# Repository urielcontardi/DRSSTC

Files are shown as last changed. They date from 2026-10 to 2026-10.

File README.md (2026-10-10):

# oneTeslaTS — esquemático da placa principal

Abra `oneTesla.kicad_pro` no KiCad 10 e depois o editor de esquemas, ou abra diretamente `oneTesla.kicad_sch`. A folha A3 contém a placa principal completa, organizada em cinco blocos compactos. Os capacitores de desacoplamento ficam junto aos respectivos CIs; referências e valores usam fonte de 1,27 mm, espaçamento de 2,54 mm e alinhamento consistente. Os valores visíveis foram abreviados (por exemplo, `3R3`, `1u` e `100u 25V`); encapsulamentos e observações de montagem permanecem nos campos dos componentes. O UCC37321P usa um bloco retangular com entradas à esquerda, saídas à direita e alimentação/terra acima e abaixo. Para visualizar sem o KiCad, use `output/oneTesla-schematic.pdf`.

O esquema tem 41 referências físicas: IC1–IC4, IC6, FB1, T1, T3, R1–R6, C1–C6, C8–C13, CPR1, D1, D2, D4, Q1–Q2, Z1–Z2, F1, J110, J1, J2, P1, P2 e PS1. A fonte auxiliar original com transformador (T2 + D3 + IC5/78L15 + C7) foi substituída pelo módulo AC/DC **PS1 (HLK-15M15BL, 15V/1A)**, com C13 na saída de 15V; C10 passou a filtrar o rail de 15V e IC6 (78L05) é alimentado por +15V. Z1/Z2 são TVS opcionais, marcados como DNP. J1 corresponde ao J_AC do original; o nome foi adaptado para a anotação do KiCad. J2 representa explicitamente a ligação de proteção PE/chassis que aparece no layout. A placa do SD interrupter externo não faz parte desta etapa. O layout do PCB está documentado na seção **PCB** abaixo.

Todos os símbolos e footprints usados são locais, em `library/oneTesla.kicad_sym` e `library/oneTesla.pretty`. Não é preciso instalar bibliotecas adicionais. Os arquivos SOP existentes foram preservados; IC1 e IC2 foram associados a DIP-14 com soquete, e IC3/IC4 a DIP-8 com soquete, conforme o manual e o layout.

## Referências e decisões

- `misc/schematic_ref.png`: conexões do CT, diodas de proteção, Schmitt triggers, flip-flop, drivers, GDT e meia ponte.
- `misc/layout_ref.png`: encapsulamentos, referências, alimentação e componentes que não aparecem na imagem parcial do esquema.
- `misc/oneTeslaTS_User_Manual.pdf`, páginas 17–23 do arquivo, etapas 4–7: valores, orientação de montagem, alimentação e TVS opcionais. A página 48 identifica o FGA60N65SMD.
- `misc/oneTeslaTS_Parts.pdf`: quantidades, R1 de 1k/5W, resistores bleeder de 100k/0,5W e fusível de 4A. A serigrafia antiga cita 10A; o esquema usa os 4A da lista do kit.
- [TI UCC37321, SLUS504I](https://www.ti.com/lit/ds/symlink/ucc37321.pdf): alimentação 1/8, terra 4/5, enable 3 e saídas 6/7. Os pinos 6/7 foram ligados externamente. O pino 7 mantém o tipo `output`; o 6 é `passive`, pois ambos são pernas da mesma saída. Isso permite ERC sem desabilitar a regra de curtos entre saídas distintas.
- [onsemi FGA60N65SMD](https://www.onsemi.com/pdf/datasheet/fga60n65smd-d.pdf): TO-3P, G1/C2/E3. Footprint horizontal, aba para baixo, passo 5,45mm.
- [Broadcom HFBR-0500ETZ, AV02-3283EN](https://docs.broadcom.com/doc/AV02-3283EN): selecionado HFBR-2521ETZ com OUT1/GND2/VCC3/RL4. RL está em +5V para usar o pull-up interno. Os pinos de retenção 5/8 estão NC conforme essa variante. A cópia local do footprint corrige a numeração do segundo pino de retenção de 6 para 8.

A fonte auxiliar era, na placa original, T2 -> D3 -> C10 -> RAW_DC (+24V), com IC5 (78L15) gerando +15V e IC6 (78L05) gerando +5V. Nesta revisão ela usa o módulo **HLK-15M15BL**: rede AC (pós-fusível, /AC_L_FUSED e /AC_N) -> PS1 -> +15V (C13/C10) -> IC6 (78L05) -> +5V. O rail RAW_DC e o regulador de 15V deixaram de existir.

J110 liga AC_N a DC_MID: fechado para a configuração dobradora de 110V, aberto para 220V. O módulo HLK aceita 85–265VAC, então a mesma placa atende ambas as tensões de rede. A derivação para PS1 fica depois do fusível (topologia /AC_L -> F1 -> /AC_L_FUSED), diferente da placa original, onde o fusível vinha depois da derivação para T2.

GND da fonte isolada, DC_MINUS do barramento de potência e PE são três redes distintas. P1/P2 recebem a bobina primária externa, em série com CPR1 de 68nF/3kV. O fio do primário atravessa o núcleo de T3; os dois pads de T3 são apenas o secundário do CT.

T1 tem pontos de fase nos pinos **1, 3 e 6**: os dois secundários devem gerar tensões gate/emitter opostas. A numeração física e os pares de enrolamentos ainda devem ser confirmados no transformador real. O ERC não verifica polaridade magnética.

## Footprints e pendências

Cada componente tem os campos `Footprint_Status` e, quando necessário, `Assembly_Notes`. A lista completa está em `output/components.csv`.

| Componentes | Situação |
| --- | --- |
| IC1/IC2 | DIP-14, fileiras 7,62mm e passo 2,54mm; soquete conforme original. |
| IC3/IC4 | UCC37321P em DIP-8, fileiras 7,62mm e passo 2,54mm; soquete conforme original. |
| Q1/Q2 | TO-3P-3 horizontal, passo 5,45mm e pinagem do FGA60N65SMD; conferir altura das pernas dobradas em relação ao dissipador. |
| D1/D2 | 1N4148 DO-35 THT; passo selecionado 7,62mm. |
| IC5/IC6 | 78L15/78L05 TO-92, OUT1/GND2/IN3; conferir fabricante/sufixo antes de comprar. |
| FB1 | HFBR-2521ETZ selecionado; conferir o receptor real. Outras variantes HFBR/AFBR podem diferir no pino 4 e nos pinos de retenção. |
| R1–R6, C1–C10, Z1/Z2 | Footprints THT padronizados selecionados; conferir corpo, passo, tensão e potência das peças adquiridas. |
| C11/C12 | 1000uF, tensão nominal selecionada de pelo menos 200V; snap-in D30/P10 proposto. Confirmar diâmetro, passo e altura. |
| D3/D4 | DF005M DIP-4 / KBU6G linear selecionados por formato e especificações da lista; confirmar os códigos reais e a ordem dos terminais. |
| F1 | Clipes 5x20mm selecionados; confirmar o modelo dos clipes e os passos de seus furos. |
| T1/T2/T3 | Footprints personalizados **provisórios**, estimados do layout. Confirmar dimensões, pares de pinos, tensão e fase com as peças. |
| J1/P1/P2/J110/J2 | IEC, terminais e ligação PE com geometria proposta; conferir modelos, fixações, furos e numeração. |
| CPR1 | Footprint personalizado **provisório**, CDE 940C30S68K-F, passo selecionado 57,5mm. Confirmar desenho mecânico da peça. |

A existência de todos os footprints e a correspondência entre números dos pinos e dos pads foram verificadas. Isso **não confirma medidas físicas de peças não identificadas**. Os footprints marcados `CONFIRMAR` e os modelos selecionados da tabela precisam dessa conferência antes de usar o projeto para fabricar uma placa.

## Componentes de alimentação adicionados

Disponíveis no seletor de símbolos da biblioteca local `oneTesla`, com footprint associado:

| Símbolo | Footprint local | Pinagem |
| --- | --- | --- |
| `oneTesla:HLK-15M15BL` | `oneTesla:HLK-15M15BL` | 1/2 AC, 3 −Vo, 4 +Vo; saída 15V/1A. |
| `oneTesla:MUR460C` | `oneTesla:D_SMC` | SMC/DO-214AB; 1 cátodo, 2 ânodo. |
| `oneTesla:SMBJ18A` | `oneTesla:D_SMB` | SMB/DO-214AA; TVS **unidirecional**, 1 cátodo, 2 ânodo. |
| `oneTesla:1N5819` | `oneTesla:D_SMA` | Versão SMD SMA/DO-214AC; Schottky, 1 cátodo, 2 ânodo. |

O HLK segue a página 11 do [datasheet Hi-Link 15W-BL V1.0](misc/HLK-15W-BL_V1.0.pdf), disponibilizado na [página do componente na LCSC](https://www.lcsc.com/product-detail/C53122331.html). O desenho do fabricante usa **47,5 × 28,5 × 22mm como referência do módulo com caixa da mesma série**. O footprint reserva esse envelope para a versão BL de placa aberta; inclui serigrafia, contorno de fabricação, courtyard e indicação do pino 1. Furos de 1,1mm conforme o desenho, para terminais de 0,8mm ±0,2mm; pads de 2,5mm são uma escolha de layout. O courtyard tem margem de 1mm em torno do envelope nominal.

Coordenadas dos pads em mm, **vista superior da PCB**, com origem no pino 1:

| Pad | X | Y | Função |
| --- | --- | --- | --- |
| 1 | 0 | 0 | AC |
| 2 | 0 | 7,8 | AC |
| 3 | 42,5 | −7,4 | −Vo |
| 4 | 42,5 | 15,2 | +Vo |

São 42,5mm entre colunas, 7,8mm entre os terminais AC e 22,6mm entre os terminais DC. O fabricante informa tolerância de **±1mm nas dimensões e no espaçamento dos pinos** e pede conferência com a peça real antes de desenhar a placa; conferir especialmente a furação antes de fabricar.

Os três footprints SMD são cópias dos padrões do KiCad 10, com faixa de cátodo junto ao pad 1. Referências: [MUR460C World, SMC/4A/600V](https://www.worldgj.com/uploads/file/20251222/988858e88ba65bb483179d9af14a7299.pdf), [SMBJ18A AOS, SMB/18V/600W](https://www.aosmd.com/products/tvs/high-power-tvs/smbj18a), [1N5819 KEXIN, SMA/1A/40V](https://datasheet.lcsc.com/lcsc/1912111437_KEXIN-1N5819_C437199.pdf). Conferir o encapsulamento do fornecedor escolhido. O SMBJ18A usa o gráfico de TVS unidirecional; não o de TVS bidirecional dos componentes com sufixo CA.

Pré-visualizações SVG dos quatro símbolos e footprints, exportadas pelo KiCad, e conferência de pinos/pads estão em `output/power-components/`. O gerador do esquema inicial preserva esses quatro símbolos ao recriar a biblioteca.

## Verificação

`output/validation.txt` contém o resultado; `output/erc.json` é o relatório nativo do KiCad. A verificação cobre 20 redes de referência e sete conexões diretas, entradas/saídas livres, separação dos três domínios, todas as unidades dos CIs e correspondência completa dos pinos/pads. O ERC termina com **2 notas esperadas**: `power_pin_not_driven` nos pinos 1/2 do PS1 — os pinos AC do módulo HLK são `power_input` e a rede AC não tem pino `power_output` dirigindo; é inerente à troca pelo módulo e não indica erro de conexão.

Para repetir as verificações depois de editar o esquema:

```sh
kicad-cli sch export netlist oneTesla.kicad_sch -o output/oneTesla.net
kicad-cli sch erc oneTesla.kicad_sch -o output/erc.json --format json
python3 scripts/validate_schematic.py
kicad-cli sch export pdf oneTesla.kicad_sch -o output/oneTesla-schematic.pdf
```

`python3 scripts/build_schematic.py` recria o esquema inicial desta entrega e as bibliotecas locais, **sobrescrevendo edições posteriores nesses arquivos**; não o execute para apenas validar. O esquema anterior a esta reconstrução permanece no histórico do git.

## PCB

`oneTesla.kicad_pcb` é uma **réplica de 2 camadas** da placa driver original do oneTeslaTS, adaptada ao esquemático atual (fonte HLK, PE separado, PRE/CLR do 74HCT74 em +5V). A geometria vem dos arquivos Eagle originais publicados pelo autor (`misc/driver.brd`, de [bayley/oneteslats](https://github.com/bayley/oneteslats)): posições e rotações dos componentes, trilhas, vias, pours, outline (106,045 × 106,045 mm), furos e a serigrafia vetorial (logo oneTeslaTS, avisos) foram importados diretamente do `.brd`. As redes do cobre original foram reatribuídas às redes do esquemático atual via os contactrefs (pino a pino); o alinhamento de cada footprint foi verificado automaticamente (pad contra pad, rede contra rede, desvio máximo 0,04 mm).

**Adaptações em relação à placa original**

- Fonte auxiliar: T2, D3, IC5 (78L15) e C7 removidos com o cobre associado (+24V, AUX_AC1/2 e o ramal GND/PE da área). **PS1 (HLK-15M15BL)** ocupa o antigo lugar do T2, com os pinos AC à direita; C13 ocupa o antigo lugar de C7 (cada pad no seu pour: +15V e GND). Roteamento novo: /AC_L_FUSED e /AC_N até o PS1, +15V do PS1.4 subindo pela borda esquerda até C10/IC6.3 e ao pour dos drivers, GND do PS1.3 ao pour lógico.
- **PE separado de GND**: o fio original IEC.G→GND e o pad de canto superior direito foram separados; J2 (Chassis_PE_M3) fica no pad de canto (era o ponto de aterramento original) e um fio /PE novo liga J1.3 ao J2. O standoff U$13 (co-localizado com J2) foi omitido.
- **Primário**: P1 (pad direito, como na serigrafia original) = nó CPR1.2; P2 (pad esquerdo) = /DC_MID. Os anéis JPRT originais foram mantidos como terminais (JPRT1 em /DC_MID, JPRT2 no nó CPR1.2). As trilhas de fundo entre P1/P2/CPR1/JPRT foram refeitas para a nova topologia (o fio SW_NODE da CPR1.1 foi preservado; um salto por vias leva /DC_MID de P2 ao anel).
- **74HCT74**: na placa original, os pinos 10 e 13 (PRE/CLR) estavam em GND; no esquemático atual estão em +5V — dois links novos ligam IC2.13 e IC2.10 à rede de +5V.
- **Fusível**: as garras internas (tangs) ganharam jumpers do mesmo net dos clipes (na original eram ilhas sem net).
- GND de T3 confirmado no ramal original do CT; IC6.2 ligado por fio ao C9.2 (o bolsão do pour ficava isolado).

**Footprints**: a biblioteca local foi alinhada à geometria comprovada da placa original (`scripts/pcb_patch_footprints.py`): passos/posições de pads de R1, R5/R6, C8/C9/C10/C13, C11/C12, Z1/Z2, CPR1, T1 (GDT), FB1, J1 (IEC), F1 (ordem dos clipes), D4 (ordem dos pinos AC), P1/P2, J110, IC6 (TO-92 triangular), DIP-8/DIP-14 (pads padrão 1,6 mm, não long pads), furos NPTH de retenção do FB1 e do TO-3P. As notas `CONFIRMAR`/`PROVISORIO` continuam valendo — os footprints espelham a placa original, o que não confirma as peças compradas.

**Verificação do PCB** (`output/drc.json`): **0 itens não conectados**. Restam, por escolha consciente: `hole_clearance` ×2 e `copper_edge_clearance` ×1 presentes na geometria original (trilha /AC_L sobre o furo do IEC, trilha /OPTICAL_OUT junto ao furo de retenção, pad J2 a 0,2 mm da borda); 3 ilhas same-net no pour SW_NODE (slivers que o preenchimento original também gera); e ruído cosmético esperado (silk sobre cobre nos logos, courtyards sobrepostos, `lib_footprint_mismatch` por os footprints embutidos levarem Reference/Value reais).

**Mecânico — conferir antes de fabricar**: o envelope do HLK no footprint é o da série com caixa (47,5 × 28,5 mm); na posição atual a lateral do módulo fica a ~0,2 mm dos pads de solda do conector IEC. Medir o módulo BL real (provavelmente ~44 × 24 mm) e, se necessário, deslocar PS1 ~1 mm para dentro. A versão BL de placa aberta não deve ultrapassar os pads do IEC.

**Regenerar o PCB do zero** (sobrescreve `oneTesla.kicad_pcb`):

```sh
python3 scripts/pcb_patch_footprints.py   # alinha a biblioteca à geometria original
python3 scripts/pcb_extract.py            # componentes/redes do esquemático -> output/pcb-data.json
python3 scripts/build_pcb.py              # gera o .kicad_pcb (placement verificado + cobre)
/Applications/KiCad/KiCad.app/Contents/Frameworks/Python.framework/Versions/Current/bin/python3 scripts/pcb_refill.py oneTesla.kicad_pcb
kicad-cli pcb drc oneTesla.kicad_pcb -o output/drc.json --format json
```

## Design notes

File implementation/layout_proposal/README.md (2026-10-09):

# Estudo de posicionamento — NÃO fabricar

Este diretório contém uma proposta mecânica **não roteada** para a placa `oneTesla`. A fonte de produção continua sendo `../../oneTesla.kicad_pcb`, sem alterações neste commit. Não exportar Gerbers do estudo nem energizá-lo.

## Entregáveis

- `placement-study.kicad_pcb`: 19 footprints reposicionados e contorno expandido de modo provisório para `(-7,-18)` a `(185,155)` mm. A topologia dos pads no arquivo e os segmentos/vias originais foram preservados; as trilhas **não acompanharam** os pads movidos.
- `assembly.png`: inspeção visual do novo agrupamento. O arquivo do PCB, não a imagem, é a referência geométrica.
- `placement_study.py`: geração reproduzível a partir da fonte da raiz. O script restaura explicitamente as redes serializadas das trilhas por UUID após salvar, pois o pcbnew 10 reassocia sete delas ao mover footprints.
- `drc-placement-study.json`: DRC nativo do KiCad 10.0.6 com paridade, todas as severidades, erros de trilha e refill de zonas, usando cópia do esquema, projeto e bibliotecas locais. A execução do DRC não salvou o PCB do estudo.

## Resultado verificado

| Checagem | Fonte atual | Estudo |
|---|---:|---:|
| Footprints/pads | 48 / 142 | 48 / 142 |
| Segmentos e vias / zonas | 220 / 6 | 220 / 6 |
| Courtyards sobrepostos no DRC | 22 | 0 |
| Violações totais do DRC | 84 | 130 |
| Itens sem conexão | 0 | 34 |
| Curtos | 0 | 10 |
| Paridade esquemático-PCB | 2 | 2 |

O DRC do estudo inclui 74 sobreposições de silk, 23 pontas de trilha soltas, 10 pontes de máscara entre redes, 7 violações de distância a furos, 3 furos NPTH dentro de courtyards, 1 clearance de cobre, 1 silk sobre cobre e 1 ilha de cobre. Os 2 itens de paridade são os `JPRT1/JPRT2` já presentes na fonte; o ERC anterior da fonte aponta 2 `power_pin_not_driven` em PS1. Os três NPTH remanescentes são H2/H4 na área de Q1/Q2 e H3 na área de PS1: podem ser furos de fixação intencionais e não devem ser deslocados sem validar a montagem.

## Bloqueios para substituir o PCB da raiz

1. Rerotear as conexões dos 19 footprints movidos, eliminar os curtos, limpar as 34 desconexões e repetir refill/DRC. O cobre antigo sobre pads novos é o principal risco elétrico imediato.
2. Confirmar contorno, fixações, dissipadores e envelopes físicos da placa e do gabinete. A ampliação é uma hipótese de espaço, não especificação mecânica aprovada.
3. Confirmar os PNs/footprints ainda provisórios listados em `../COMPONENTES_E_FONTES.md`, especialmente IEC, clipes, capacitores C11/C12, transformadores e terminais. O furo de 2,2 mm do CAD para `Primary_Terminal_M6` não comprova compatibilidade com terminal M6.
4. Após roteamento, repetir ERC, exportar e comparar netlist, executar DRC com paridade e `--refill-zones --save-board`, verificar isolamento/correntes e inspecionar visualmente cobre, máscaras, montagem e bordas. Apenas DRC zerado não libera fabricação ou operação de alta tensão.

## Reprodução da checagem

O PCB do estudo precisa ser copiado com nome `oneTesla.kicad_pcb` para uma pasta de teste contendo `oneTesla.kicad_pro`, `oneTesla.kicad_sch`, `fp-lib-table`, `sym-lib-table` e `library/` da raiz. No KiCad 10.0.6:

```sh
kicad-cli pcb drc --all-track-errors --schematic-parity --severity-all --refill-zones --format json -o drc.json oneTesla.kicad_pcb
```

O relatório anterior da fonte está em `../cleanup/drc-current.json`; não se trata de um DRC novo da fonte neste estudo.

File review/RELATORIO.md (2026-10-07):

# Auditoria independente DRSSTC / oneTeslaTS

Data: 07/10/2026. Fonte: commit **f4da80c517a5edeefd3d4267e3aca7924727bbe4**.
Repositório: https://github.com/urielcontardi/DRSSTC. Clone recuperado da execução anterior, inicialmente limpo; nenhum arquivo de projeto alterado. Artefatos desta auditoria somente em review/. Sem push/PR.

## Parecer

**Não liberar esta revisão para fabricação ou energização.** A suspeita de layout ruim procede, mas não se resume a estética: há um footprint comprovadamente incompatível com o componente selecionado (FB1), perda sistemática de coerência mecânica ao adaptar pads de outro projeto, capacitores D30 que não cabem lado a lado e distâncias rede–PE submilimétricas. “Zero não conectados” é verdadeiro, porém não significa placa correta ou segura.

O problema central é tratar o cobre da placa antiga como referência mecânica definitiva. O script scripts/pcb_patch_footprints.py, linhas 4–5 e 116 em diante, declara e implementa a troca de pads mantendo silk/fab/courtyard. Esses desenhos **não são apenas cosméticos**: representam corpo, polaridade, montagem e exclusão mecânica. Também houve troca de componente real, particularmente IFD95 → HFBR, sem trocar a geometria correspondente.

## Escopo, método e limites honestos

- 166 arquivos originais versionados inventariados com SHA-256 em inventario.csv.
- 2 placas: oneTesla.kicad_pcb e misc/driver.brd (Eagle original).
- 5 esquemas KiCad: principal, revisado e três snapshots misc; mais misc/driver.sch Eagle.
- PCB atual: **48 instâncias de footprint**, sendo 41 referências do esquema + JPRT1/JPRT2 + 5 furos sem referência; 205 segmentos, 7 vias, 6 zonas; 2 camadas, espessura declarada 1,6 mm, contorno ~106,045 mm quadrado.
- **135 arquivos .kicad_mod**: 31 oneTesla e 104 Resistor_THT. 24 modelos locais usados pelo PCB; 111 não usados (7 oneTesla + 104 resistores), separados em cobertura-bibliotecas.csv. Três nomes de footprints adicionais existem apenas embutidos no PCB (furos e anéis).
- Eagle: 51 elementos inventariados individualmente em cobertura-eagle.csv; importação nativa KiCad, DRC e inspeção visual da vista superior executados.
- Cada uma das 48 instâncias tem linha própria em cobertura-pcb.csv, com referência, valor, posição, pads, furação, passos, rede, polaridade, encaixe, courtyard, silk e achados. pads.csv detalha coordenadas locais e absolutas. Todas as 41 geometrias de pads locais/embutidos coincidem após normalizar ordem e números; isso **não valida o desenho do footprint**.
- Usado KiCad **10.0.6**, já instalado na imagem local kicad-web:local. Contêiner descartável, sem rede, projeto montado read-only e apenas review gravável. Não foi iniciado/alterado o desktop KiCad do usuário. DRC com refill apenas em memória, sem --save-board. Não executados geradores destrutivos do repositório.
- Exportações SVG nativas top/bottom/assembly e Eagle convertidas a PNG com librsvg; todas essas vistas foram efetivamente inspecionadas. A serigrafia deslocada, capacitores sobrepostos, linha PE periférica e desvios longos de potência são visíveis nas imagens.
- Datasheets obtidos e comparados: TI UCC37321, onsemi FGA60N65SMD, Broadcom HFBR-0500ETZ, CDE 940; Hi-Link PDF local p11. Não foram inventados MPNs para passivos, conectores ou magnetismos.
- **Não é aprovação completa de cada peça física.** Todos os footprints foram cobertos geometricamente; os 111 não usados não receberam comparação individual com fabricante. Faltam BOM comprável/peças, CAD do dissipador/enclosure, normas aplicáveis e parâmetros elétricos. ERC nativo do esquema Eagle não executado; DRC do Eagle é sobre importação, não validação no Eagle. Não há Gerbers/Excellon/STEP/BOM de produção versionados para auditar um lote de fabricação.

## Resultados nativos reproduzidos

### PCB atual

DRC: **529 violações + 56 questões de paridade, 0 itens não conectados**. Total: 87 erros e 498 avisos.

| Classe | Quantidade |
|---|---:|
| silk_overlap / silk_over_copper | 199 / 199 |
| courtyards_overlap | 45 |
| pth_inside_courtyard / npth_inside_courtyard | 34 / 5 |
| hole_clearance / copper_edge_clearance | 2 / 1 |
| silk_edge_clearance | 14 |
| lib_footprint_mismatch / lib_footprint_issues | 23 / 7 |
| paridade: campo Footprint_Status ausente | 41 |
| paridade: extras / refs vazias duplicadas | 7 / 4 |
| paridade: FB1 pinos 5/8 sem pads elétricos | 2 |
| paridade: Z1/Z2 DNP divergente | 2 |

Os 23 mismatches não devem ser descartados em bloco nem interpretados como 23 pinagens erradas: os pads conferem nas 41 referências. Há diferenças de propriedades/gráficos. As colisões courtyard incluem artefatos do desenho deslocado e problemas reais de corpo — precisam ser corrigidas, não silenciadas indiscriminadamente. A execução atual não reproduziu os três slivers mencionados no README.

### Esquemas

- oneTesla: 2 power_pin_not_driven em PS1.1/2. Alimentação AC não tem power_output; não é validação de isolamento ou fusível.
- oneTesla-revisado: 0 ERC, mas **não é esquema equivalente ao PCB**: ainda tem T2/D3/IC5/C7 e RAW_DC; IC1.12 está NC e IC2.1 recebe RESET_MIX diretamente. No principal, IC1.12 dirige IC2.1. Esta é diferença de função, não só nomes.
- before-compact e saved-old-copy: 132 ERC cada (principalmente bibliotecas/links não resolvidos).
- before-replication: 84 ERC, incluindo 35 pinos não conectados, 11 não dirigidos, 9 alimentações não dirigidas. Não presumir que snapshots sejam fabricáveis.

As netlists nativas estão em evidence/*.net; netlist-differences.json lista diferenças de nomes/pinos e também renomeações que não são alterações topológicas. Comparação pad→net do PCB atual com o esquema principal: nenhum conflito entre os pads presentes. FB1.5/.8 deliberadamente viraram NPTH sem numeração, permanecendo o aviso de paridade.

### Eagle original

Importação em evidence/eagle-import.kicad_pcb, não substituir a fonte. DRC da importação: 180 violações, 0 não conectados. Inclui 12 hole_clearance, 9 shorting_items, 4 hole_to_hole, 2 copper_edge_clearance, 1 clearance. Vários “curtos” são objetos NPTH sem rede após importação, e furos duplicados do dissipador; **não afirmar nove curtos físicos independentes**. Mesmo assim, demonstra que copiar a geometria antiga não elimina problemas. A vista nativa evidencia eletrolíticos EB25D e receptor IFD95, diferentes dos modelos nomeados atualmente.

## Achados priorizados

### F01 — P0 fabricação: FB1 não é footprint HFBR-2521ETZ

Evidência: scripts/pcb_patch_footprints.py **39–45**, que usa explicitamente IFD95 e “RL pad4 best-guess continuation”; cobertura-pcb.csv FB1; Broadcom AV02-3283EN p4/p11.

- Footprint elétrico tem passo **1,905 mm**, quatro pads na ordem espacial **3–1–2–4**.
- Desenho Broadcom: terminais em **2,54 mm**; corpo/retenções também precisam seguir a variante correta.
- Os nomes 1 OUT / 2 GND / 3 VCC / 4 RL estão coerentes no esquema, mas isso não corrige as coordenadas físicas. Pinos 5/8 são retenções e não devem ser conectados eletricamente segundo o fabricante.
- Local: FB1 origem (10,160; 63,500) mm. A placa pode estar perfeita em netlist e receber o componente errado ou não aceitar inserção.

Correção proposta: decidir se a peça será HFBR-2521ETZ ou IFD95 real; usar desenho exato e então reposicionar/rerotear, não deformar footprint para caber no cobre antigo.

### F02 — P0 fabricação: pads modificados, corpos/polaridades/nomes não acompanhados

Evidência direta: scripts/pcb_patch_footprints.py 17–30, 35–45, 74–105; gráficos efetivos em assembly.png e arquivos locais.

- **R1:** nome/corpo axial L25 P30,48; pads agora em ±11,43 (pitch **22,86**). F.Fab continua de x2,74 a27,74, centro15,24, enquanto par de pads está centrado em0. Corpo25 é maior que distância22,86 entre furos: não serve como montagem axial horizontal convencional daquela peça. Não é apenas erro de texto.
- **R5/R6:** nome P12,70, pads P10,16, corpo não recentrado.
- **C8/C9/C13:** nome P3,50, pads P2,54, círculo permanece centrado x1,75. **C10:** nome P5, pads P3,556, círculo centrado x2,5. Valor real de C10 no esquema/PCB é 680u 35V, mas texto legado de fabricação mostra 100u 10V; não comprar pelo texto velho.
- **C11/C12:** nome P10, pads P10,16 centrados em0, círculo permanece centrado x5. A faixa de polaridade/courtyard desloca junto, tornando montagem enganosa.
- **P1/P2:** chamados “M6”, mas furo **2,2 mm**, pad4: corresponde à intenção de soldar fio, não passagem de parafuso M6. Definir terminal e esforço mecânico; apagar envelope genérico não resolve retenção.
- **T1:** footprint genérico tem courtyard local x±7; pads em x−9,017 e +8,763 ficam fora dele. Corpo e posição não descrevem o transformador real.
- **F1:** pads recentrados em ±5,08/±10,16, mas desenho do clipe permanece no sistema antigo. Não comprova montagem Littelfuse citada no nome.
- **IC6:** nome TO-92_Inline, pads triangulares. Confirmar fabricante/sufixo 78L05, vista, pinagem e conformação; não assumir todos os 78L05 idênticos.
- **D4:** nome Vishay KBU, porém pads seguem GBU4S antigo. AC2/3 permutados não é por si só defeito elétrico; o modelo mecânico exato continua pendente.

Restaurar footprints a partir das peças, incluindo fab/courtyard/polaridade, só depois refazer placement. Renomear geometrias personalizadas para não se passarem por padrões KiCad.

### F03 — P0 fabricação: C11 e C12 D30 não cabem

Origens/pontos médios dos pads (92,710;31,750) e (66,675;31,750): distância **26,035 mm**. Corpos declarados Ø30 deixam sobreposição nominal **3,965 mm**, mesmo corrigindo o deslocamento de5 mm. O desenho atual de C11 chega x112,710, além da borda106,045. Se o corpo fosse recentrado nos terminais, ainda chega x107,710. O Eagle original usa **EB25D**, não D30.

Não diagnosticar automaticamente que peças físicas já compradas colidem: MPN não fornecido. Diagnóstico certo é que **os corpos especificados pelos footprints atuais são incompatíveis com placement**. Escolher capacitor de diâmetro/tensão/ripple adequados ou aumentar espaçamento; não reduzir círculo para calar DRC sem selecionar peça real.

### F04 — P0 rede: cobre invade furo de J1

DRC hole_clearance: **0,0000 mm** entre /AC_L F.Cu (segmento de74,930;3,810 a53,975;3,810, largura2,54) e NPTH J1 centro **(59,205;6,071), Ø3 mm**. A distância geométrica centro-linha2,261 menos raio1,5 menos meia-largura1,27 resulta −0,509 mm: cobre entra no envelope de furação. Não é aceitável apenas por estar no original; pode ser removido pelo furo ou exposto ao fixador.

Segundo problema: FB1 retenção em(2,540;66,040), /OPTICAL_OUT: **0,2413 mm** versus regra0,25. Menor gravidade que J1, mas precisa ajuste de footprint correto primeiro.

### F05 — P0 segurança: domínio PE inadequadamente tratado

Medições de bordas de segmentos coplanares, não de máscara, registradas em clearance-samples.txt:

- **/AC_L_FUSED–PE =0,290 mm** em B.Cu, junto a(95,25;3,81), PE de(93;2) a(99,5;2).
- **/AC_L–PE =0,440 mm** em F.Cu: rede em y3,81, PE em y1,85.
- PE tem aproximadamente **88,58 mm** somados de trilhas, largura **0,5/0,6 mm**, duas vias Ø0,6 (pads1,3) em(93;2) e(99,5;2).
- J2 pad de PE em(102,362;2,7559), cobre a **0,2059 mm** da borda; regra do projeto exige0,5.

Essas distâncias são fatos de geometria e motivo para **bloquear liberação**, não uma certificação numérica de uma norma específica. Dimensionamento de clearance/creepage depende da tensão de trabalho e transientes, categoria de sobretensão, poluição, CTI/material, altitude, coating e norma do produto. PE precisa suportar falta e esforços mecânicos até a proteção atuar; I²t do fusível/rede e espessura de cobre não estão definidos. Separar nets PE/GND não prova proteção. Recomenda-se bonding de chassis dedicado robusto e arquitetura de aterramento explicitamente projetada, em vez de depender desta linha/vias sem qualificação.

### F06 — P1 desempenho/robustez: loop primário longo e gargalos

- P2 → DC_MID contorna a borda inferior, sobe pela direita até C11/C12, com trilhas2,54 mm. A soma de todos os segmentos DC_MID é231,8 mm (inclui ramificações; **não equivale ao comprimento de um único loop**).
- Há troca de camada através de **uma via Ø0,6 por transição**, em(84;97,045) e(94;97,045), trecho F.Cu10 mm entre elas. Isso participa do caminho de corrente do primário e exige dimensionamento; não inferir capacidade em ampères sem cobre/plating/ondas/duty.
- CPR1.2/P1 possui75,63 mm somados de trilhas2,54. O retorno do tanque não segue de perto toda a ida. Risco de indutância parasita, overshoot e emissão, qualitativo; não foi calculado nH nem simulada corrente.
- Gates H/L têm trilhas **0,4064 mm** e comprimentos aproximados26,18 /21,66 mm; retornos pelos nós emitter/pours não constituem par estreito/Kelvin demonstrado em toda extensão. O SW_NODE tem área de cobre extensa perto dos secundários do GDT; considerar capacitância parasita e ruído de modo comum.
- C5/C6 e C8/C13 ficam próximos dos drivers, aspecto positivo; mas TI pede capacitor de baixo ESR/ESL entre VDD8/PGND5 e separado entre VDD1/AGND4, ligação AGND–PGND curta/larga. A escolha THT1u + eletrolítico e soquete não comprova a impedância de pulso requerida. Não afirmar instabilidade sem medição.
- Z1/Z2 são TVS entre coletor/emissor, **não clamps gate-emitter**. Confirmar VGE ±20 V, overshoot, saturação do GDT, deadtime/fase e corrente máxima em ensaios limitados antes de barramento pleno.

Reorganizar primeiro o loop C11/C12–meia ponte–CPR1–primário, encurtar retorno e evitar vias únicas de potência. Selecionar stackup/cobre e calcular perdas RMS/pulsadas; só então fixar larguras/vias.

### F07 — P1 mecânica: PS1/IEC/fixações e tolerâncias

PS1(44,25;22), rot180°, envelope de referência47,5×28,5; desenho Hi-Link local p11 confirma42,5 entre colunas,7,8 AC,22,6 DC e funções1/2 AC,3−Vo,4+Vo. Orientação adotada é coerente com a vista superior.

Porém o envelope é explicitamente referência da série com caixa; não prova BL adquirido. Courtyard conflita J1 e furo de canto(3,8735;2,3495). Borda direita nominal x46,75 coincide quase com extremidade do pad L de J1 x47,205; a geometria exata merece controle 3D, não a hipótese “BL provavelmente menor”. Furo1,1 para terminal0,8±0,2 deixa pouca folga no extremo; tolerância dimensional/pitch±1 mm do fabricante demanda amostra/gabarito. Arruelas/standoffs não podem invadir placa aberta do módulo.

Q1/Q2: passo5,45 confirmado onsemi; terminal máximo1,2×0,75 tem diagonal~1,415 mm versus furo1,4986 nominal (margem diametral~0,084 antes de tolerâncias de furo/acabamento). Pode montar, mas precisa tolerância real. Fab15,5 mm de largura é menor que máximo16,2 do corpo. Furo do dissipador é objeto separadoØ5,5; centro está~0,4405 mm afastado do centro de furo representado no F.Fab após transformação. Validar dobra, plano de apoio, isoladores, parafusos/torque e dissipador, não só pitch.

### F08 — P1 documentação/produção: DNP e múltiplas fontes contraditórias

Z1/Z2 DNP no esquema, não DNP no PCB. Os 41 campos Footprint_Status ausentes do PCB perdem os avisos na passagem para montagem. Sete footprints extras não têm biblioteca/símbolo; cinco referências vazias dão quatro avisos de duplicidade, **não cinco componentes sobrepostos no mesmo ponto**. Bibliotecas e arquivos “revisado” têm que receber uma definição inequívoca de qual revisão é vigente. README contém valores/passos antigos (CPR1 citado57,5, real58,42; C10 texto antigo etc.). Corrigir após decisão técnica, sem simplesmente apagar histórico.

## Avaliação elétrica e térmica condicionada

Topologia atual coerente no nível de nets: fusível em L antes de PS1/ponte; J110 conecta N ao ponto médio para dobrador; capacitores C11/C12 em série; CPR1 em série com primário P1/P2; T3 é secundário CT; lógica isolada GND, DC_MINUS e PE são nets distintas. UCC37321 OUT6/7 e VDD1/8 unidos, G1/C2/E3 IGBT corretos. Fase do GDT **não verificada** por ERC/netlist.

Não há regra HV específica: oneTesla.kicad_pro linha143 min_clearance0, linha498 clearance Default0,2 mm, linha521 sem padrões de netclass. Zonas de potência têm clearance0,6096 e lógica0,4. Não há budget de isolamento/creepage por domínio. Assim DRC sem erros de clearance **não prova isolamento de rede**. Medições acima são amostras só de segmentos retos, não mínimo global pad/pour ou caminho 3D.

Para C11/C12 1000u/200V, tensão nominal por capacitor no dobrador depende da rede e tolerância/balanceamento; não tratar “110” como equivalente a qualquer tensão127/alta linha sem cálculo. R5/R6 100k0,5W: a200V dissipa0,4W cada, pouca margem térmica; tau nominal RC=100s por capacitor, tensão residual depende de tensão inicial e tolerância/falha do bleeder. “Esperar5min” impresso não substitui medição e procedimento seguro de descarga.

IC6 perde aproximadamente(15−5)×I5V; sem carga exata/ambiente não concluir temperatura aceitável. F1 precisa tipo rápido/lento, I²t, capacidade de interrupção e rating da fonte de rede, não só4A250V. Ponte D4, capacitores ripple e dissipador não dimensionados no repo. Q1/Q2 ratings de datasheet não são garantia de capacidade da bobina. CDE940C30S68K-F confirma corpo46×19, fio1 mm,3000Vdc/500Vac da série; o pitch58,42 é dobra escolhida. Limites AC, frequência, dV/dt e corrente RMS devem ser conferidos para onda real, não deduzidos do “3kV”.

## Footprints não usados

Os sete oneTesla não usados são enumerados em cobertura-bibliotecas.csv (uso NÃO USADO): SOP14, DIP8 sem soquete, EI30, ponte DIP4 e diodos SMA/SMB/SMC. São reserva de biblioteca, não falhas de placement atual. Os nomes MUR460C/1N5819 genéricos não autorizam troca automática entre THT/SMD; fabricante/sufixo da compra tem que definir encapsulamento. Os104 resistores Resistor_THT receberam inventário de pads/furos/courtyard/silk/fab, **não homologação individual contra fabricantes**. Não foram modificados.

## Ordem recomendada de correção — nenhuma aplicada nesta auditoria

1. Congelar esquema principal e BOM com MPN, datasheet e peça real de magnetismos/conectores/soquetes/capacitores/fusível.
2. Corrigir FB1 e todos os footprints alterados por matching de cobre; reconstruir corpo, pad1, polarity, courtyard e 3D coerentes. Conferir impressão1:1 com peças.
3. Rever dimensões da placa/placement C11/C12, PS1/J1, dissipadores e terminais. Resolver colisões reais antes de silk.
4. Definir rede/PE/bonding e regras HV segundo ambiente/norma; refazer J1 e separações rede–PE, incluindo caminho de falta.
5. Refazer loops de potência e gates com retorno próximo; dimensionar cobre/vias a partir de corrente/pulsos e limite térmico.
6. Sincronizar DNP/campos/referências extras, remover ambiguidades históricas do fluxo de fabricação; gerar Gerber/drill/BOM/assembly somente após aprovação.
7. Reexecutar DRC/ERC/paridade e conferir CAM independente. Depois testes de bancada progressivos de baixa energia e instrumentação apropriada por profissional habilitado. Auditoria CAD não autoriza energização de DRSSTC.

## Evidências e reprodução

Arquivos centrais: cobertura-pcb.csv, cobertura-bibliotecas.csv, cobertura-eagle.csv, pads.csv, drc-itens.csv, inventario.csv. evidence/drc.json conserva posições e UUIDs; evidence/top.png, bottom.png, assembly.png, eagle-top.png são vistas inspecionadas. PDF/fontes externas podem ter copyright; guardadas para rastreabilidade técnica, não redistribuídas remotamente.

Com KiCad10.0.6:

```sh
kicad-cli pcb drc oneTesla.kicad_pcb -o review/evidence/drc.json --format json --all-track-errors --schematic-parity --severity-all --refill-zones
kicad-cli sch erc oneTesla.kicad_sch -o review/evidence/erc-oneTesla.json --format json
kicad-cli sch export netlist oneTesla.kicad_sch -o review/evidence/oneTesla.net
PYTHONDONTWRITEBYTECODE=1 python3 review/audit.py
PYTHONDONTWRITEBYTECODE=1 python3 review/annotate.py
```

Não usar --save-board nem scripts/build_* / pcb_patch_footprints.py para apenas validar. Os scripts de auditoria são auxiliares de inventário; DRC/ERC/netlists vêm do KiCad, não de parser caseiro. O leitor sexpr existente só complementou medidas/CSV depois da descoberta e uso das ferramentas nativas.

Fontes primárias acessadas em07/10/2026:
- https://docs.broadcom.com/doc/AV02-3283EN (p4 mecânica e p11 HFBR25x1, evidence/hfbr.pdf)
- https://www.ti.com/lit/ds/symlink/ucc37321.pdf (pinagem, layout e PDIP P, evidence/ucc37321.pdf)
- https://www.onsemi.com/pdf/datasheet/fga60n65smd-d.pdf (CASE340BZ, evidence/fga60n65smd.pdf)
- https://www.cde.com/resources/catalogs/940C.pdf (940C30S68K-F, evidence/cde940.pdf)
- misc/HLK-15W-BL_V1.0.pdf p11 (evidence/hlk-mechanical.png)
- Tentativa Vishay KBU não recuperou PDF; não considerada validação.

## Fechamento da retomada e bloqueio da homologação completa

A retomada preservou o clone e os artefatos anteriores. Foram reinspecionadas as quatro vistas PNG (topo, fundo, montagem e Eagle), o desenho mecânico Broadcom e as tabelas de medidas. DRC e ERC do principal foram repetidos em contêiner sem rede, projeto somente leitura: **529 violações, 56 questões de paridade, 0 não conectados; ERC 2**. Resultados: evidence/drc-recovery.json e evidence/erc-recovery.json. Os SHA-256 dos **166 arquivos originais** continuam idênticos a inventario.csv.

A anotação individual escrita mas ainda não executada foi aplicada: cobertura-pcb.csv contém conclusões específicas para todas as referências, também legíveis em COBERTURA.md. checagem-bibliotecas.csv acrescenta checagens básicas de anel nominal, presença de F.Fab/F.CrtYd para **135/135 modelos**, incluindo os não usados. Isso não substitui comparação com uma peça.

### Matriz de encerramento honesto

| Item solicitado | Executado | O que impede aprovação completa |
|---|---|---|
| PCB KiCad atual | DRC/paridade, geometria 48/48, netlist, inspeção das duas faces/montagem | Achados F01–F08; MPNs e tolerâncias ausentes |
| Eagle legado | Inventário 51/51, importação KiCad, DRC e vista superior | Sem ERC/DRC no Eagle original; peças legadas não homologadas individualmente |
| Bibliotecas | Inventário e checagens básicas 135/135; 24 modelos usados com análise por referência | 111 modelos não usados sem associação exata a peças; não é possível verificar datasheet de componente não selecionado |
| Esquemas KiCad | ERC dos cinco arquivos e comparação das netlists | Revisões divergem funcionalmente; designar fonte de fabricação |
| Isolação HV/PE | Geometria e falhas locais identificadas | Rede máxima, transientes, norma, altitude, poluição, CTI/coating e bonding sem especificação suficiente |
| Corrente, comutação e temperatura | Caminhos, vias, loops e riscos qualitativos | Frequência, corrente de pico/RMS, duração/repetição dos pulsos, cobre/plating, ambiente e dissipador |
| Mecânica final | Envelopes e conflitos CAD | MPNs, amostras, tolerâncias da fábrica, magnetismos e conjunto dissipador/enclosure |

**Resultado entregue: relatório de revisão CAD com cobertura e bloqueios, não homologação integral de todas as peças.** Para encerrar a parte física solicitada, fornecer BOM comprável (fabricante + código completo + variante), desenhos/bobinagem de T1/T3, modelos dos terminais/IEC/clipes/soquetes, peças C11/C12 e dados operacionais acima. Não escolher substitutos implicitamente. Sem isso, não há base para declarar pinagem/pitch/drill/polaridade de cada peça real confirmados. Nenhum erro encontrado exige energizar a placa para ser demonstrado.

Não foi aplicado patch à placa, ao esquema ou às bibliotecas; não houve push, PR, alteração no Gateway nem certificação de segurança.

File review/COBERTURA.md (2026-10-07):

# Cobertura por referência — PCB atual

48/48 instâncias inventariadas e anotadas. **Cobertura não significa aprovação da peça.** Pinagem, passo e furo estão nos CSV.

| Referência | Valor | Polaridade/pinagem | Encaixe e pendências |
|---|---|---|---|
| C1 | 1u | Não polarizados no símbolo | Disco P5, furos/pads inventariados; dielétrico/tensão/ESL/MPN desconhecidos; C4 deve suportar corrente do GDT |
| C10 | 680u 35V | Pad1 positivo +15 V; valor 680u 35V na fonte, fab mantém texto antigo 100u 10V | Pendente MPN: pitch real 3.556 versus nome 5; corpo/silk deslocados 2.5 mm; F02 |
| C11 | 1000u 200V | Pad1 positivo confere com netlist; serigrafia deslocada 5 mm | REPROVADO envelope D30: centros distam 26.035 mm, sobreposição 3.965 mm; F03. Pitch 10.16, MPN desconhecido |
| C12 | 1000u 200V | Pad1 positivo confere com netlist; serigrafia deslocada 5 mm | REPROVADO envelope D30: centros distam 26.035 mm, sobreposição 3.965 mm; F03. Pitch 10.16, MPN desconhecido |
| C13 | 100u 25V | Pad1 positivo confere; corpo/silk deslocados em relação ao par de pads | Pendente MPN: pitch real 2.54 versus nome 3.50; F02. C9 em +5 V; C8/C13 em +15 V |
| C2 | 1u | Não polarizados no símbolo | Disco P5, furos/pads inventariados; dielétrico/tensão/ESL/MPN desconhecidos; C4 deve suportar corrente do GDT |
| C3 | 1u | Não polarizados no símbolo | Disco P5, furos/pads inventariados; dielétrico/tensão/ESL/MPN desconhecidos; C4 deve suportar corrente do GDT |
| C4 | 1u | Não polarizados no símbolo | Disco P5, furos/pads inventariados; dielétrico/tensão/ESL/MPN desconhecidos; C4 deve suportar corrente do GDT |
| C5 | 1u | Não polarizados no símbolo | Disco P5, furos/pads inventariados; dielétrico/tensão/ESL/MPN desconhecidos; C4 deve suportar corrente do GDT |
| C6 | 1u | Não polarizados no símbolo | Disco P5, furos/pads inventariados; dielétrico/tensão/ESL/MPN desconhecidos; C4 deve suportar corrente do GDT |
| C8 | 100u 25V | Pad1 positivo confere; corpo/silk deslocados em relação ao par de pads | Pendente MPN: pitch real 2.54 versus nome 3.50; F02. C9 em +5 V; C8/C13 em +15 V |
| C9 | 100u 10V | Pad1 positivo confere; corpo/silk deslocados em relação ao par de pads | Pendente MPN: pitch real 2.54 versus nome 3.50; F02. C9 em +5 V; C8/C13 em +15 V |
| CPR1 | 68n 3kV | Não polarizado | CDE 940C30S68K-F: corpo 46x19 e fio 1 mm conferem catálogo; P58.42 é dobra escolhida, não pitch de fábrica; furo1.4; ensaio RMS/dVdt obrigatório |
| D1 | 1N4148 | Pad1 K, pad2 A; netlist coerente clamp inferior/superior | DO35 P7.62 genérico; conferir MPN e faixa de cátodo na montagem |
| D2 | 1N4148 | Pad1 K, pad2 A; netlist coerente clamp inferior/superior | DO35 P7.62 genérico; conferir MPN e faixa de cátodo na montagem |
| D4 | KBU6G | +1, AC2/3, -4; troca entre AC não altera ponte | KBU6G fabricante indefinido; pads seguem GBU4S original P5.08, não confirma KBU escolhido; desenho Vishay não recuperado; F02 |
| F1 | 4A/250VAC | Não polarizado; duas ilhas por terminal compartilhadas corretamente | Pads ±5.08/±10.16, furos1.1938; fab herdado deslocado; clipe Littelfuse exato não comprovado; tipo/I²t/capacidade interrupção pendentes |
| FB1 | HFBR-2521ETZ | 1 OUT, 2 GND, 3 VCC, 4 RL coerentes eletricamente; retenções 5/8 NC | REPROVADO HFBR-2521ETZ: pitch 1.905 versus 2.54 mm datasheet; ordem espacial 3-1-2-4 adaptada de IFD95; F01 |
| IC1 | 74HCT14 | DIP pad1 retangular e numeração padrão; alimentação/netlist conferem | DIP14 P2.54 W7.62; furo0.8128 pad1.6; MPN/sufixo e soquete exatos desconhecidos; LongPads no nome não corresponde ao pad real |
| IC2 | 74HCT74 | DIP pad1 retangular e numeração padrão; alimentação/netlist conferem | DIP14 P2.54 W7.62; furo0.8128 pad1.6; MPN/sufixo e soquete exatos desconhecidos; LongPads no nome não corresponde ao pad real |
| IC3 | UCC37321P | UCC37321: VDD1/8, IN2, EN3, GND4/5, OUT6/7 conferem datasheet e netlist | PDIP8 P2.54 W7.62 coerente; soquete exato pendente; TI recomenda desacoplamento em ambos pares VDD/GND, não comprovado nesta geometria |
| IC4 | UCC37321P | UCC37321: VDD1/8, IN2, EN3, GND4/5, OUT6/7 conferem datasheet e netlist | PDIP8 P2.54 W7.62 coerente; soquete exato pendente; TI recomenda desacoplamento em ambos pares VDD/GND, não comprovado nesta geometria |
| IC6 | 78L05 | OUT1/GND2/IN3 conforme símbolo, fabricante não definido | REVISAR: footprint chamado Inline tem pads triangulares; fabricante/sufixo 78L05 e conformação das pernas obrigatórios |
| J1 | IEC C6 | L1/N2/PE3 lógico; conferir vista e part number real | IEC C6 sem MPN; trilha de rede invade furo mecânico F04; colisão PS1/F1 |
| J110 | Jumper 110V | Não polarizado; AC_N para DC_MID apenas modo110 | P10.16 furo2.2; jumper deve ter corrente/isolação especificados e intertravamento/rotulagem; nunca selecionar fechado em220 |
| J2 | PE/CHASSIS | PE distinto de GND e DC_MINUS | Furo3.2 M3 pad5.1; cobre só0.2059 da borda; resistência/torque/arruela/bonding não definidos; F05 |
| JPRT1 |  | JPRT1 DC_MID; JPRT2 saída CPR1 | Extras PCB sem símbolo nem footprint biblioteca; anel D6 furo3.81; retenção/corrente/uso devem ser documentados |
| JPRT2 |  | JPRT1 DC_MID; JPRT2 saída CPR1 | Extras PCB sem símbolo nem footprint biblioteca; anel D6 furo3.81; retenção/corrente/uso devem ser documentados |
| P1 | PRIMARIO A | P1 capacitor primário; P2 DC_MID conforme netlist | Nome M6 incompatível com furo2.2: geometria para fio, não para parafuso M6; corpo genérico interfere CT; F02 |
| P2 | PRIMARIO B | P1 capacitor primário; P2 DC_MID conforme netlist | Nome M6 incompatível com furo2.2: geometria para fio, não para parafuso M6; corpo genérico interfere CT; F02 |
| PS1 | HLK-15M15BL | AC1/2, -Vo3, +Vo4 conferem vista superior Hi-Link p11 | Pitch42.5/7.8/22.6 confere desenho de referência; furo1.1 versus terminal0.8±0.2 e pitch±1 exigem peça real; colisão IEC/fixação F07 |
| Q1 | FGA60N65SMD | FGA60N65SMD G1/C2/E3 confere | Pitch5.45 confere onsemi; furo1.4986 perto do envelope diagonal máx ~1.415 do terminal; dobra/dissipador/furo5.5 no PCB separados e pendentes; corpo fab15.5 não cobre máx16.2 |
| Q2 | FGA60N65SMD | FGA60N65SMD G1/C2/E3 confere | Pitch5.45 confere onsemi; furo1.4986 perto do envelope diagonal máx ~1.415 do terminal; dobra/dissipador/furo5.5 no PCB separados e pendentes; corpo fab15.5 não cobre máx16.2 |
| R1 | 1k 5W | Não polarizado | REPROVADO envelope: corpo declarado 25 mm, furos distam 22.86 mm; silk/fab deslocados 15.24 mm; F02 |
| R2 | 1k | Não polarizado | DIN0207 P7.62 coerente genericamente; conferir potência/tolerância/corpo MPN; R4 amortecimento GDT depende de ensaio |
| R3 | 10k | Não polarizado | DIN0207 P7.62 coerente genericamente; conferir potência/tolerância/corpo MPN; R4 amortecimento GDT depende de ensaio |
| R4 | 3R3 | Não polarizado | DIN0207 P7.62 coerente genericamente; conferir potência/tolerância/corpo MPN; R4 amortecimento GDT depende de ensaio |
| R5 | 100k 0.5W | Não polarizado | Pendente MPN 0.5 W: pitch real 10.16, nome 12.70; fab/silk não recentrados; F02 |
| R6 | 100k 0.5W | Não polarizado | Pendente MPN 0.5 W: pitch real 10.16, nome 12.70; fab/silk não recentrados; F02 |
| SEM_REF_10 |  | NPTH não polarizado | Furo mecânico sem referência/lib; conferir arruela/dissipador/standoff e isolamento |
| SEM_REF_20 |  | NPTH não polarizado | Furo mecânico sem referência/lib; conferir arruela/dissipador/standoff e isolamento |
| SEM_REF_25 |  | NPTH não polarizado | Furo mecânico sem referência/lib; conferir arruela/dissipador/standoff e isolamento |
| SEM_REF_35 |  | NPTH não polarizado | Furo mecânico sem referência/lib; conferir arruela/dissipador/standoff e isolamento |
| SEM_REF_37 |  | NPTH não polarizado | Furo mecânico sem referência/lib; conferir arruela/dissipador/standoff e isolamento |
| T1 | 1:1:1 | Pares1-2/3-4/5-6 conforme netlist; fase não validada | P0584 original renumerado; pads fora de courtyard genérico; bobinagem/fase/isolações/core/volt-segundo desconhecidos |
| T3 | 1:300 | Secundário CT1/2; primário externo sem pad | P12.7 furo1.27; dimensões/core/relação real/fase/burden/isolação desconhecidos; corpo genérico conflita P1/P2 |
| Z1 | 1.5KE510CA | 1.5KE510CA bidirecional; não exigir cátodo elétrico apesar do K desenhado | DNP no esquema mas não no PCB; F08. Pitch real14.732, nome15.24; TVS não substitui clamp gate-emitter |
| Z2 | 1.5KE510CA | 1.5KE510CA bidirecional; não exigir cátodo elétrico apesar do K desenhado | DNP no esquema mas não no PCB; F08. Pitch real14.732, nome15.24; TVS não substitui clamp gate-emitter |

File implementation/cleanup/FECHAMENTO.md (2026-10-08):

# Fechamento da revisão KiCad — 2026-10-08

**Estado: parcial; não fabricar nem energizar.** Branch `fix/cad-review-20261007`, base `7ac4dfd`. O PCB e esquema na raiz são as fontes CAD deste checkpoint. `canonical*`, `circle-test*` e relatórios `drc-1` a `drc-6` são históricos de teste, não fontes de fabricação. Scripts de estágios anteriores não são pipeline idempotente.

## Alterações recuperadas

- Corrigidas as bibliotecas locais para equivalência com footprints embutidos; modelos ausentes de furos/terminais restaurados. As 20 diferenças anteriores eram orientação equivalente de pads circulares/quadrados, sem mudança física de cobre.
- C9/C10 e R2 separados de corpos adjacentes, sem encolher F.Fab/courtyard. Roteamento salvo e zonas preenchidas. Referências e textos de silk reorganizados parcialmente.
- Q1/Q2 no esquema apontam para `Q_TO3P_ImportedPads_ReviewPending`: geometria importada, **não** confirmação de encapsulamento/MPN.
- Prova nativa `native-proof.json`: 48 identidades, pads/nets/furos, vias, contorno e furos de montagem preservados; apenas C9, C10 e R2 mudaram de posição. `structural-proof.txt` atesta conectividade pino-rede sem alteração.

## Verificação na última gravação

KiCad CLI 10.0.6, contêiner `kicad-web:local`, entrada montada read-only, saídas em `implementation/cleanup`. Comandos: `sch erc --format json`, `sch export netlist`, `pcb drc --all-track-errors --schematic-parity --severity-all --refill-zones --format json`.

| Checagem | Resultado |
|---|---:|
| DRC | 84 violações (antes desta limpeza: 363) |
| Courtyards sobrepostos | 22 |
| PTH/NPTH dentro de courtyard vizinho | 16 / 4 |
| Silk overlap / silk sobre máscara-cobre / silk-borda | 22 / 17 / 3 |
| Curtos, clearance de cobre, hole-clearance e conexões pendentes | 0 reportados |
| Paridade | 2 `extra_footprint`: JPRT1/JPRT2 |
| ERC | 2 `power_pin_not_driven` em PS1; sem alteração de topologia |

`net-current.net` difere de `final.net` somente no carimbo `date` do exportador; o diff textual não mostra outras alterações. Relatórios atuais: `erc-current.json`, `drc-current.json`, `net-current.net`. Plots pós-ajuste: `top.png`, `bottom.png`, `assembly.png`, `before-after.png`. A contagem DRC é ocorrência reportada, não índice de segurança. Regras e exclusões não foram relaxadas.

## Retomada e triagem — 2026-10-08

Checkpoint `87aa19d` inspecionado sem editar o PCB ou esquema. O arquivo `drc-current.json` contém 84 violações: 22 courtyards sobrepostos, 16 PTH e 4 NPTH dentro de courtyard vizinho, 22 overlaps de silk, 17 silk sobre abertura de máscara e 3 silk-borda. A paridade registra JPRT1/JPRT2 como footprints extras; não há itens desconectados. Os arquivos de prova nativa e estrutural continuam vinculados aos hashes do checkpoint (ver `native-proof.json`). Esta retomada é uma triagem dos relatórios existentes, **não** uma nova execução de KiCad nem uma nova prova elétrica.

- C5/C8, C6/C13, IC3/C13 e J110/D4 são colisões localizadas, porém envolvem courtyards/corpos e, em dois pares, silk sobre pads. Mover footprints requer avaliação de espaço, trilhas e zonas; apagar somente círculos/segmentos de silk esconderia a posição física.
- P1/P2/T3/CPR1, Q1/Q2/Z1/Z2/T1, PS1/J1/F1/H3 e furos H2/H4 envolvem envelopes ou fixações interdependentes. Não há correção geométrica independente demonstrada que preserve dimensões, placement elétrico e roteamento.
- As 3 ocorrências silk-borda são contornos de PS1/J1; não justificam alterar borda da placa nem apagar contorno sem confirmar encaixe mecânico.

**Resultado desta retomada:** nenhuma alteração CAD verificavelmente segura identificada; contagens e bloqueios do checkpoint permanecem. Antes de uma nova iteração de placement, confirmar componentes e envelopes físicos listados abaixo.

Uma [triagem reproduzível](TRIAGEM.md) agrupa as 84 ocorrências em quatro conjuntos de interferência, gerada por `python implementation/cleanup/triage_drc.py`. O script confere os hashes do PCB/esquema contra `native-proof.json` e exige que os relatórios atuais coincidam com os finais (exceto o horário de exportação). Essa análise não é nova execução de KiCad nem mudança no CAD.

## Bloqueios reais

1. Colisões físicas envolvem P1/P2, CPR1, Q1/Q2, Z1/Z2, T3, PS1/J1 e H2-H4. Mover essas peças agora exigiria rever trilhas e confirmar dimensões/envelope do conjunto. Não se deve apagar courtyards/corpos ou silk de posição para ocultá-las.
2. Confirmar MPN e desenho de C11/C12, R1, Q1/Q2, J1, PS1, D4/F1, T1/T3, terminais e dissipadores, além do envelope da placa/chassis. Footprints `ReviewPending`/`CONFIRMAR` não estão homologados.
3. Especificar rede de entrada, corrente/pulsos, isolamento e PE/terra de proteção, capacidade térmica e mecânica. DRC sem curto não aprova isolamento de rede/HV ou corrente.
4. JPRT1/JPRT2 exigem decisão funcional/documental: footprint só de placa ou componentes esquemáticos. Mantidos para não inventar topologia.
5. PS1: os 2 ERC requerem decisão sobre fonte/pinos; não adicionar `PWR_FLAG` só para zerar avisos.

Próxima etapa após dados de peças/envelope: placement físico, reroteamento completo da área afetada, refill, ERC/DRC/paridade, netlist e inspeção visual finais. Nenhum Gerber de fabricação é aprovado neste estado.

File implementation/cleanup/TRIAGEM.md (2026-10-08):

# Triagem reproduzível do checkpoint KiCad

Gerado de `drc-current.json` e `erc-current.json` por `triage_drc.py`.
Os hashes do PCB e esquema foram comparados a `native-proof.json`.
**Isto não reexecuta KiCad, não valida peças/envelopes e não libera fabricação.**

- DRC: **84** ocorrências; conexões pendentes: **0**.
- Paridade: **2**; ERC: **2**.
- Tipos DRC: `courtyards_overlap` 22, `npth_inside_courtyard` 4, `pth_inside_courtyard` 16, `silk_edge_clearance` 3, `silk_over_copper` 17, `silk_overlap` 22.

## Grupos de interferência

Uma ocorrência pertence a um grupo; grupos ligados por uma mesma referência são unidos.
A contagem inclui silk, furos e courtyard e **não** mede a gravidade elétrica.

| Referências ligadas | Ocorrências | Tipos |
|---|---:|---|
| C13, C6, CPR1, H2, H4, IC3, IC4, JPRT1, P1, P2, Q1, Q2, R1, R4, T1, T3, Z1, Z2 | 59 | courtyards_overlap: 18, npth_inside_courtyard: 2, pth_inside_courtyard: 15, silk_over_copper: 12, silk_overlap: 12 |
| F1, H3, J1, PS1 | 15 | courtyards_overlap: 2, npth_inside_courtyard: 2, pth_inside_courtyard: 1, silk_edge_clearance: 3, silk_over_copper: 3, silk_overlap: 4 |
| D4, J110 | 6 | courtyards_overlap: 1, silk_overlap: 5 |
| C5, C8 | 4 | courtyards_overlap: 1, silk_over_copper: 2, silk_overlap: 1 |

## Paridade e ERC

- Paridade `extra_footprint`: JPRT1.
- Paridade `extra_footprint`: JPRT2.
- ERC `power_pin_not_driven`: Symbol PS1 Pin 1 [AC, Power input, Line].
- ERC `power_pin_not_driven`: Symbol PS1 Pin 2 [AC, Power input, Line].

Pendências de componente, potência, isolamento e envelope físico permanecem em `FECHAMENTO.md`.

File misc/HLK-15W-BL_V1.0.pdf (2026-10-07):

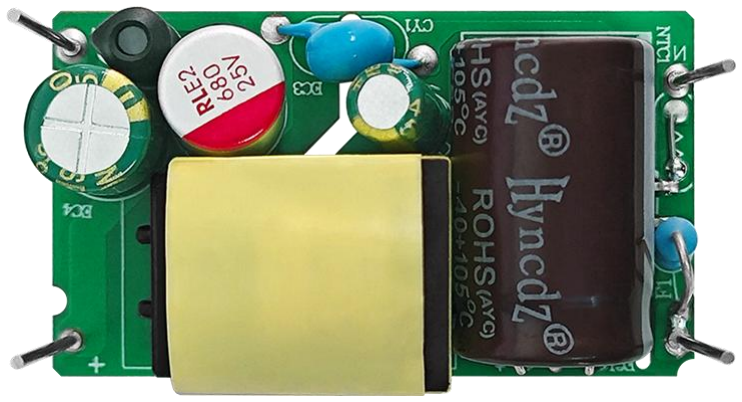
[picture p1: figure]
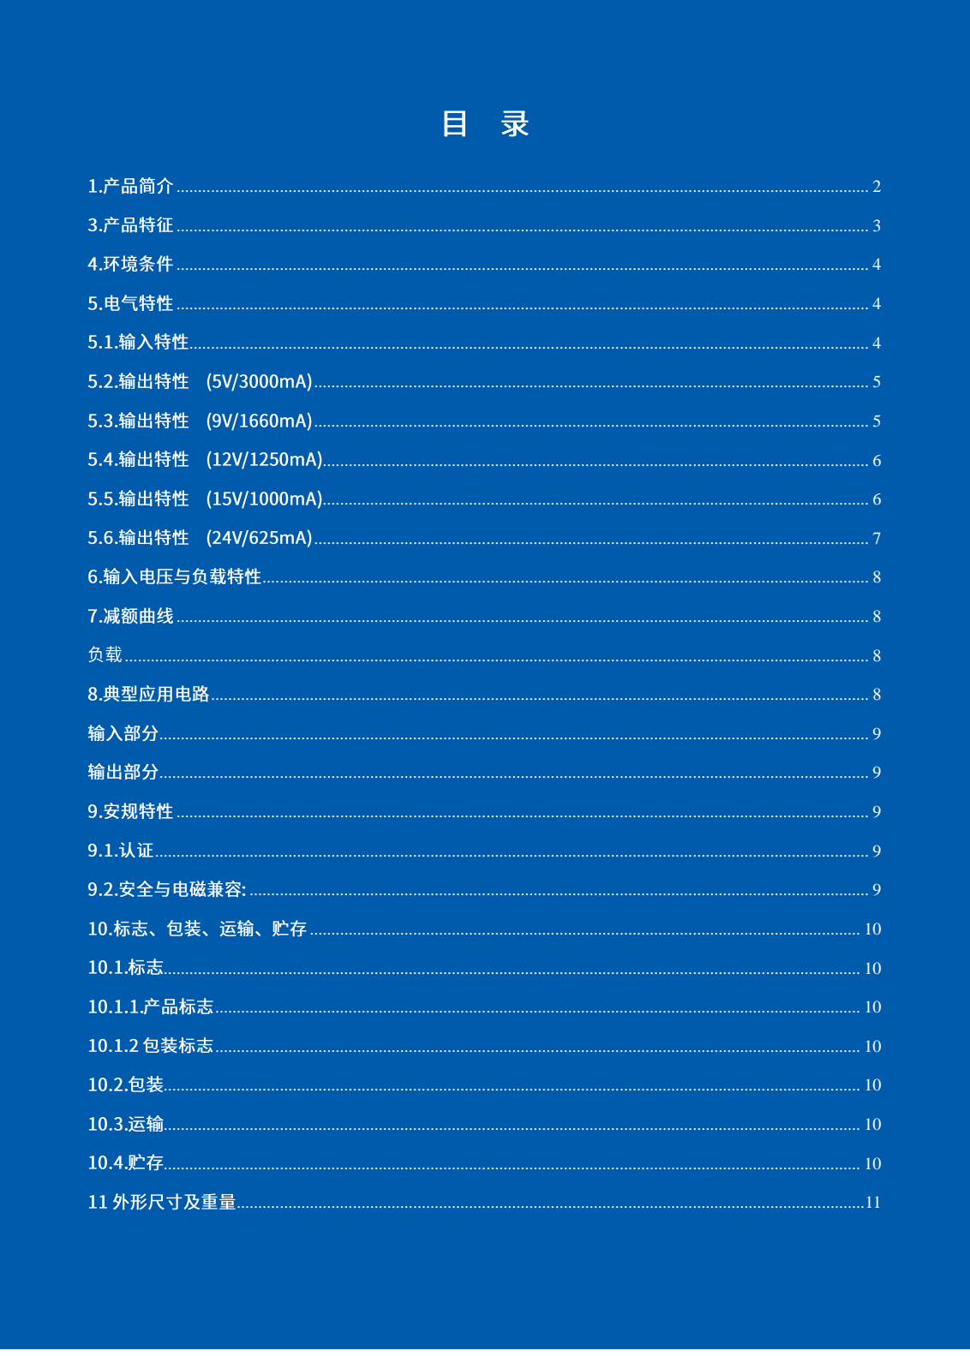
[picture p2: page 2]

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
| 10
| 10
| 10
| 10
| 10
| 10
| 10
| 11

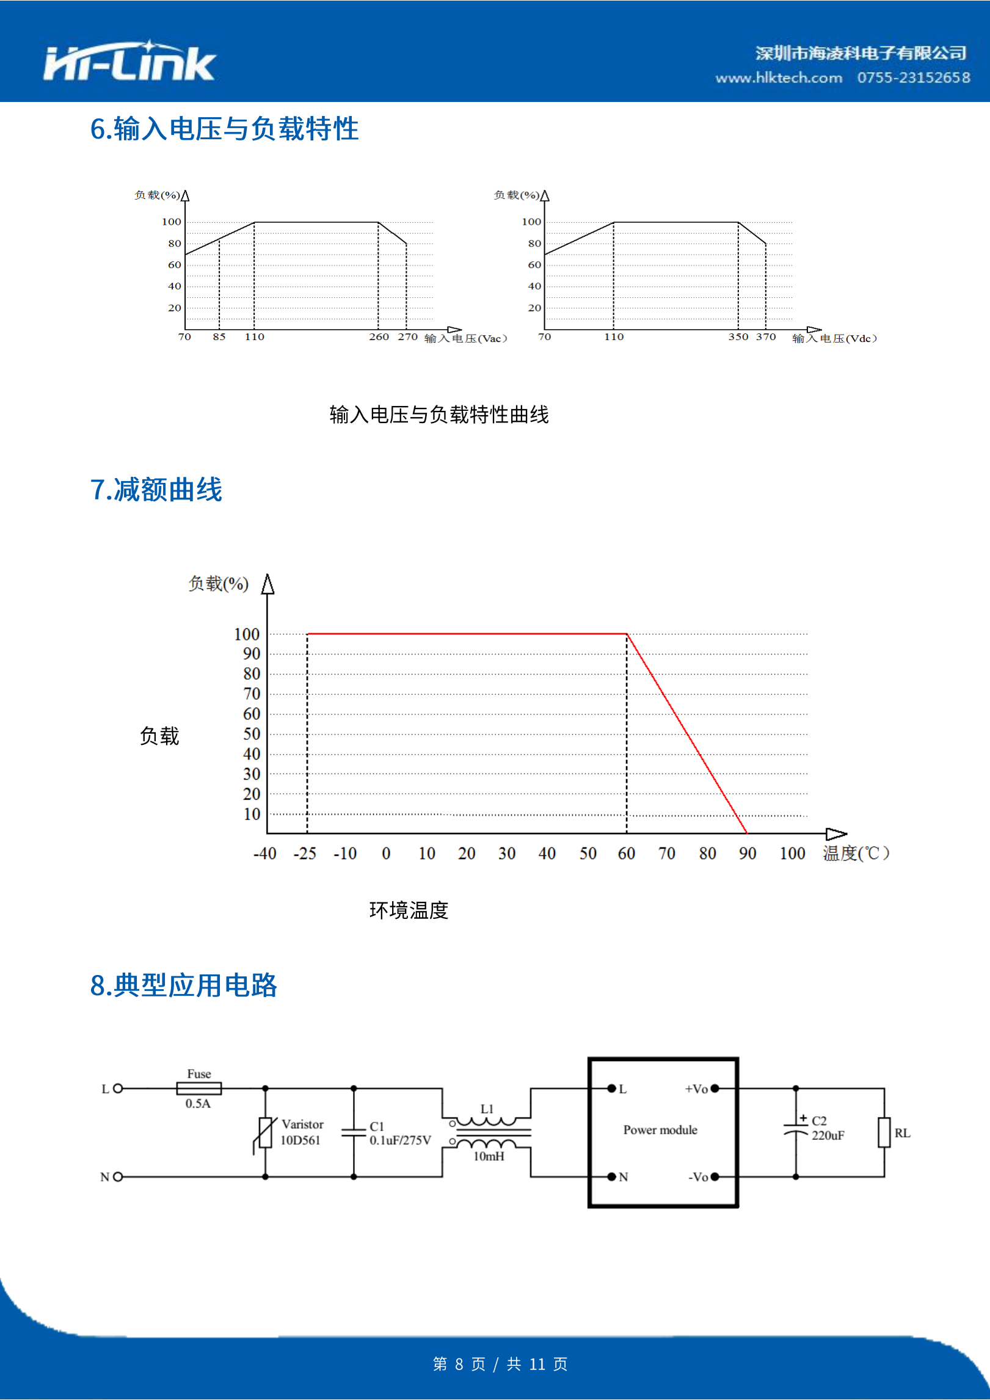
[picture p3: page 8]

●●●

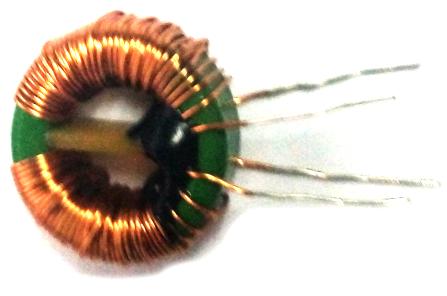
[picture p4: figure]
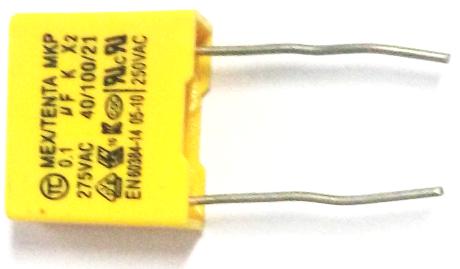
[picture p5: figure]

●●●●●●●

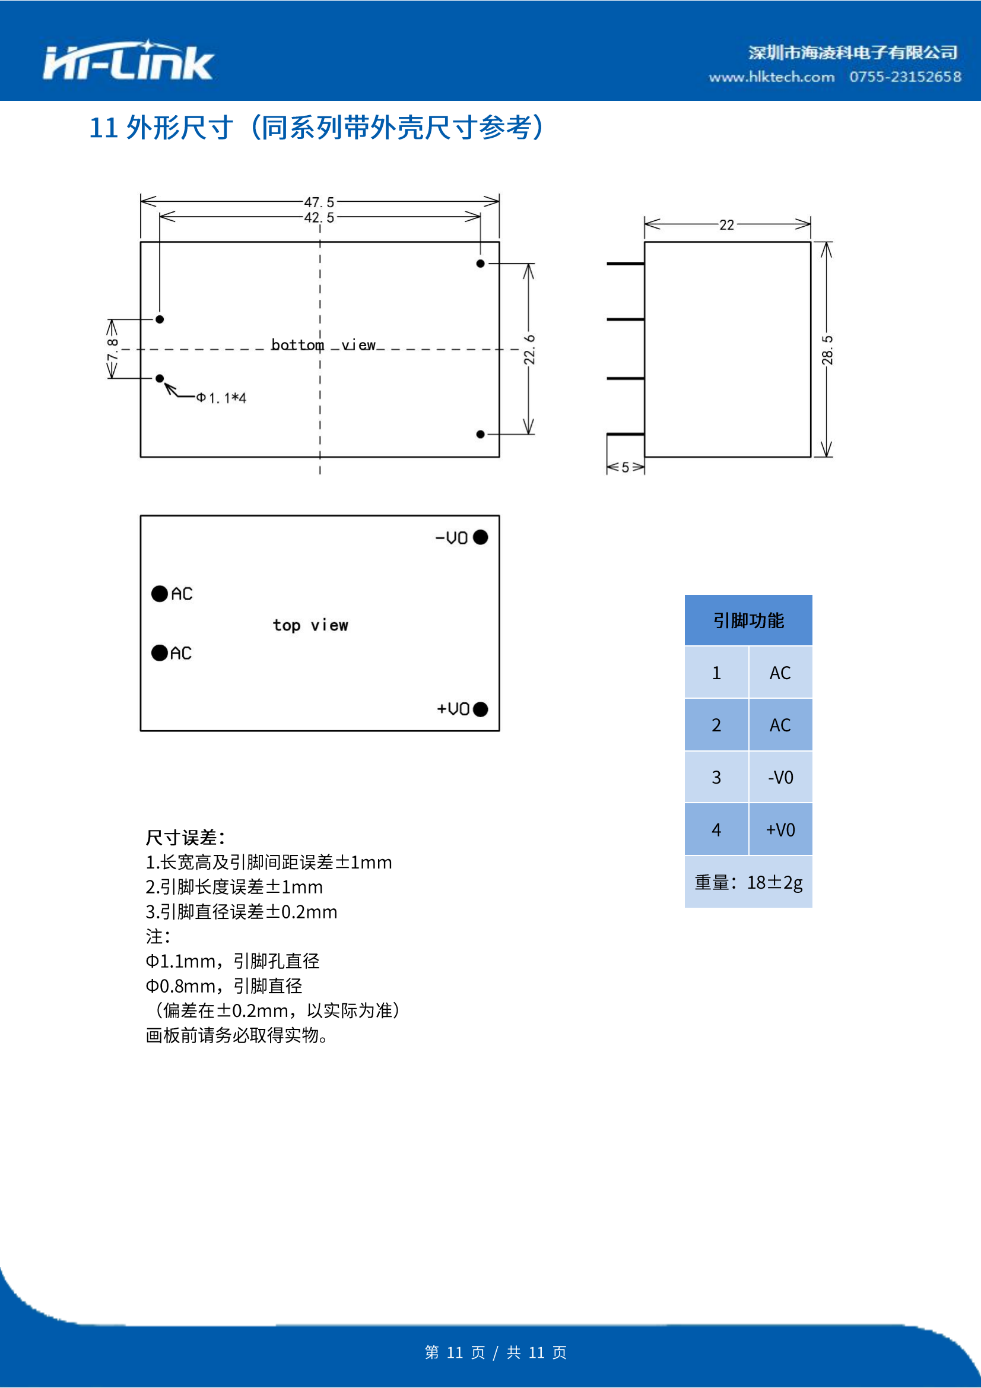
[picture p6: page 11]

bottom view

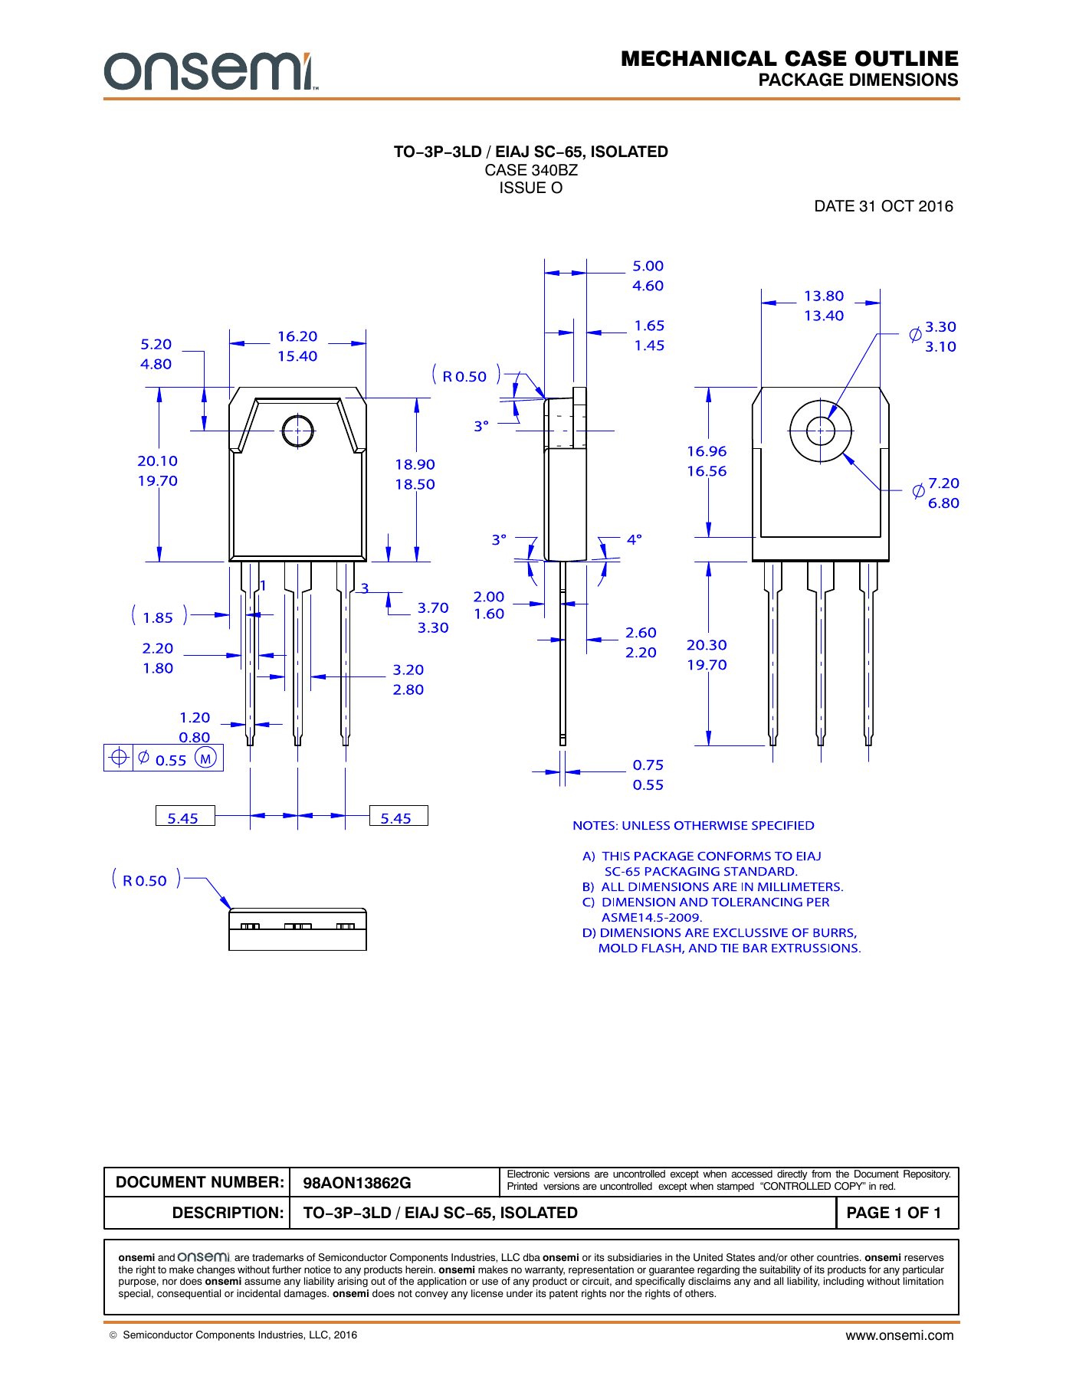
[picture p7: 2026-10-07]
review/evidence/igbt-mechanical.png

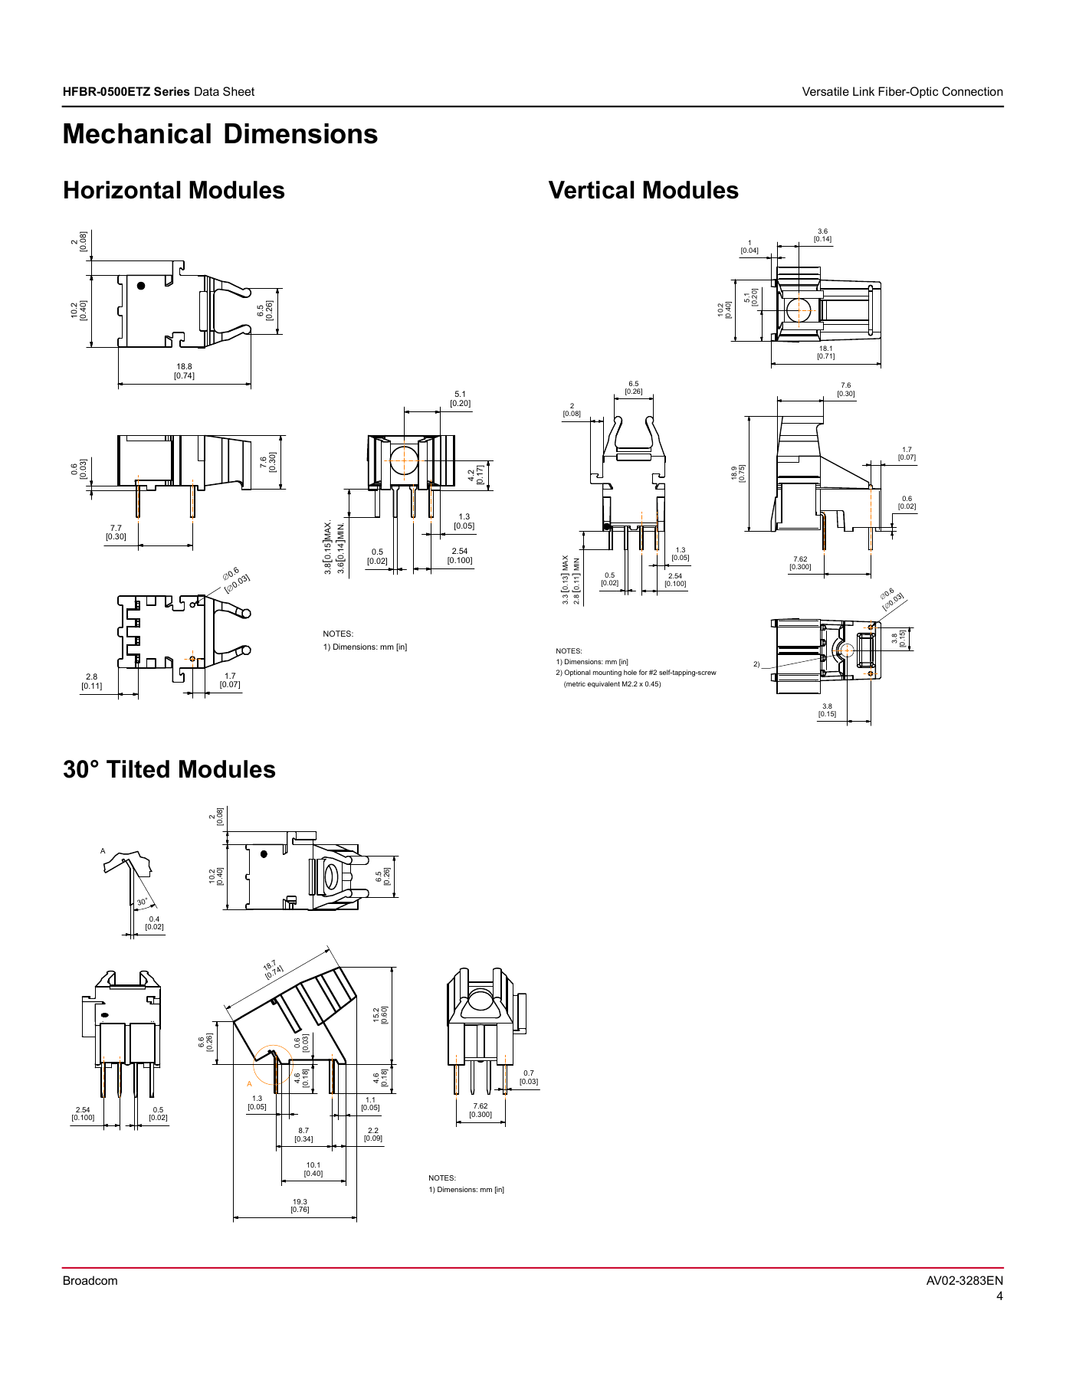
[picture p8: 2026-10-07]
review/evidence/hfbr-mechanical.png

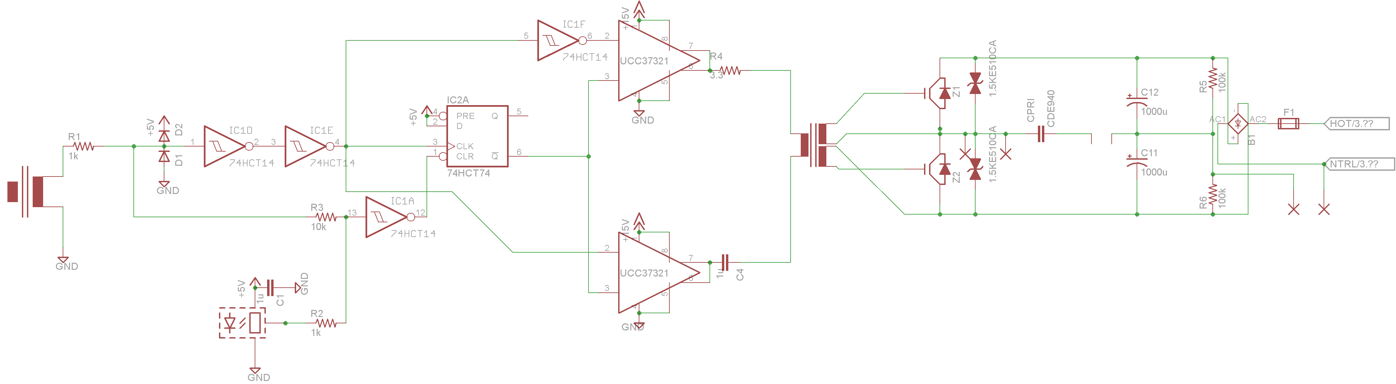
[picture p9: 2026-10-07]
misc/schematic_ref.png

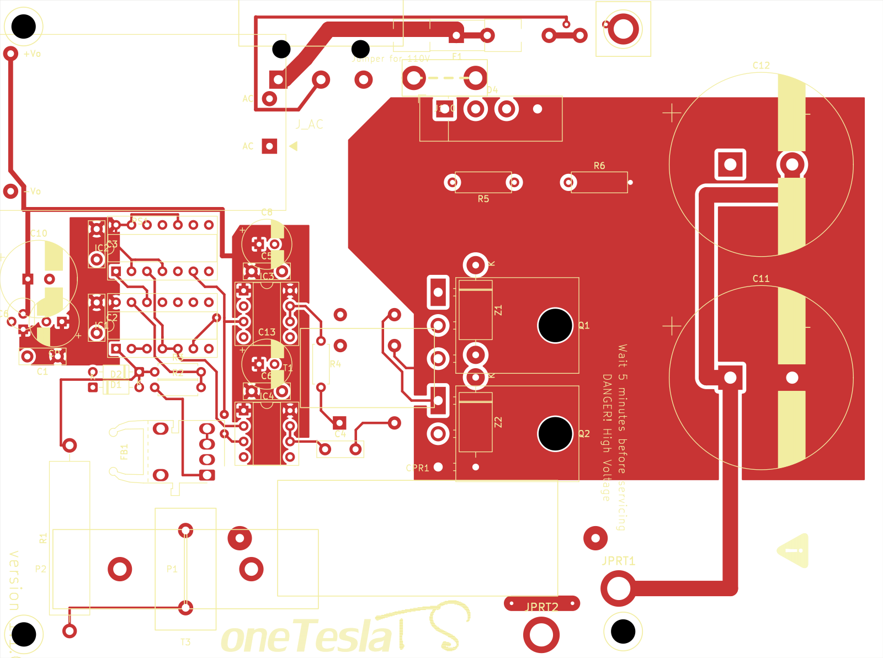
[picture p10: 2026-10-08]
implementation/expansion/top.png

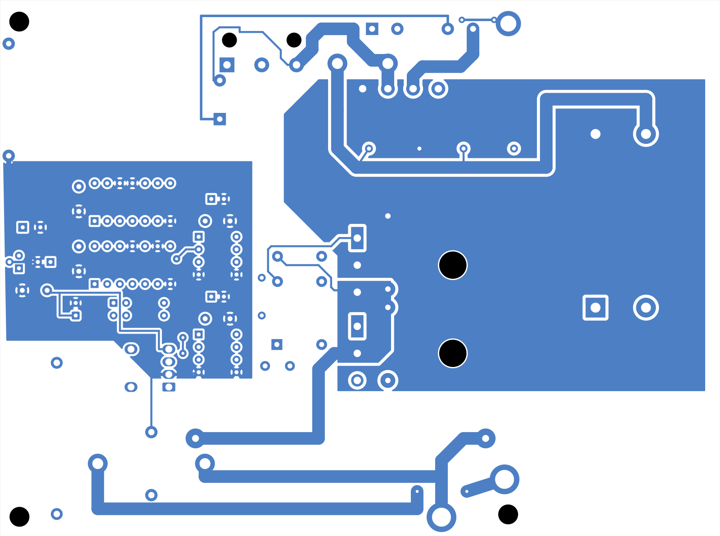
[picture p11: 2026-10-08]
implementation/expansion/bottom.png

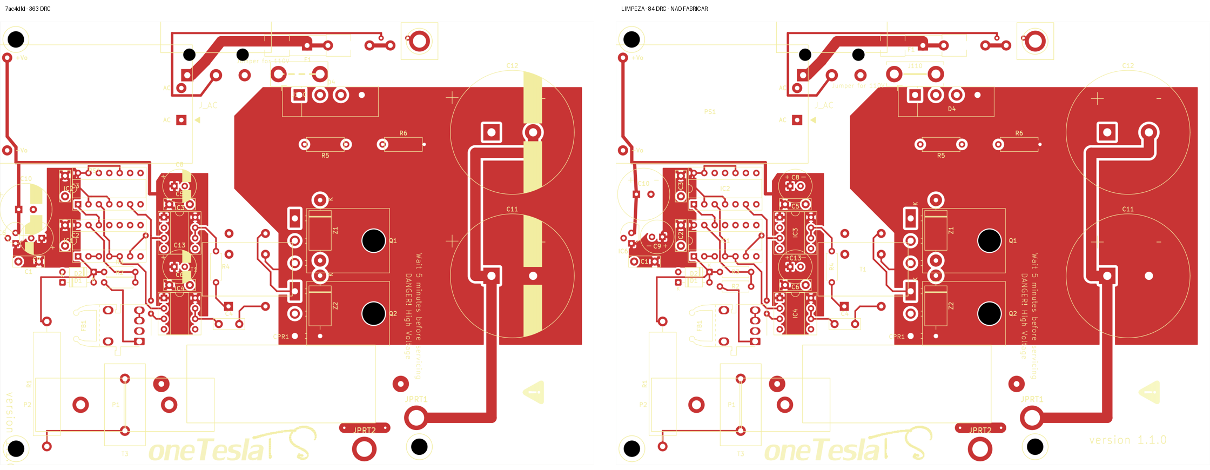
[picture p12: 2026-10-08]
implementation/cleanup/before-after.png

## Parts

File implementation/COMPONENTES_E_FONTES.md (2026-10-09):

# Componentes e fontes para a revisão do layout

Levantamento em 2026-10-08 do esquema `oneTesla.kicad_sch`, das notas em
`review/` e dos arquivos de fabricante. **Um valor no esquema não é um PN de
compra.** Esta tabela distingue peças nomeadas de geometrias ainda genéricas.
Nenhuma peça alternativa foi selecionada para compra ou aprovada para fabricar.

| Referências | Identificação no esquema | Fonte mecânica | Situação do footprint/layout |
|---|---|---|---|
| PS1 | HLK-15M15BL | [Hi-Link, página do produto](https://www.hlktech.net/index.php?cateid=733&id=1408); `misc/HLK-15W-BL_V1.0.pdf` | Modelo identificado; o próprio desenho informa tolerância de ±1 mm no espaçamento dos pinos. Envelope e interferência com IEC/fusível precisam ser revisados, mas não é uma peça sem datasheet. |
| Q1/Q2 | FGA60N65SMD | [onsemi, datasheet e desenho TO-3P](https://www.onsemi.com/download/data-sheet/pdf/fga60n65smd-d.pdf) | PN identificado; passo de 5,45 mm. O corpo máximo de 16,2 mm e a montagem horizontal/dissipador devem ser representados; o footprint atual é importado e está marcado `ReviewPending`. |
| FB1 | HFBR-2521ETZ | [Broadcom, família HFBR-0500ETZ](https://docs.broadcom.com/doc/AV02-3283EN) | PN e pinagem identificados; biblioteca local já revisada, mas isso não resolve as outras colisões do layout. |
| CPR1 | 940C30S68K-F | [Cornell Dubilier, série 940C](https://www.cde.com/resources/catalogs/940C.pdf) | PN identificado: corpo Ø19 × 46 mm, fio Ø1 mm. Passo da dobra dos terminais na PCB não é uma dimensão de fábrica e a montagem junto a P1/P2/T3 precisa ser redesenhada. |
| D4 | KBU6G | [Vishay, KBU6G](https://www.vishay.com/docs/98732/kbu6.pdf) | O esquema nomeia a família/variante, mas o footprint preserva pads da ponte GBU importada. Conferir ordem e espaçamento do fabricante escolhido antes de alterar pads/roteamento. |
| F1 | Fusível 4 A/250 VAC; clipes 5 × 20 mm | [Littelfuse, clipes série 111](https://www.littelfuse.com/assetdocs/littelfuse_fuse_clip_111_datasheet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) | A série 111 é uma opção documentada, não um PN de clipe escolhido. O valor do fusível não define seu suporte, capacidade de interrupção ou envelope de montagem. |
| C11/C12 | 1000 µF, 200 V | [Chemi-Con ESMQ201VSN102MR30S](https://www.chemi-con.co.jp/en/products/detail-condenser.php?part_number=ESMQ201VSN102MR30S), candidato | Sem PN no esquema. O candidato tem corpo Ø30 mm e terminais a 10,00 mm; o footprint atual é 10,16 mm. Não tratá-los como equivalentes sem adaptar o footprint ao PN selecionado. |
| R1 | 1 kΩ, 5 W cerâmico | `misc/oneTeslaTS_Parts.pdf` | Sem PN de fabricante. Corpo de 25 mm e passo de 30,48 mm no CAD são provisórios. |
| J1, P1/P2, T1/T3 | IEC C6, terminais do primário, GDT e CT | `misc/oneTeslaTS_Parts.pdf`; `misc/oneTeslaTS_User_Manual.pdf` | Não há PN mecânico único no esquema/lista. Transformadores podem ser bobinados para o projeto; dimensões, montagem, fase e terminais precisam ser definidos. O nome `Primary_Terminal_M6` não corresponde ao furo de 2,2 mm no CAD. |

## Consequência para a próxima iteração

É possível trabalhar **já** com os desenhos identificados de PS1, Q1/Q2,
FB1 e CPR1 e com envelopes conservadores para propor novo posicionamento.
O levantamento anterior tratou peças identificadas e peças genéricas como
se tivessem a mesma falta de informação; isso foi impreciso. C11/C12, R1,
conector IEC, clipes, transformadores e terminais ainda exigem PN selecionado
ou uma hipótese de montagem explicitamente provisória. Depois de mover
footprints será necessário refazer trilhas e zonas e repetir DRC, paridade,
ERC e inspeção visual no CAD salvo. A placa atual não está liberada.

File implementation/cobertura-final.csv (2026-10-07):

referencia | valor | footprint | estado | limites_originais | pads
Z2 | 1.5KE510CA | oneTesla:D_DO201AD_P14.732_ReviewPending | Corpo/polaridade recentrados; modelo personalizado explícito; MPN/encaixe pendentes | DNP no esquema mas não no PCB; F08. Pitch real14.732, nome15.24; TVS não substitui clamp gate-emitter | [{"numero": "1", "at": ["-7.366", "0", "180"], "drill": ["1.1"], "net": "/SW_NODE"}, {"numero": "2", "at": ["7.366", "0", "180"], "drill": ["1.1"], "net": "/DC_MINUS"}]
P1 | PRIMARIO A | oneTesla:Primary_Terminal_M6_CONFIRMAR | Sem alteração de geometria; pendências da auditoria mantidas | Nome M6 incompatível com furo2.2: geometria para fio, não para parafuso M6; corpo genérico interfere CT; F02 | [{"numero": "1", "at": ["0", "0"], "drill": ["2.2"], "net": "Net-(CPR1-Pad2)"}]
D1 | 1N4148 | oneTesla:D_DO-35_SOD27_P7.62mm_Horizontal | Sem alteração de geometria; pendências da auditoria mantidas | DO35 P7.62 genérico; conferir MPN e faixa de cátodo na montagem | [{"numero": "1", "at": ["0", "0"], "drill": ["0.8"], "net": "Net-(D1-K)"}, {"numero": "2", "at": ["7.62", "0"], "drill": ["0.8"], "net": "GND"}]
C10 | 680u 35V | oneTesla:CP_D12.5_P3.556_ReviewPending | Corpo/polaridade recentrados; modelo personalizado explícito; MPN/encaixe pendentes | Pendente MPN: pitch real 3.556 versus nome 5; corpo/silk deslocados 2.5 mm; F02 | [{"numero": "1", "at": ["-1.778", "0"], "drill": ["0.8128"], "net": "+15V"}, {"numero": "2", "at": ["1.778", "0"], "drill": ["0.8128"], "net": "GND"}]
C12 | 1000u 200V | oneTesla:CP_D30_P10.16_ReviewPending | Corpo/polaridade recentrados; modelo personalizado explícito; MPN/encaixe pendentes | REPROVADO envelope D30: centros distam 26.035 mm, sobreposição 3.965 mm; F03. Pitch 10.16, MPN desconhecido | [{"numero": "1", "at": ["-5.08", "0"], "drill": ["2"], "net": "/DC_PLUS"}, {"numero": "2", "at": ["5.08", "0"], "drill": ["2"], "net": "/DC_MID"}]
R2 | 1k | oneTesla:R_Axial_DIN0207_L6.3mm_D2.5mm_P7.62mm_Horizontal | Sem alteração de geometria; pendências da auditoria mantidas | DIN0207 P7.62 coerente genericamente; conferir potência/tolerância/corpo MPN; R4 amortecimento GDT depende de ensaio | [{"numero": "1", "at": ["0", "0"], "drill": ["0.8"], "net": "/OPTICAL_OUT"}, {"numero": "2", "at": ["7.62", "0"], "drill": ["0.8"], "net": "Net-(IC1-Pad13)"}]
C6 | 1u | oneTesla:C_Disc_D7.5mm_W2.5mm_P5.00mm | Sem alteração de geometria; pendências da auditoria mantidas | Disco P5, furos/pads inventariados; dielétrico/tensão/ESL/MPN desconhecidos; C4 deve suportar corrente do GDT | [{"numero": "1", "at": ["0", "0"], "drill": ["1"], "net": "+15V"}, {"numero": "2", "at": ["5", "0"], "drill": ["1"], "net": "GND"}]
C9 | 100u 10V | oneTesla:CP_D8_P2.54_ReviewPending | Corpo/polaridade recentrados; modelo personalizado explícito; MPN/encaixe pendentes | Pendente MPN: pitch real 2.54 versus nome 3.50; F02. C9 em +5 V; C8/C13 em +15 V | [{"numero": "1", "at": ["-1.27", "0"], "drill": ["0.8128"], "net": "+5V"}, {"numero": "2", "at": ["1.27", "0"], "drill": ["0.8128"], "net": "GND"}]
J110 | Jumper 110V | oneTesla:J110_WireLink_P10.16mm | Sem alteração de geometria; pendências da auditoria mantidas | P10.16 furo2.2; jumper deve ter corrente/isolação especificados e intertravamento/rotulagem; nunca selecionar fechado em220 | [{"numero": "1", "at": ["-5.08", "0"], "drill": ["2.2"], "net": "/AC_N"}, {"numero": "2", "at": ["5.08", "0"], "drill": ["2.2"], "net": "/DC_MID"}]
SEM_REF_10 |  | oneTesla:MountingHole_D4.0 | Sem alteração de geometria; pendências da auditoria mantidas | Furo mecânico: posição preservada; conjunto pendente | [{"numero": "", "at": ["0", "0"], "drill": ["4"], "net": ""}]
R3 | 10k | oneTesla:R_Axial_DIN0207_L6.3mm_D2.5mm_P7.62mm_Horizontal | Sem alteração de geometria; pendências da auditoria mantidas | DIN0207 P7.62 coerente genericamente; conferir potência/tolerância/corpo MPN; R4 amortecimento GDT depende de ensaio | [{"numero": "1", "at": ["0", "0"], "drill": ["0.8"], "net": "Net-(D1-K)"}, {"numero": "2", "at": ["7.62", "0"], "drill": ["0.8"], "net": "Net-(IC1-Pad13)"}]
R5 | 100k 0.5W | oneTesla:R_L9_P10.16_ReviewPending | Corpo/polaridade recentrados; modelo personalizado explícito; MPN/encaixe pendentes | Pendente MPN 0.5 W: pitch real 10.16, nome 12.70; fab/silk não recentrados; F02 | [{"numero": "1", "at": ["-5.08", "0"], "drill": ["0.8128"], "net": "/DC_PLUS"}, {"numero": "2", "at": ["5.08", "0"], "drill": ["0.8128"], "net": "/DC_MID"}]
JPRT1 |  | oneTesla:Ring_D6_D3.81 | Sem alteração de geometria; pendências da auditoria mantidas | Extras PCB sem símbolo nem footprint biblioteca; anel D6 furo3.81; retenção/corrente/uso devem ser documentados | [{"numero": "1", "at": ["0", "0"], "drill": ["3.81"], "net": "/DC_MID"}]
IC3 | UCC37321P | oneTesla:DIP-8_W7.62mm_Socket_LongPads | Sem alteração de geometria; pendências da auditoria mantidas | PDIP8 P2.54 W7.62 coerente; soquete exato pendente; TI recomenda desacoplamento em ambos pares VDD/GND, não comprovado nesta geometria | [{"numero": "1", "at": ["0", "0"], "drill": ["0.8128"], "net": "+15V"}, {"numero": "2", "at": ["0", "2.54"], "drill": ["0.8128"], "net": "Net-(IC3-IN)"}, {"numero": "3", "at": ["0", "5.08"], "drill": ["0.8128"], "net": "/DRIVE_ENABLE"}, {"numero": "4", "at": ["0", "7.62"], "drill": ["0.8128"], "net": "GND"}, {"numero": "5", "at": ["7.62", "7.62"], "drill": ["0.8128"], "net": "GND"}, {"numero": "6", "at": ["7.62", "5.08"], "drill": ["0.8128"], "net": "Net-(IC3-OUT-Pad6)"}, {"numero": "7", "at": ["7.62", "2.54"], "drill": ["0.8128"], "net": "Net-(IC3-OUT-Pad6)"}, {"numero": "8", "at": ["7.62", "0"], "drill": ["0.8128"], "net": "+15V"}]
C8 | 100u 25V | oneTesla:CP_D8_P2.54_ReviewPending | Corpo/polaridade recentrados; modelo personalizado explícito; MPN/encaixe pendentes | Pendente MPN: pitch real 2.54 versus nome 3.50; F02. C9 em +5 V; C8/C13 em +15 V | [{"numero": "1", "at": ["-1.27", "0"], "drill": ["0.8128"], "net": "+15V"}, {"numero": "2", "at": ["1.27", "0"], "drill": ["0.8128"], "net": "GND"}]
C4 | 1u | oneTesla:C_Disc_D7.5mm_W2.5mm_P5.00mm | Sem alteração de geometria; pendências da auditoria mantidas | Disco P5, furos/pads inventariados; dielétrico/tensão/ESL/MPN desconhecidos; C4 deve suportar corrente do GDT | [{"numero": "1", "at": ["0", "0"], "drill": ["1"], "net": "Net-(C4-Pad1)"}, {"numero": "2", "at": ["5", "0"], "drill": ["1"], "net": "Net-(T1-AB)"}]
D4 | KBU6G | oneTesla:Diode_Bridge_Vishay_KBU | Sem alteração de geometria; pendências da auditoria mantidas | KBU6G fabricante indefinido; pads seguem GBU4S original P5.08, não confirma KBU escolhido; desenho Vishay não recuperado; F02 | [{"numero": "1", "at": ["0", "0"], "drill": ["1.4986"], "net": "/DC_PLUS"}, {"numero": "2", "at": ["10.16", "0"], "drill": ["1.4986"], "net": "/AC_L_FUSED"}, {"numero": "3", "at": ["5.08", "0"], "drill": ["1.4986"], "net": "/AC_N"}, {"numero": "4", "at": ["15.24", "0"], "drill": ["1.4986"], "net": "/DC_MINUS"}]
JPRT2 |  | oneTesla:Ring_D6_D3.81 | Sem alteração de geometria; pendências da auditoria mantidas | Extras PCB sem símbolo nem footprint biblioteca; anel D6 furo3.81; retenção/corrente/uso devem ser documentados | [{"numero": "1", "at": ["0", "0"], "drill": ["3.81"], "net": "Net-(CPR1-Pad2)"}]
C1 | 1u | oneTesla:C_Disc_D7.5mm_W2.5mm_P5.00mm | Sem alteração de geometria; pendências da auditoria mantidas | Disco P5, furos/pads inventariados; dielétrico/tensão/ESL/MPN desconhecidos; C4 deve suportar corrente do GDT | [{"numero": "1", "at": ["0", "0"], "drill": ["1"], "net": "+5V"}, {"numero": "2", "at": ["5", "0"], "drill": ["1"], "net": "GND"}]
SEM_REF_20 |  | oneTesla:MountingHole_D5.5 | Sem alteração de geometria; pendências da auditoria mantidas | Furo mecânico: posição preservada; conjunto pendente | [{"numero": "", "at": ["0", "0"], "drill": ["5.5"], "net": ""}]
IC6 | 78L05 | oneTesla:TO-92_Inline | Sem alteração de geometria; pendências da auditoria mantidas | REVISAR: footprint chamado Inline tem pads triangulares; fabricante/sufixo 78L05 e conformação das pernas obrigatórios | [{"numero": "1", "at": ["-1.27", "0"], "drill": ["0.8128"], "net": "+5V"}, {"numero": "2", "at": ["0", "-1.905"], "drill": ["0.8128"], "net": "GND"}, {"numero": "3", "at": ["1.27", "0"], "drill": ["0.8128"], "net": "+15V"}]
PS1 | HLK-15M15BL | oneTesla:HLK-15M15BL | Roteamento AC local corrigido; largura preservada; isolamento/encaixe NÃO aprovados | Pitch42.5/7.8/22.6 confere desenho de referência; furo1.1 versus terminal0.8±0.2 e pitch±1 exigem peça real; colisão IEC/fixação F07 | [{"numero": "1", "at": ["0", "0"], "drill": ["1.1"], "net": "/AC_L_FUSED"}, {"numero": "2", "at": ["0", "7.8"], "drill": ["1.1"], "net": "/AC_N"}, {"numero": "3", "at": ["42.5", "-7.4"], "drill": ["1.1"], "net": "GND"}, {"numero": "4", "at": ["42.5", "15.2"], "drill": ["1.1"], "net": "+15V"}]
Q1 | FGA60N65SMD | oneTesla:TO-3P-3_Horizontal_TabDown | Sem alteração de geometria; pendências da auditoria mantidas | Pitch5.45 confere onsemi; furo1.4986 perto do envelope diagonal máx ~1.415 do terminal; dobra/dissipador/furo5.5 no PCB separados e pendentes; corpo fab15.5 não cobre máx16.2 | [{"numero": "1", "at": ["0", "0"], "drill": ["1.4986"], "net": "/GATE_H"}, {"numero": "2", "at": ["5.45", "0"], "drill": ["1.4986"], "net": "/DC_PLUS"}, {"numero": "3", "at": ["10.9", "0"], "drill": ["1.4986"], "net": "/SW_NODE"}]
CPR1 | 68n 3kV | oneTesla:CDE_940C30S68K_F_CONFIRMAR | Sem alteração de geometria; pendências da auditoria mantidas | CDE 940C30S68K-F: corpo 46x19 e fio 1 mm conferem catálogo; P58.42 é dobra escolhida, não pitch de fábrica; furo1.4; ensaio RMS/dVdt obrigatório | [{"numero": "1", "at": ["-29.21", "0"], "drill": ["1.4"], "net": "/SW_NODE"}, {"numero": "2", "at": ["29.21", "0"], "drill": ["1.4"], "net": "Net-(CPR1-Pad2)"}]
SEM_REF_25 |  | oneTesla:MountingHole_D4.0 | Sem alteração de geometria; pendências da auditoria mantidas | Furo mecânico: posição preservada; conjunto pendente | [{"numero": "", "at": ["0", "0"], "drill": ["4"], "net": ""}]
T3 | 1:300 | oneTesla:CT_1_300_P12.70mm_CONFIRMAR | Sem alteração de geometria; pendências da auditoria mantidas | P12.7 furo1.27; dimensões/core/relação real/fase/burden/isolação desconhecidos; corpo genérico conflita P1/P2 | [{"numero": "1", "at": ["0", "-6.35"], "drill": ["1.27"], "net": "Net-(T3-S1)"}, {"numero": "2", "at": ["0", "6.35"], "drill": ["1.27"], "net": "GND"}]
C3 | 1u | oneTesla:C_Disc_D7.5mm_W2.5mm_P5.00mm | Sem alteração de geometria; pendências da auditoria mantidas | Disco P5, furos/pads inventariados; dielétrico/tensão/ESL/MPN desconhecidos; C4 deve suportar corrente do GDT | [{"numero": "1", "at": ["0", "0"], "drill": ["1"], "net": "+5V"}, {"numero": "2", "at": ["5", "0"], "drill": ["1"], "net": "GND"}]
T1 | 1:1:1 | oneTesla:GDT_6Pin_CONFIRMAR | Sem alteração de geometria; pendências da auditoria mantidas | P0584 original renumerado; pads fora de courtyard genérico; bobinagem/fase/isolações/core/volt-segundo desconhecidos | [{"numero": "1", "at": ["-9.017", "-4.572"], "drill": ["1.016"], "net": "Net-(T1-AA)"}, {"numero": "2", "at": ["-9.017", "4.445"], "drill": ["1.016"], "net": "Net-(T1-AB)"}, {"numero": "3", "at": ["3.683", "-4.445"], "drill": ["1.016"], "net": "/GATE_H"}, {"numero": "4", "at": ["8.763", "-4.445"], "drill": ["1.016"], "net": "/SW_NODE"}, {"numero": "5", "at": ["8.763", "4.445"], "drill": ["1.016"], "net": "/GATE_L"}, {"numero": "6", "at": ["3.683", "4.445"], "drill": ["1.016"], "net": "/DC_MINUS"}]
P2 | PRIMARIO B | oneTesla:Primary_Terminal_M6_CONFIRMAR | Sem alteração de geometria; pendências da auditoria mantidas | Nome M6 incompatível com furo2.2: geometria para fio, não para parafuso M6; corpo genérico interfere CT; F02 | [{"numero": "1", "at": ["0", "0"], "drill": ["2.2"], "net": "/DC_MID"}]
R4 | 3R3 | oneTesla:R_Axial_DIN0207_L6.3mm_D2.5mm_P7.62mm_Horizontal | Sem alteração de geometria; pendências da auditoria mantidas | DIN0207 P7.62 coerente genericamente; conferir potência/tolerância/corpo MPN; R4 amortecimento GDT depende de ensaio | [{"numero": "1", "at": ["0", "0"], "drill": ["0.8"], "net": "Net-(IC3-OUT-Pad6)"}, {"numero": "2", "at": ["7.62", "0"], "drill": ["0.8"], "net": "Net-(T1-AA)"}]
F1 | 4A/250VAC | oneTesla:Fuseholder_Clip-5x20mm_Littelfuse_111_Inline_P20.00x5.00mm_D1.05mm_Horizontal | Sem alteração de geometria; pendências da auditoria mantidas | Pads ±5.08/±10.16, furos1.1938; fab herdado deslocado; clipe Littelfuse exato não comprovado; tipo/I²t/capacidade interrupção pendentes | [{"numero": "1", "at": ["5.08", "0"], "drill": ["1.1938"], "net": "/AC_L"}, {"numero": "1", "at": ["10.16", "0"], "drill": ["1.1938"], "net": "/AC_L"}, {"numero": "2", "at": ["-10.16", "0"], "drill": ["1.1938"], "net": "/AC_L_FUSED"}, {"numero": "2", "at": ["-5.08", "0"], "drill": ["1.1938"], "net": "/AC_L_FUSED"}]
IC2 | 74HCT74 | oneTesla:DIP-14_W7.62mm_Socket_LongPads | Sem alteração de geometria; pendências da auditoria mantidas | DIP14 P2.54 W7.62; furo0.8128 pad1.6; MPN/sufixo e soquete exatos desconhecidos; LongPads no nome não corresponde ao pad real | [{"numero": "1", "at": ["0", "0"], "drill": ["0.8128"], "net": "Net-(IC2A-~{R})"}, {"numero": "2", "at": ["0", "2.54"], "drill": ["0.8128"], "net": "+5V"}, {"numero": "3", "at": ["0", "5.08"], "drill": ["0.8128"], "net": "Net-(IC2A-C)"}, {"numero": "4", "at": ["0", "7.62"], "drill": ["0.8128"], "net": "+5V"}, {"numero": "5", "at": ["0", "10.16"], "drill": ["0.8128"], "net": "unconnected-(IC2A-Q-Pad5)"}, {"numero": "6", "at": ["0", "12.7"], "drill": ["0.8128"], "net": "/DRIVE_ENABLE"}, {"numero": "7", "at": ["0", "15.24"], "drill": ["0.8128"], "net": "GND"}, {"numero": "8", "at": ["7.62", "15.24"], "drill": ["0.8128"], "net": "unconnected-(IC2B-~{Q}-Pad8)"}, {"numero": "9", "at": ["7.62", "12.7"], "drill": ["0.8128"], "net": "unconnected-(IC2B-Q-Pad9)"}, {"numero": "10", "at": ["7.62", "10.16"], "drill": ["0.8128"], "net": "+5V"}, {"numero": "11", "at": ["7.62", "7.62"], "drill": ["0.8128"], "net": "GND"}, {"numero": "12", "at": ["7.62", "5.08"], "drill": ["0.8128"], "net": "GND"}, {"numero": "13", "at": ["7.62", "2.54"], "drill": ["0.8128"], "net": "+5V"}, {"numero": "14", "at": ["7.62", "0"], "drill": ["0.8128"], "net": "+5V"}]
FB1 | HFBR-2521ETZ | oneTesla:HFBR-2521ETZ | Broadcom pitch2.54, retencoes5/8 NC; reposicionado/reroteado; cabo/enclosure pendente | REPROVADO HFBR-2521ETZ: pitch 1.905 versus 2.54 mm datasheet; ordem espacial 3-1-2-4 adaptada de IFD95; F01 | [{"numero": "1", "at": ["0", "0", "90"], "drill": ["1.4"], "net": "/OPTICAL_OUT"}, {"numero": "2", "at": ["2.54", "0", "90"], "drill": ["1.4"], "net": "GND"}, {"numero": "3", "at": ["5.08", "0", "90"], "drill": ["1.4"], "net": "+5V"}, {"numero": "4", "at": ["7.62", "0", "90"], "drill": ["1.4"], "net": "+5V"}, {"numero": "5", "at": ["7.62", "-7.62", "90"], "drill": ["1.4"], "net": "unconnected-(FB1-NC-Pad5)"}, {"numero": "8", "at": ["0", "-7.62", "90"], "drill": ["1.4"], "net": "unconnected-(FB1-NC-Pad8)"}]
R6 | 100k 0.5W | oneTesla:R_L9_P10.16_ReviewPending | Corpo/polaridade recentrados; modelo personalizado explícito; MPN/encaixe pendentes | Pendente MPN 0.5 W: pitch real 10.16, nome 12.70; fab/silk não recentrados; F02 | [{"numero": "1", "at": ["-5.08", "0"], "drill": ["0.8128"], "net": "/DC_MID"}, {"numero": "2", "at": ["5.08", "0"], "drill": ["0.8128"], "net": "/DC_MINUS"}]
SEM_REF_35 |  | oneTesla:MountingHole_D5.5 | Sem alteração de geometria; pendências da auditoria mantidas | Furo mecânico: posição preservada; conjunto pendente | [{"numero": "", "at": ["0", "0"], "drill": ["5.5"], "net": ""}]
D2 | 1N4148 | oneTesla:D_DO-35_SOD27_P7.62mm_Horizontal | Sem alteração de geometria; pendências da auditoria mantidas | DO35 P7.62 genérico; conferir MPN e faixa de cátodo na montagem | [{"numero": "1", "at": ["0", "0"], "drill": ["0.8"], "net": "+5V"}, {"numero": "2", "at": ["7.62", "0"], "drill": ["0.8"], "net": "Net-(D1-K)"}]
SEM_REF_37 |  | oneTesla:MountingHole_D4.0 | Sem alteração de geometria; pendências da auditoria mantidas | Furo mecânico: posição preservada; conjunto pendente | [{"numero": "", "at": ["0", "0"], "drill": ["4"], "net": ""}]
J2 | PE/CHASSIS | oneTesla:Chassis_PE_M3 | Sem alteração de geometria; pendências da auditoria mantidas | Furo3.2 M3 pad5.1; cobre só0.2059 da borda; resistência/torque/arruela/bonding não definidos; F05 | [{"numero": "1", "at": ["0", "0"], "drill": ["3.2"], "net": "/PE"}]
C2 | 1u | oneTesla:C_Disc_D7.5mm_W2.5mm_P5.00mm | Sem alteração de geometria; pendências da auditoria mantidas | Disco P5, furos/pads inventariados; dielétrico/tensão/ESL/MPN desconhecidos; C4 deve suportar corrente do GDT | [{"numero": "1", "at": ["0", "0"], "drill": ["1"], "net": "+5V"}, {"numero": "2", "at": ["5", "0"], "drill": ["1"], "net": "GND"}]
C5 | 1u | oneTesla:C_Disc_D7.5mm_W2.5mm_P5.00mm | Sem alteração de geometria; pendências da auditoria mantidas | Disco P5, furos/pads inventariados; dielétrico/tensão/ESL/MPN desconhecidos; C4 deve suportar corrente do GDT | [{"numero": "1", "at": ["0", "0"], "drill": ["1"], "net": "+15V"}, {"numero": "2", "at": ["5", "0"], "drill": ["1"], "net": "GND"}]
C13 | 100u 25V | oneTesla:CP_D8_P2.54_ReviewPending | Corpo/polaridade recentrados; modelo personalizado explícito; MPN/encaixe pendentes | Pendente MPN: pitch real 2.54 versus nome 3.50; F02. C9 em +5 V; C8/C13 em +15 V | [{"numero": "1", "at": ["-1.27", "0"], "drill": ["0.8128"], "net": "+15V"}, {"numero": "2", "at": ["1.27", "0"], "drill": ["0.8128"], "net": "GND"}]
IC4 | UCC37321P | oneTesla:DIP-8_W7.62mm_Socket_LongPads | Sem alteração de geometria; pendências da auditoria mantidas | PDIP8 P2.54 W7.62 coerente; soquete exato pendente; TI recomenda desacoplamento em ambos pares VDD/GND, não comprovado nesta geometria | [{"numero": "1", "at": ["0", "0"], "drill": ["0.8128"], "net": "+15V"}, {"numero": "2", "at": ["0", "2.54"], "drill": ["0.8128"], "net": "Net-(IC2A-C)"}, {"numero": "3", "at": ["0", "5.08"], "drill": ["0.8128"], "net": "/DRIVE_ENABLE"}, {"numero": "4", "at": ["0", "7.62"], "drill": ["0.8128"], "net": "GND"}, {"numero": "5", "at": ["7.62", "7.62"], "drill": ["0.8128"], "net": "GND"}, {"numero": "6", "at": ["7.62", "5.08"], "drill": ["0.8128"], "net": "Net-(C4-Pad1)"}, {"numero": "7", "at": ["7.62", "2.54"], "drill": ["0.8128"], "net": "Net-(C4-Pad1)"}, {"numero": "8", "at": ["7.62", "0"], "drill": ["0.8128"], "net": "+15V"}]
IC1 | 74HCT14 | oneTesla:DIP-14_W7.62mm_Socket_LongPads | Sem alteração de geometria; pendências da auditoria mantidas | DIP14 P2.54 W7.62; furo0.8128 pad1.6; MPN/sufixo e soquete exatos desconhecidos; LongPads no nome não corresponde ao pad real | [{"numero": "1", "at": ["0", "0"], "drill": ["0.8128"], "net": "Net-(D1-K)"}, {"numero": "2", "at": ["0", "2.54"], "drill": ["0.8128"], "net": "Net-(IC1-Pad2)"}, {"numero": "3", "at": ["0", "5.08"], "drill": ["0.8128"], "net": "Net-(IC1-Pad2)"}, {"numero": "4", "at": ["0", "7.62"], "drill": ["0.8128"], "net": "Net-(IC2A-C)"}, {"numero": "5", "at": ["0", "10.16"], "drill": ["0.8128"], "net": "Net-(IC2A-C)"}, {"numero": "6", "at": ["0", "12.7"], "drill": ["0.8128"], "net": "Net-(IC3-IN)"}, {"numero": "7", "at": ["0", "15.24"], "drill": ["0.8128"], "net": "GND"}, {"numero": "8", "at": ["7.62", "15.24"], "drill": ["0.8128"], "net": "unconnected-(IC1-Pad8)"}, {"numero": "9", "at": ["7.62", "12.7"], "drill": ["0.8128"], "net": "GND"}, {"numero": "10", "at": ["7.62", "10.16"], "drill": ["0.8128"], "net": "unconnected-(IC1-Pad10)"}, {"numero": "11", "at": ["7.62", "7.62"], "drill": ["0.8128"], "net": "GND"}, {"numero": "12", "at": ["7.62", "5.08"], "drill": ["0.8128"], "net": "Net-(IC2A-~{R})"}, {"numero": "13", "at": ["7.62", "2.54"], "drill": ["0.8128"], "net": "Net-(IC1-Pad13)"}, {"numero": "14", "at": ["7.62", "0"], "drill": ["0.8128"], "net": "+5V"}]
J1 | IEC C6 | oneTesla:IEC_C6_CONFIRMAR | Roteamento AC local corrigido; largura preservada; isolamento/encaixe NÃO aprovados | IEC C6 sem MPN; trilha de rede invade furo mecânico F04; colisão PS1/F1 | [{"numero": "", "at": ["-6.5", "9.5"], "drill": ["3"], "net": ""}, {"numero": "", "at": ["6.5", "9.5"], "drill": ["3"], "net": ""}, {"numero": "1", "at": ["-7", "14.5"], "drill": ["1.5"], "net": "/AC_L"}, {"numero": "2", "at": ["7", "14.5"], "drill": ["1.5"], "net": "/AC_N"}, {"numero": "3", "at": ["0", "14.5"], "drill": ["1.5"], "net": "/PE"}]
R1 | 1k 5W | oneTesla:R_L25_P22.86_INCOMPATIBLE | Corpo/polaridade recentrados; modelo personalizado explícito; MPN/encaixe pendentes | REPROVADO envelope: corpo declarado 25 mm, furos distam 22.86 mm; silk/fab deslocados 15.24 mm; F02 | [{"numero": "1", "at": ["-11.43", "0", "180"], "drill": ["1.3"], "net": "Net-(T3-S1)"}, {"numero": "2", "at": ["11.43", "0", "180"], "drill": ["1.3"], "net": "Net-(D1-K)"}]
Q2 | FGA60N65SMD | oneTesla:TO-3P-3_Horizontal_TabDown | Sem alteração de geometria; pendências da auditoria mantidas | Pitch5.45 confere onsemi; furo1.4986 perto do envelope diagonal máx ~1.415 do terminal; dobra/dissipador/furo5.5 no PCB separados e pendentes; corpo fab15.5 não cobre máx16.2 | [{"numero": "1", "at": ["0", "0"], "drill": ["1.4986"], "net": "/GATE_L"}, {"numero": "2", "at": ["5.45", "0"], "drill": ["1.4986"], "net": "/SW_NODE"}, {"numero": "3", "at": ["10.9", "0"], "drill": ["1.4986"], "net": "/DC_MINUS"}]
Z1 | 1.5KE510CA | oneTesla:D_DO201AD_P14.732_ReviewPending | Corpo/polaridade recentrados; modelo personalizado explícito; MPN/encaixe pendentes | DNP no esquema mas não no PCB; F08. Pitch real14.732, nome15.24; TVS não substitui clamp gate-emitter | [{"numero": "1", "at": ["-7.366", "0", "180"], "drill": ["1.1"], "net": "/DC_PLUS"}, {"numero": "2", "at": ["7.366", "0", "180"], "drill": ["1.1"], "net": "/SW_NODE"}]
C11 | 1000u 200V | oneTesla:CP_D30_P10.16_ReviewPending | Corpo/polaridade recentrados; modelo personalizado explícito; MPN/encaixe pendentes | REPROVADO envelope D30: centros distam 26.035 mm, sobreposição 3.965 mm; F03. Pitch 10.16, MPN desconhecido | [{"numero": "1", "at": ["-5.08", "0"], "drill": ["2"], "net": "/DC_MID"}, {"numero": "2", "at": ["5.08", "0"], "drill": ["2"], "net": "/DC_MINUS"}]

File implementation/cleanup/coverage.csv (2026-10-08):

reference | uuid | value | footprint | placement | pads | body_and_courtyard
Z2 | 043be2ab-2909-4184-858f-b2e62dd66361 | 1.5KE510CA | oneTesla:D_DO201AD_P14.732_ReviewPending | ["78.105", "67.31", "-90"] | [{"number": "1", "at": ["-7.366", "0", "270"], "drill": ["1.1"], "net": "/SW_NODE"}, {"number": "2", "at": ["7.366", "0", "270"], "drill": ["1.1"], "net": "/DC_MINUS"}] | unchanged; manufacturer fit NOT newly verified
P1 | 088ec556-0787-483d-9168-49628798b9c6 | PRIMARIO A | oneTesla:Primary_Terminal_M6_CONFIRMAR | ["41.275", "91.44", "90"] | [{"number": "1", "at": ["0", "0", "90"], "drill": ["2.2"], "net": "Net-(CPR1-Pad2)"}] | unchanged; manufacturer fit NOT newly verified
D1 | 0bd4e4d6-8bbf-4891-80de-701fc24f664c | 1N4148 | oneTesla:D_DO-35_SOD27_P7.62mm_Horizontal | ["22.86", "59.055", "180"] | [{"number": "1", "at": ["0", "0", "180"], "drill": ["0.8"], "net": "Net-(D1-K)"}, {"number": "2", "at": ["7.62", "0", "180"], "drill": ["0.8"], "net": "GND"}] | unchanged; manufacturer fit NOT newly verified
C10 | 13caed20-fea9-4faf-98c2-d408a82b30fe | 680u 35V | oneTesla:CP_D12.5_P3.556_ReviewPending | ["6.8", "40.1"] | [{"number": "1", "at": ["-1.778", "0"], "drill": ["0.8128"], "net": "+15V"}, {"number": "2", "at": ["1.778", "0"], "drill": ["0.8128"], "net": "GND"}] | unchanged; manufacturer fit NOT newly verified
C12 | 14dab930-675f-4d79-9d3d-0748ea40fa16 | 1000u 200V | oneTesla:CP_D30_P10.16_ReviewPending | ["125", "25"] | [{"number": "1", "at": ["-5.08", "0"], "drill": ["2"], "net": "/DC_PLUS"}, {"number": "2", "at": ["5.08", "0"], "drill": ["2"], "net": "/DC_MID"}] | unchanged; manufacturer fit NOT newly verified
R2 | 1b505ac7-39c6-421c-bfd3-d8c0c9e3d88e | 1k | oneTesla:R_Axial_DIN0207_L6.3mm_D2.5mm_P7.62mm_Horizontal | ["25.4", "62.595"] | [{"number": "1", "at": ["0", "0"], "drill": ["0.8"], "net": "/OPTICAL_OUT"}, {"number": "2", "at": ["7.62", "0"], "drill": ["0.8"], "net": "Net-(IC1-Pad13)"}] | unchanged; manufacturer fit NOT newly verified
C6 | 2624217d-13ca-4389-a30e-a437cd1843dc | 1u | oneTesla:C_Disc_D7.5mm_W2.5mm_P5.00mm | ["41.315", "62.23"] | [{"number": "1", "at": ["0", "0"], "drill": ["1"], "net": "+15V"}, {"number": "2", "at": ["5", "0"], "drill": ["1"], "net": "GND"}] | unchanged; manufacturer fit NOT newly verified
C9 | 320f6185-a204-433f-a4a6-9793676a6dde | 100u 10V | oneTesla:CP_D8_P2.54_ReviewPending | ["10.1", "50.5", "180"] | [{"number": "1", "at": ["-1.27", "0", "180"], "drill": ["0.8128"], "net": "+5V"}, {"number": "2", "at": ["1.27", "0", "180"], "drill": ["0.8128"], "net": "GND"}] | unchanged; manufacturer fit NOT newly verified
J110 | 391c27e2-a5cc-4206-b90d-2c4995710cdf | Jumper 110V | oneTesla:J110_WireLink_P10.16mm | ["73.025", "10.795", "180"] | [{"number": "1", "at": ["-5.08", "0", "180"], "drill": ["2.2"], "net": "/AC_N"}, {"number": "2", "at": ["5.08", "0", "180"], "drill": ["2.2"], "net": "/DC_MID"}] | unchanged; manufacturer fit NOT newly verified
H1 | 3abb677c-3c48-4fdf-8784-ae5b95230035 |  | oneTesla:MountingHole_D4.0 | ["3.9243", "102.1588"] | [{"number": "", "at": ["0", "0"], "drill": ["4"], "net": ""}] | unchanged; manufacturer fit NOT newly verified
R3 | 480876c6-2bff-47b9-8d1c-2b394c4e711f | 10k | oneTesla:R_Axial_DIN0207_L6.3mm_D2.5mm_P7.62mm_Horizontal | ["25.4", "59.055"] | [{"number": "1", "at": ["0", "0"], "drill": ["0.8"], "net": "Net-(D1-K)"}, {"number": "2", "at": ["7.62", "0"], "drill": ["0.8"], "net": "Net-(IC1-Pad13)"}] | unchanged; manufacturer fit NOT newly verified
R5 | 4dae5a0c-c8f0-4e2d-8b13-793852bedb3b | 100k 0.5W | oneTesla:R_L9_P10.16_ReviewPending | ["79.375", "27.94", "180"] | [{"number": "1", "at": ["-5.08", "0", "180"], "drill": ["0.8128"], "net": "/DC_PLUS"}, {"number": "2", "at": ["5.08", "0", "180"], "drill": ["0.8128"], "net": "/DC_MID"}] | unchanged; manufacturer fit NOT newly verified
JPRT1 | 4fafd1a0-5b66-474b-b284-286cf4f79105 |  | oneTesla:Ring_D6_D3.81 | ["101.6", "94.615"] | [{"number": "1", "at": ["0", "0"], "drill": ["3.81"], "net": "/DC_MID"}] | unchanged; manufacturer fit NOT newly verified
IC3 | 50b3e22e-5f3f-40e0-918c-eafb32bf85fa | UCC37321P | oneTesla:DIP-8_W7.62mm_Socket_LongPads | ["40.005", "45.72"] | [{"number": "1", "at": ["0", "0"], "drill": ["0.8128"], "net": "+15V"}, {"number": "2", "at": ["0", "2.54"], "drill": ["0.8128"], "net": "Net-(IC3-IN)"}, {"number": "3", "at": ["0", "5.08"], "drill": ["0.8128"], "net": "/DRIVE_ENABLE"}, {"number": "4", "at": ["0", "7.62"], "drill": ["0.8128"], "net": "GND"}, {"number": "5", "at": ["7.62", "7.62"], "drill": ["0.8128"], "net": "GND"}, {"number": "6", "at": ["7.62", "5.08"], "drill": ["0.8128"], "net": "Net-(IC3-OUT-Pad6)"}, {"number": "7", "at": ["7.62", "2.54"], "drill": ["0.8128"], "net": "Net-(IC3-OUT-Pad6)"}, {"number": "8", "at": ["7.62", "0"], "drill": ["0.8128"], "net": "+15V"}] | unchanged; manufacturer fit NOT newly verified
C8 | 5d8b6c4d-ef0a-4df6-ad72-8b44f069fe83 | 100u 25V | oneTesla:CP_D8_P2.54_ReviewPending | ["43.815", "38.1"] | [{"number": "1", "at": ["-1.27", "0"], "drill": ["0.8128"], "net": "+15V"}, {"number": "2", "at": ["1.27", "0"], "drill": ["0.8128"], "net": "GND"}] | unchanged; manufacturer fit NOT newly verified
C4 | 5e505915-79b6-4a08-a21b-4211996d32e8 | 1u | oneTesla:C_Disc_D7.5mm_W2.5mm_P5.00mm | ["53.38", "71.755"] | [{"number": "1", "at": ["0", "0"], "drill": ["1"], "net": "Net-(C4-Pad1)"}, {"number": "2", "at": ["5", "0"], "drill": ["1"], "net": "Net-(T1-AB)"}] | unchanged; manufacturer fit NOT newly verified
D4 | 6432ffb1-1e02-4073-98f0-793960e7a768 | KBU6G | oneTesla:Diode_Bridge_Vishay_KBU | ["73.025", "15.875"] | [{"number": "1", "at": ["0", "0"], "drill": ["1.4986"], "net": "/DC_PLUS"}, {"number": "2", "at": ["10.16", "0"], "drill": ["1.4986"], "net": "/AC_L_FUSED"}, {"number": "3", "at": ["5.08", "0"], "drill": ["1.4986"], "net": "/AC_N"}, {"number": "4", "at": ["15.24", "0"], "drill": ["1.4986"], "net": "/DC_MINUS"}] | unchanged; manufacturer fit NOT newly verified
JPRT2 | 6892e981-bd57-4f2f-9ff6-2c0d3f36bb41 |  | oneTesla:Ring_D6_D3.81 | ["88.9", "102.235"] | [{"number": "1", "at": ["0", "0"], "drill": ["3.81"], "net": "Net-(CPR1-Pad2)"}] | unchanged; manufacturer fit NOT newly verified
C1 | 6967a1b9-0d17-42e9-83f4-c29881745bf5 | 1u | oneTesla:C_Disc_D7.5mm_W2.5mm_P5.00mm | ["9.485", "56.515", "180"] | [{"number": "1", "at": ["0", "0", "180"], "drill": ["1"], "net": "+5V"}, {"number": "2", "at": ["5", "0", "180"], "drill": ["1"], "net": "GND"}] | unchanged; manufacturer fit NOT newly verified
H2 | 6acfa2f4-c1d8-4113-9692-d498ca6c752b |  | oneTesla:MountingHole_D5.5 | ["91.186", "69.215"] | [{"number": "", "at": ["0", "0"], "drill": ["5.5"], "net": ""}] | unchanged; manufacturer fit NOT newly verified
IC6 | 6b102e01-8bfa-49ff-a947-391a974b2601 | 78L05 | oneTesla:TO-92_Inline | ["3.81", "50.8", "90"] | [{"number": "1", "at": ["-1.27", "0", "90"], "drill": ["0.8128"], "net": "+5V"}, {"number": "2", "at": ["0", "-1.905", "90"], "drill": ["0.8128"], "net": "GND"}, {"number": "3", "at": ["1.27", "0", "90"], "drill": ["0.8128"], "net": "+15V"}] | unchanged; manufacturer fit NOT newly verified
PS1 | 70cde1ed-72eb-4f96-a84d-a008b95741df | HLK-15M15BL | oneTesla:HLK-15M15BL | ["44.25", "22", "180"] | [{"number": "1", "at": ["0", "0", "180"], "drill": ["1.1"], "net": "/AC_L_FUSED"}, {"number": "2", "at": ["0", "7.8", "180"], "drill": ["1.1"], "net": "/AC_N"}, {"number": "3", "at": ["42.5", "-7.4", "180"], "drill": ["1.1"], "net": "GND"}, {"number": "4", "at": ["42.5", "15.2", "180"], "drill": ["1.1"], "net": "+15V"}] | unchanged; manufacturer fit NOT newly verified
Q1 | 732d8c26-f467-439a-8fa4-e4be84794145 | FGA60N65SMD | oneTesla:Q_TO3P_ImportedPads_ReviewPending | ["71.9455", "45.985", "-90"] | [{"number": "1", "at": ["0", "0"], "drill": ["1.4986"], "net": "/GATE_H"}, {"number": "2", "at": ["5.45", "0"], "drill": ["1.4986"], "net": "/DC_PLUS"}, {"number": "3", "at": ["10.9", "0"], "drill": ["1.4986"], "net": "/SW_NODE"}] | unchanged; manufacturer fit NOT newly verified
CPR1 | 74d67175-ebb6-4a21-bfc7-1e11c2960983 | 68n 3kV | oneTesla:CDE_940C30S68K_F_CONFIRMAR | ["68.58", "86.36"] | [{"number": "1", "at": ["-29.21", "0"], "drill": ["1.4"], "net": "/SW_NODE"}, {"number": "2", "at": ["29.21", "0"], "drill": ["1.4"], "net": "Net-(CPR1-Pad2)"}] | unchanged; manufacturer fit NOT newly verified
H3 | 77ec0857-d169-4408-a4bf-4dac85be4d5d |  | oneTesla:MountingHole_D4.0 | ["3.8735", "2.3495"] | [{"number": "", "at": ["0", "0"], "drill": ["4"], "net": ""}] | unchanged; manufacturer fit NOT newly verified
T3 | 7881a436-aec0-4c8a-ba7e-8c210efbcf84 | 1:300 | oneTesla:CT_1_300_P12.70mm_CONFIRMAR | ["30.48", "91.44", "180"] | [{"number": "1", "at": ["0", "-6.35", "180"], "drill": ["1.27"], "net": "Net-(T3-S1)"}, {"number": "2", "at": ["0", "6.35", "180"], "drill": ["1.27"], "net": "GND"}] | unchanged; manufacturer fit NOT newly verified
C3 | 7c69af3d-e32c-456b-9d59-fed3aa6c0f0a | 1u | oneTesla:C_Disc_D7.5mm_W2.5mm_P5.00mm | ["15.875", "35.6", "-90"] | [{"number": "1", "at": ["0", "0", "270"], "drill": ["1"], "net": "+5V"}, {"number": "2", "at": ["5", "0", "270"], "drill": ["1"], "net": "GND"}] | unchanged; manufacturer fit NOT newly verified
T1 | 81406b84-f587-4328-8377-b597fae42b21 | 1:1:1 | oneTesla:GDT_6Pin_CONFIRMAR | ["60.325", "58.42", "90"] | [{"number": "1", "at": ["-9.017", "-4.572", "90"], "drill": ["1.016"], "net": "Net-(T1-AA)"}, {"number": "2", "at": ["-9.017", "4.445", "90"], "drill": ["1.016"], "net": "Net-(T1-AB)"}, {"number": "3", "at": ["3.683", "-4.445", "90"], "drill": ["1.016"], "net": "/GATE_H"}, {"number": "4", "at": ["8.763", "-4.445", "90"], "drill": ["1.016"], "net": "/SW_NODE"}, {"number": "5", "at": ["8.763", "4.445", "90"], "drill": ["1.016"], "net": "/GATE_L"}, {"number": "6", "at": ["3.683", "4.445", "90"], "drill": ["1.016"], "net": "/DC_MINUS"}] | unchanged; manufacturer fit NOT newly verified
P2 | 87a76f20-6542-4130-90df-4685584d6a87 | PRIMARIO B | oneTesla:Primary_Terminal_M6_CONFIRMAR | ["19.685", "91.44", "90"] | [{"number": "1", "at": ["0", "0", "90"], "drill": ["2.2"], "net": "/DC_MID"}] | unchanged; manufacturer fit NOT newly verified
R4 | 8a4b53cb-a92a-4e07-a9cd-5611e8dba268 | 3R3 | oneTesla:R_Axial_DIN0207_L6.3mm_D2.5mm_P7.62mm_Horizontal | ["52.705", "53.975", "-90"] | [{"number": "1", "at": ["0", "0", "270"], "drill": ["0.8"], "net": "Net-(IC3-OUT-Pad6)"}, {"number": "2", "at": ["7.62", "0", "270"], "drill": ["0.8"], "net": "Net-(T1-AA)"}] | unchanged; manufacturer fit NOT newly verified
F1 | 8e5309a4-330d-4eca-841c-ff8e10370ccf | 4A/250VAC | oneTesla:Fuseholder_Clip-5x20mm_Littelfuse_111_Inline_P20.00x5.00mm_D1.05mm_Horizontal | ["85.09", "3.81", "180"] | [{"number": "1", "at": ["5.08", "0", "180"], "drill": ["1.1938"], "net": "/AC_L"}, {"number": "1", "at": ["10.16", "0", "180"], "drill": ["1.1938"], "net": "/AC_L"}, {"number": "2", "at": ["-10.16", "0", "180"], "drill": ["1.1938"], "net": "/AC_L_FUSED"}, {"number": "2", "at": ["-5.08", "0", "180"], "drill": ["1.1938"], "net": "/AC_L_FUSED"}] | unchanged; manufacturer fit NOT newly verified
IC2 | 96997fad-88d1-4fb7-8665-81168995b67e | 74HCT74 | oneTesla:DIP-14_W7.62mm_Socket_LongPads | ["19.05", "42.545", "90"] | [{"number": "1", "at": ["0", "0", "90"], "drill": ["0.8128"], "net": "Net-(IC2A-~{R})"}, {"number": "2", "at": ["0", "2.54", "90"], "drill": ["0.8128"], "net": "+5V"}, {"number": "3", "at": ["0", "5.08", "90"], "drill": ["0.8128"], "net": "Net-(IC2A-C)"}, {"number": "4", "at": ["0", "7.62", "90"], "drill": ["0.8128"], "net": "+5V"}, {"number": "5", "at": ["0", "10.16", "90"], "drill": ["0.8128"], "net": "unconnected-(IC2A-Q-Pad5)"}, {"number": "6", "at": ["0", "12.7", "90"], "drill": ["0.8128"], "net": "/DRIVE_ENABLE"}, {"number": "7", "at": ["0", "15.24", "90"], "drill": ["0.8128"], "net": "GND"}, {"number": "8", "at": ["7.62", "15.24", "90"], "drill": ["0.8128"], "net": "unconnected-(IC2B-~{Q}-Pad8)"}, {"number": "9", "at": ["7.62", "12.7", "90"], "drill": ["0.8128"], "net": "unconnected-(IC2B-Q-Pad9)"}, {"number": "10", "at": ["7.62", "10.16", "90"], "drill": ["0.8128"], "net": "+5V"}, {"number": "11", "at": ["7.62", "7.62", "90"], "drill": ["0.8128"], "net": "GND"}, {"number": "12", "at": ["7.62", "5.08", "90"], "drill": ["0.8128"], "net": "GND"}, {"number": "13", "at": ["7.62", "2.54", "90"], "drill": ["0.8128"], "net": "+5V"}, {"number": "14", "at": ["7.62", "0", "90"], "drill": ["0.8128"], "net": "+5V"}] | unchanged; manufacturer fit NOT newly verified
FB1 | 9fa9a1ba-4537-43b2-9f87-389912ae0666 | HFBR-2521ETZ | oneTesla:HFBR-2521ETZ | ["34", "76", "90"] | [{"number": "1", "at": ["0", "0", "90"], "drill": ["1.4"], "net": "/OPTICAL_OUT"}, {"number": "2", "at": ["2.54", "0", "90"], "drill": ["1.4"], "net": "GND"}, {"number": "3", "at": ["5.08", "0", "90"], "drill": ["1.4"], "net": "+5V"}, {"number": "4", "at": ["7.62", "0", "90"], "drill": ["1.4"], "net": "+5V"}, {"number": "5", "at": ["7.62", "-7.62", "90"], "drill": ["1.4"], "net": "unconnected-(FB1-NC-Pad5)"}, {"number": "8", "at": ["0", "-7.62", "90"], "drill": ["1.4"], "net": "unconnected-(FB1-NC-Pad8)"}] | unchanged; manufacturer fit NOT newly verified
R6 | a8ca0788-aecd-47da-82e9-4bfc70362a18 | 100k 0.5W | oneTesla:R_L9_P10.16_ReviewPending | ["98.425", "27.94"] | [{"number": "1", "at": ["-5.08", "0"], "drill": ["0.8128"], "net": "/DC_MID"}, {"number": "2", "at": ["5.08", "0"], "drill": ["0.8128"], "net": "/DC_MINUS"}] | unchanged; manufacturer fit NOT newly verified
H4 | b168aced-a020-41f0-9ecd-e2bf74278246 |  | oneTesla:MountingHole_D5.5 | ["91.186", "51.435"] | [{"number": "", "at": ["0", "0"], "drill": ["5.5"], "net": ""}] | unchanged; manufacturer fit NOT newly verified
D2 | cc163ef4-b31c-4e0a-a526-6b594020e5ba | 1N4148 | oneTesla:D_DO-35_SOD27_P7.62mm_Horizontal | ["15.24", "61.595"] | [{"number": "1", "at": ["0", "0"], "drill": ["0.8"], "net": "+5V"}, {"number": "2", "at": ["7.62", "0"], "drill": ["0.8"], "net": "Net-(D1-K)"}] | unchanged; manufacturer fit NOT newly verified
H5 | d3b76e2a-64a4-465d-8b9e-638fd56f7995 |  | oneTesla:MountingHole_D4.0 | ["102.3239", "101.6762"] | [{"number": "", "at": ["0", "0"], "drill": ["4"], "net": ""}] | unchanged; manufacturer fit NOT newly verified
J2 | dbc3914a-4fb0-40c3-a253-822e51f3b78e | PE/CHASSIS | oneTesla:Chassis_PE_M3 | ["102.362", "2.7559"] | [{"number": "1", "at": ["0", "0"], "drill": ["3.2"], "net": "/PE"}] | unchanged; manufacturer fit NOT newly verified
C2 | de58467c-30af-45e4-a3db-055c2b68fd87 | 1u | oneTesla:C_Disc_D7.5mm_W2.5mm_P5.00mm | ["15.875", "47.665", "-90"] | [{"number": "1", "at": ["0", "0", "270"], "drill": ["1"], "net": "+5V"}, {"number": "2", "at": ["5", "0", "270"], "drill": ["1"], "net": "GND"}] | unchanged; manufacturer fit NOT newly verified
C5 | e1bf0896-2690-47cc-b34a-a6374d477679 | 1u | oneTesla:C_Disc_D7.5mm_W2.5mm_P5.00mm | ["41.315", "42.545"] | [{"number": "1", "at": ["0", "0"], "drill": ["1"], "net": "+15V"}, {"number": "2", "at": ["5", "0"], "drill": ["1"], "net": "GND"}] | unchanged; manufacturer fit NOT newly verified
C13 | e1eb67f7-0769-4c57-a480-830a7907fe19 | 100u 25V | oneTesla:CP_D8_P2.54_ReviewPending | ["43.815", "57.785"] | [{"number": "1", "at": ["-1.27", "0"], "drill": ["0.8128"], "net": "+15V"}, {"number": "2", "at": ["1.27", "0"], "drill": ["0.8128"], "net": "GND"}] | unchanged; manufacturer fit NOT newly verified
IC4 | e326c1c3-e31c-4f7c-989c-d81b384540bc | UCC37321P | oneTesla:DIP-8_W7.62mm_Socket_LongPads | ["40.005", "65.405"] | [{"number": "1", "at": ["0", "0"], "drill": ["0.8128"], "net": "+15V"}, {"number": "2", "at": ["0", "2.54"], "drill": ["0.8128"], "net": "Net-(IC2A-C)"}, {"number": "3", "at": ["0", "5.08"], "drill": ["0.8128"], "net": "/DRIVE_ENABLE"}, {"number": "4", "at": ["0", "7.62"], "drill": ["0.8128"], "net": "GND"}, {"number": "5", "at": ["7.62", "7.62"], "drill": ["0.8128"], "net": "GND"}, {"number": "6", "at": ["7.62", "5.08"], "drill": ["0.8128"], "net": "Net-(C4-Pad1)"}, {"number": "7", "at": ["7.62", "2.54"], "drill": ["0.8128"], "net": "Net-(C4-Pad1)"}, {"number": "8", "at": ["7.62", "0"], "drill": ["0.8128"], "net": "+15V"}] | unchanged; manufacturer fit NOT newly verified
IC1 | e401bd33-165f-4baf-9227-aa5c08519578 | 74HCT14 | oneTesla:DIP-14_W7.62mm_Socket_LongPads | ["19.05", "55.245", "90"] | [{"number": "1", "at": ["0", "0", "90"], "drill": ["0.8128"], "net": "Net-(D1-K)"}, {"number": "2", "at": ["0", "2.54", "90"], "drill": ["0.8128"], "net": "Net-(IC1-Pad2)"}, {"number": "3", "at": ["0", "5.08", "90"], "drill": ["0.8128"], "net": "Net-(IC1-Pad2)"}, {"number": "4", "at": ["0", "7.62", "90"], "drill": ["0.8128"], "net": "Net-(IC2A-C)"}, {"number": "5", "at": ["0", "10.16", "90"], "drill": ["0.8128"], "net": "Net-(IC2A-C)"}, {"number": "6", "at": ["0", "12.7", "90"], "drill": ["0.8128"], "net": "Net-(IC3-IN)"}, {"number": "7", "at": ["0", "15.24", "90"], "drill": ["0.8128"], "net": "GND"}, {"number": "8", "at": ["7.62", "15.24", "90"], "drill": ["0.8128"], "net": "unconnected-(IC1-Pad8)"}, {"number": "9", "at": ["7.62", "12.7", "90"], "drill": ["0.8128"], "net": "GND"}, {"number": "10", "at": ["7.62", "10.16", "90"], "drill": ["0.8128"], "net": "unconnected-(IC1-Pad10)"}, {"number": "11", "at": ["7.62", "7.62", "90"], "drill": ["0.8128"], "net": "GND"}, {"number": "12", "at": ["7.62", "5.08", "90"], "drill": ["0.8128"], "net": "Net-(IC2A-~{R})"}, {"number": "13", "at": ["7.62", "2.54", "90"], "drill": ["0.8128"], "net": "Net-(IC1-Pad13)"}, {"number": "14", "at": ["7.62", "0", "90"], "drill": ["0.8128"], "net": "+5V"}] | unchanged; manufacturer fit NOT newly verified
J1 | e653be71-d40e-44ac-b3d0-19b2175e10f4 | IEC C6 | oneTesla:IEC_C6_CONFIRMAR | ["52.705", "-3.429"] | [{"number": "", "at": ["-6.5", "9.5"], "drill": ["3"], "net": ""}, {"number": "", "at": ["6.5", "9.5"], "drill": ["3"], "net": ""}, {"number": "1", "at": ["-7", "14.5"], "drill": ["1.5"], "net": "/AC_L"}, {"number": "2", "at": ["7", "14.5"], "drill": ["1.5"], "net": "/AC_N"}, {"number": "3", "at": ["0", "14.5"], "drill": ["1.5"], "net": "/PE"}] | unchanged; manufacturer fit NOT newly verified
R1 | f0ce8a38-c9cb-496c-a9db-58279ac7b519 | 1k 5W | oneTesla:R_L25_P30.48_Provisional | ["11.43", "86.36", "90"] | [{"number": "1", "at": ["-15.24", "0", "90"], "drill": ["1.3"], "net": "Net-(T3-S1)"}, {"number": "2", "at": ["15.24", "0", "90"], "drill": ["1.3"], "net": "Net-(D1-K)"}] | unchanged; manufacturer fit NOT newly verified
Q2 | f4611130-8dad-4440-abb7-6f721649d1a2 | FGA60N65SMD | oneTesla:Q_TO3P_ImportedPads_ReviewPending | ["71.9455", "63.765", "-90"] | [{"number": "1", "at": ["0", "0"], "drill": ["1.4986"], "net": "/GATE_L"}, {"number": "2", "at": ["5.45", "0"], "drill": ["1.4986"], "net": "/SW_NODE"}, {"number": "3", "at": ["10.9", "0"], "drill": ["1.4986"], "net": "/DC_MINUS"}] | unchanged; manufacturer fit NOT newly verified
Z1 | f8de40fa-b032-4279-8663-0ebc81eb5e73 | 1.5KE510CA | oneTesla:D_DO201AD_P14.732_ReviewPending | ["78.105", "48.895", "-90"] | [{"number": "1", "at": ["-7.366", "0", "270"], "drill": ["1.1"], "net": "/DC_PLUS"}, {"number": "2", "at": ["7.366", "0", "270"], "drill": ["1.1"], "net": "/SW_NODE"}] | unchanged; manufacturer fit NOT newly verified
C11 | fe62df3f-686e-4249-812d-c21aae89a436 | 1000u 200V | oneTesla:CP_D30_P10.16_ReviewPending | ["125", "60"] | [{"number": "1", "at": ["-5.08", "0"], "drill": ["2"], "net": "/DC_MID"}, {"number": "2", "at": ["5.08", "0"], "drill": ["2"], "net": "/DC_MINUS"}] | unchanged; manufacturer fit NOT newly verified

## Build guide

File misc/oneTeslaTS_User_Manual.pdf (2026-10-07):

© 2019 oneTesla LLC

# oneTeslaTS DIY Tesla Coil Kit

## User Manual v1.8

# Running list of errata

You are currently reading version 1.8 of the oneTeslaTS User Manual. Before continuing, go to onetesla.com/downloads and check that v1.8 is the most up-to-date version. If not, download the errata or the latest version of the manual. This page will be continuously updated with corrections.
March 2015 | Some early kits will have 47mm tall 1000uF bus capacitors, while others will have shorter capacitors. One of the screws in the bottom secondary endcap bumps into the tall capacitor by a fraction of a millimeter. We recommend omitting the third screw in the endcap, as is noted in step 10. It will not affect mechanical stability of the secondary.
| Note that there are two incorrectly printed part values on the SD interrupter board: a 1K resistor which should be 100 ohms, and a 7805L that should be a 7833. See step 1 for details.
| There may be a few extra M3 6mm screws in your kit.
| In Step 5, the color code of R4 was incorrectly listed as 3.3K (orange orange red). The correct resistor is 3.3Ω (orange orange gold gold).
| In Step 5, IC4 was incorrectly listed as UCC37322. It has been corrected to UCC37321. All references to UCC37322 have been changed to UCC37321.

User Manual v1.8 | iv

April 2015

June 2015

July 2016

September 2016

December 2016
April 2019

Double-check that your sil-pads are large enough to cover the entire IGBT as it’s possible that some smaller sil-pads got included in your kit accidentally. Contact us for the correct size sil-pads if this is the case.
In Step 10, added more detailed end cap assembly instructions and diagrams.
Some kits were shipped with boards that are only silkscreened on one side. In this case, please just solder the top of the board. SD cards no longer need to be 2GB or smaller. Steps re-ordered so end cap assembly is prior to varnishing. In Step 4J, maximum soldering temperature for the optical receiver was corrected to read 250 degrees instead of 400.
Added more specific instructions for how to operate the SD card interrupter.
Updated the placement of the breakout point.
Updated R9 resistor information. Removed reference to D2 on the main board. Fixed typo regarding 15V rail, pin 6 (was
previously marked as pin 8) in the Troubleshooting the Driver Logic section. Noted that the secondary coil should read 750Ω, not continuity.

# Welcome to the world of

high voltage.

You’ve made a good choice with the oneTesla TS kit, the most compact and high-performing Tesla coil kit you will find.
The oneTeslaTS is a respin of our first, immensely popular Tesla coil kit. We’ve listened to feedback from hundreds of oneTesla v1 kit builders and redesigned the electronics and mechanical assembly with a focus on easy construction. You don’t need to be an expert in power electronics to get yourself beautiful singing sparks!
How well the kit works, however, is dependent upon your careful workmanship. This is a complex kit, so it’s not unusual to need a few tries to get it right. Hardware construction requires attention to detail, and patience in tracking down problems. Solder carefully, follow the instructions closely, and don’t be afraid ask for help when you need it.
Be patient and persistent, and you’ll learn a lot and have a successful build.
Read and understand the entire manual, as well as tutorials on our website at onetesla.com/tutorials, before beginning! It’s important that you understand how the Tesla coil works in order to build it correctly and handle it safely. Ensure that you are comfortable working with all of the hazards listed on the following pages. You should not construct this kit without supervision if you are under 18.

Need help?
Go to our support forum at onetesla.com/forum

Need replacement parts? Contact us at replacements@onetesla.com

Check out all of our educational tutorials at onetesla.com/tutorials

Check out our other kits at www.onetesla.com!

Note: We try our best to keep all images and instructions consistent with the latest revision of the oneTeslaTS hardware, but the photos in this manual and on our website are not always identical to the components you receive in your kit. They will, however, maintain the same functionality.

# What’s in the oneTeslaTS kit?

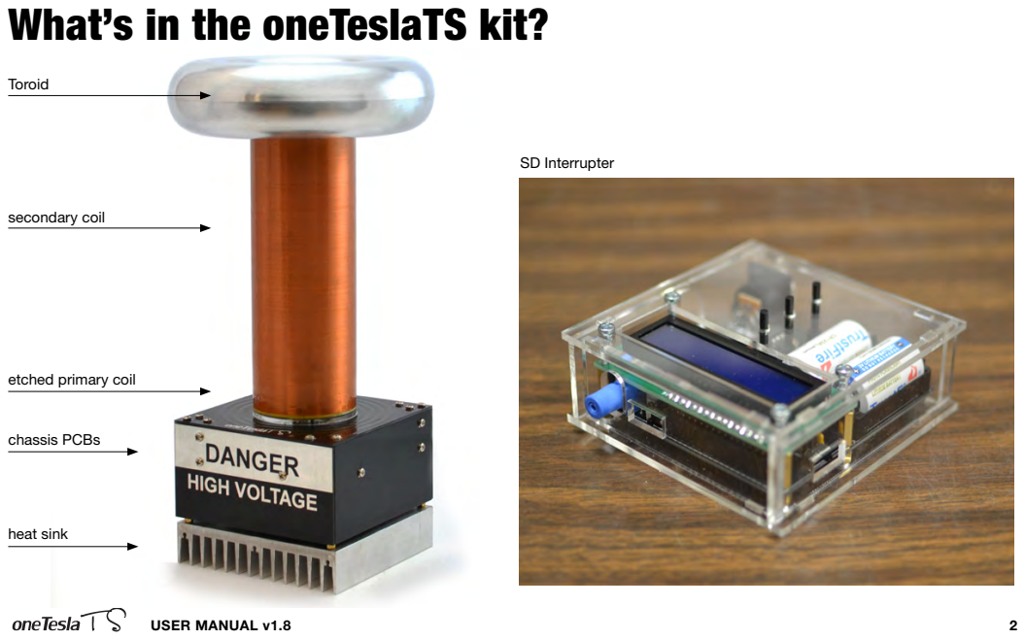
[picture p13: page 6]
User Manual v1.8; SD Interrupter; secondary coil; chassis PCBs; heat sink; Toroid

etched primary coil

Safety Warnings | Electrical Safety Warning The Tesla coil creates extremely high voltage and high frequency sparks. NEVER TOUCH THE OUTPUT OF THE TESLA COIL. At best, you will get a nasty burn; at worst, you’ll get a potentially life-threatening shock. The Tesla coil’s control board is also dangerous while the bus capacitors are charged. NEVER SERVICE THE BOARD WHILE IT IS POWERED ON. ALWAYS WAIT AT LEAST FIVE MINUTES AFTER THE BOARD IS POWERED OFF FOR CAPACITORS TO DISCHARGE BEFORE SERVICING. Adult Supervision Required Users under 18 should only use this kit under the supervision of an experienced adult. Pacemaker Warning Persons with electronic medical implants such as pacemakers should not be near the Tesla coil during operation. EMI from the coil may interfere with the pacemaker’s function. Ear Protection Recommended The Tesla coil output is loud. Ear protection is recommended.

The high temperature of the Tesla coil streamers causes the gases that make up air to form other compounds, including ozone (which can often be smelled when the coil is in operation) and nitrogen oxides. Keep the Tesla coil work area well-ventilated to prevent the buildup of irritating gases such as ozone and nitrogen oxides, which become toxic if concentrated.

The arcs from the Tesla coil can set flammable objects on fire. Keep all flammable objects away from the Tesla coil while it is

Always wear eye protection while soldering. Power semiconductors may overheat and fail violently, causing a shrapnel hazard. Wear safety glasses when working on the board while it is energized. Only power up the board when it is fully

Keep sensitive electronics away from the Tesla coil at all times. Use the entire length of the included fiber optic cable to distance

# Before you begin

## Be up-to-date

Ensure you have the latest version of the manual, and if not, download the errata sheet or the newest version at onetesla.com/downloads.

## Read the tutorials

All of our tutorials can be found at onetesla.com/tutorials n Soldering tutorial
(onetesla.com/tutorials/how-to-solder)
n De-soldering tutorial
(onetesla.com/tutorials/how-to-desolder)
n How a Tesla coil works
(onetesla.com/tutorials/how-a-tesla-coil-works)

## Observe good workspace practices

n Keep your workspace neat and orderly.
n Always obey common sense.
n Do not continue work if at any point you feel uncomfortable with the hazards a challenging electronics project poses.
n Use caution when soldering. Lead is hazardous, and the iron is extremely hot.

## Have the right equipment

Having the proper tools for electronic assembly, particularly a powerful enough soldering iron, will make your life much easier! Here are the tools you need to assemble your Tesla coil:
n temperature-controlled soldering iron, 40W minimum n rosin-core solder of an appropriate thickness
n safety glasses
n small pliers
n flush cutters
n wire strippers
n small screwdriver
n super glue
n multimeter
n spray-on or paint-on varnish n fine grit sandpaper

Optional but useful:
n packing tape
n masking tape
n solder wick or other desoldering tools n oscilloscope and power supply

User Manual v1.8 | 6

## Safely work with electrical hazards

Always be in control of the power source. Use a power strip and have the switch within your reach at all times.
Wait 5 minutes after unplugging the driver board for capacitors to discharge before servicing the board.
When debugging, don’t wear jewelry that could accidentally come into contact with circuitry and cause short-circuits.
Never work on something dangerous when you’re alone.
If you feel tired or uncomfortable at any point, take a break and come back to your work later.
If you have any hesitation about the nature of the high voltage circuits you are probing, work with one hand in your pocket. This prevents you from inadvertently touching a grounded object with your other hand when probing something that is potentially high voltage, which could cause a short-circuit across your chest.
Ask for help when you need it! Better to ask a question in advance than do something damaging or dangerous. We’re here to help on onetesla.com/forum.

# Step 1: Assemble the SD Interrupter

Heat up your iron! Let’s start soldering. We’ll begin with the SD card interrupter because we need it working to test the Tesla coil’s electronics later on.
A. Install resistors R1 through R10.
B. Install capacitors C1 through C5.
C. Install sockets for IC2, IC3, and IC4. Align the notch on the socket to the notch pictured on the board.
D. Install D1.
E. Install the slide switches.
F. Install the 16-pin female header for the LCD.
G. Install IC1 (a 78L05 5V regulator) and IC5 (a 3.3 V regulator). See image.
H. Install 16MHz crystal Y1.
I. Install the optical transmitter.
J. Install the two CR123A battery holders. Ensure that the + mark on each socket aligns with the + mark on the board!
K. Install J2, the MIDI jack.
L. Install the tall pushbutton switches S1, S2, and S3.
M. Install the ICs in their sockets, taking care to orient them correctly.
N. Solder the male header pins into the LCD module.
O. Place the LCD module into the female header pins on the board. You don’t need to install the standoffs yet, as you should confirm that the board works before finishing the mechanical assembly.
P. Install the batteries, taking care to orient them correctly.
R1, R10 | 10kΩ (brown black orange)
R2, R7, R8, R9 | 1kΩ (brown black red)
R3 | 100Ω (brown black brown)
R4 | 100kΩ (brown black yellow)
R5 | 3.3kΩ (orange orange red)
R6 | 220Ω (red red brown)
C1, C2, C5 | 1uF (labeled 105)
C3, C4 | 18pF (labeled 180)
D1 | 1N4148
| 2x Slide switch
| LCD headers
IC1 | 7805
IC2 | ATMega328
IC3 | 4N25
IC4 | 74HC4050
IC5 | 3.3V regulator (note that early boards are mislabeled)
Y1 | 16MHz crystal

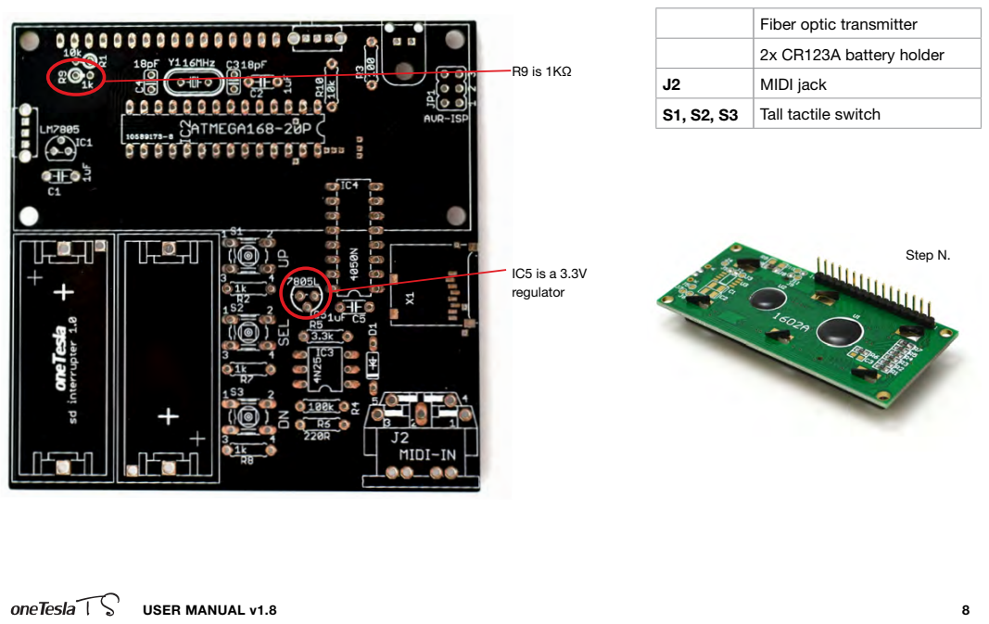
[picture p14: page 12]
User Manual v1.8; IC5 is a 3.3V regulator; Step N.

Fiber optic transmitter
2x CR123A battery holder

J2 | MIDI jack
S1, S2, S3 | Tall tactile switch

# Step 2: Test the SD Interrupter

Power on the interrupter. Depending on whether or not you have a micro SD card installed, you should be greeted with either “Fixed Mode” or “No SD card found” on the display. Press [Down] until you see “Fixed Mode”, then press [Select] to launch fixed mode. Look into the optical transmitter and verify that you see a blinking red light. If you do, hooray, your interrupter works! Proceed to step 3.
If no display is
present...

If no backlight is
present...

If the display is
present but the LED
does not light...

If the buttons
don’t work...

n Make sure all ICs are correctly installed in their sockets.
n Measure the voltage between pins 7 and 8 of the ATMega328 and confirm that it is 5 volts. If it is not, check for soldering errors around the 78L05 regulator and the pins of the ATMega328.
n Make sure R1 and R9 are not switched. Swapping R1 and R9 will cause extremely low contrast on the screen.
n Try switching on the backlight. In bright lighting conditions the screen may be hard to see without
a backlight.
Lack of a backlight indicates that the 5V rail is absent. Check for shorts on the board. Verify that the batteries are installed in the correct orientation.

n Check the soldering of R3 and the fiber transmitter.
n Check the ATMega328, particularly pin 4.
n Confirm that the fiber transmitter is not mechanically damaged.

Check the soldering of the buttons and the 1K resistors next to them. Be gentle with the buttons, as they are tall and too much sideways force will damage them.

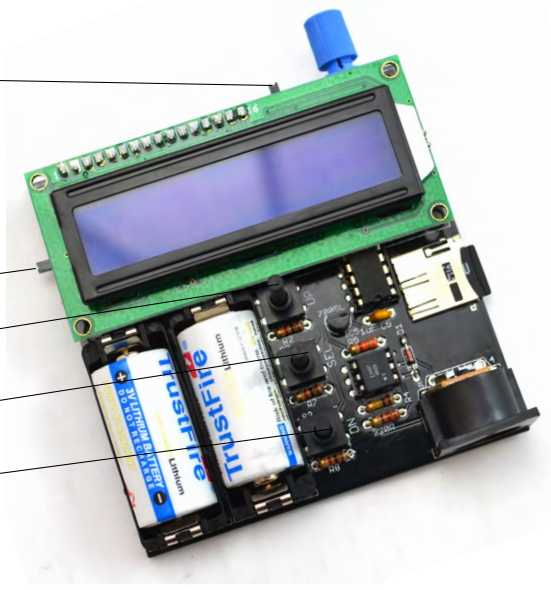
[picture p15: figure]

User Manual v1.8 | 10

Testing that the basic interrupter functionality works will let you test your coil. If you want to do more advanced troubleshooting go to step 17.

Backlight switch

On/Off switch

[Up]

[Select]

[Down]

Need help?
If you encounter a problem that isn’t covered here, take a look at our online help forum at onetesla.com/forum. Someone else may have had the same problem and figured out
a solution.

Please post on the forum rather than emailing us for support, so that everyone can learn from how you resolved your problem!

User Manual v1.8 | 11

## Operating the SD card interrupter

To turn on the SD card interrupter, use the switch on the side. To turn on the backlight, use the switch on the top. Connect the interrupter to the coil using the optical fiber. One end of the optical fiber connects to the blue optical transmitter on the SD card interrupter, and the other end connects to the black optical receiver on the coil.
The SD card interrupter has four modes: Fixed, Burst, SD card, and Live.
n Fixed mode is used to test the frequency and volume of the coil without playing a song. Use the Select button to toggle between frequency and volume and the up and down buttons to adjust them.
n Burst mode is still in beta. Try at your own risk!
n SD card mode allows the interrupter to read your SD card. Use the Up and Down buttons to scroll through your list of songs, and the Select button to play a song. To stop playing a song, press Select. While a song is playing, use the up and down arrows to adjust the volume.
n Live mode is used when a MIDI instrument (such as a guitar or keyboard) is plugged into the interrupter’s MIDI jack. Adjust the volume using the Up and Down buttons.
To change the batteries, remove the front panel of the interrupter.

# Step 3: Assemble the Interrupter Case

A. Peel the protective layer off of the plastic parts.
B. Start by attaching the board to the bottom plate of the chassis. Use the short standoffs to space the board from the bottom plate. Use 6mm screws through the acrylic to hold the standoffs in place.
C. Screw the tall standoffs to the top of the short ones.
D. Place the LCD screen into its socket.
E. Assemble the sides of the case by inserting the tabs into the holes in the base plate.
F. Install the top plate. Note that the buttons are slightly off-center, so if your top plate isn’t fitting quite right, flip it around.
G. Use 13mm screws to hold the case together. Don’t over-tighten!

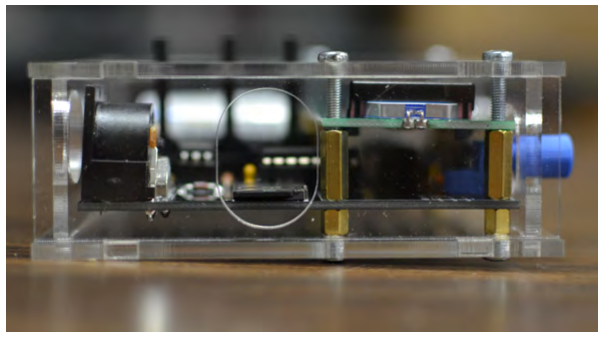
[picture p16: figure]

A. Install R1. Note that is a large, rectangular, ceramic, 5-Watt power resistor.
B. Install R2–R6. ENSURE THAT R5 AND R6 ARE INSTALLED PROPERLY. They are two 1/2W bleeder resistors which drain the bus capacitors when the unit is powered off. Failure to install R5 and R6 properly will result in the capacitors storing energy for extended periods of time, and a board that is unsafe to service.
C. Install capacitors C1–C6. They are all identical 1uF ceramic capacitors.
D. Install capacitors C7–C10. These are electrolytic capacitors whose polarity is important. Be sure to match the white stripe on the capacitor to the stripe on the board.
E. Install signal diodes D1 and D2. Note that these are directional components, and the stripe on the diode needs to match the stripe on the board.
F. Install rectifier D3. Note that it is directional.
G. Install the sockets for IC1–IC4. You will insert the ICs into the sockets later. Note that the sockets are directional, and the notch on the socket needs to match the notch on the board.

# Step 4: Install the Main Board’s Logic

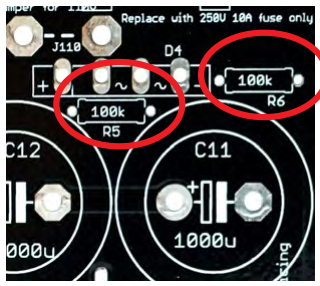
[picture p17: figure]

B.

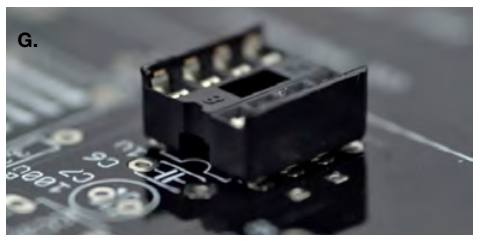
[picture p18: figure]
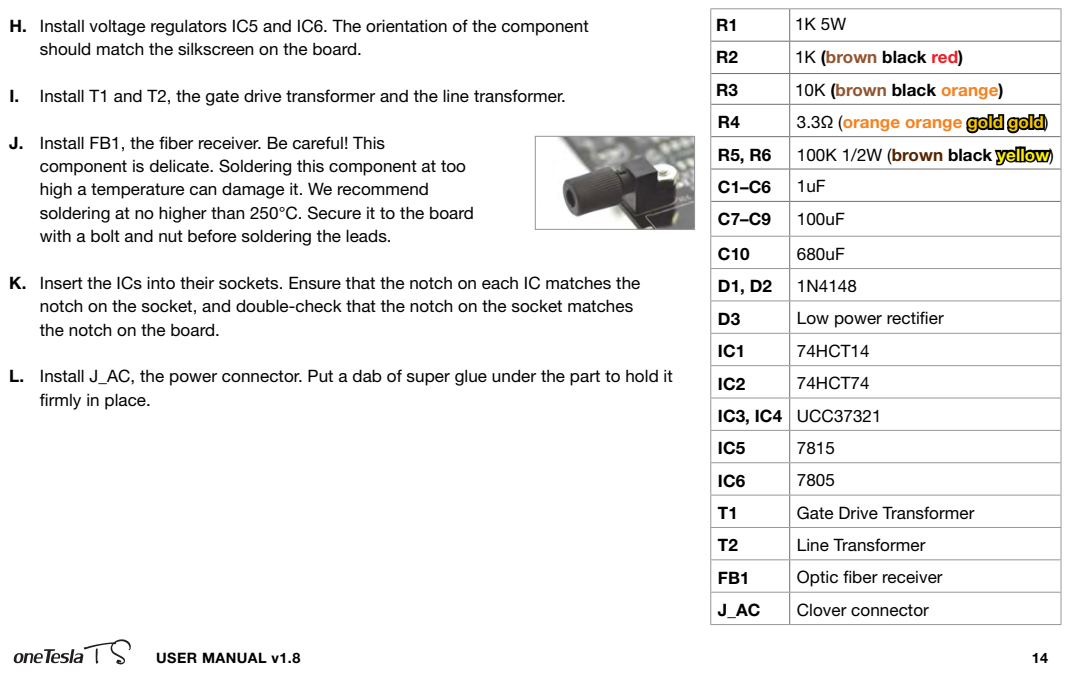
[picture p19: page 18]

R1 | 1K 5W
R2 | 1K (brown black red)
R3 | 10K (brown black orange)
R4 | 3.3Ω (orange orange gold gold)
R5, R6 | 100K 1/2W (brown black yellow)
C1–C6 | 1uF
C7–C9 | 100uF
C10 | 680uF
D1, D2 | 1N4148
D3 | Low power rectifier
IC1 | 74HCT14
IC2 | 74HCT74
IC3, IC4 | UCC37321
IC5 | 7815
IC6 | 7805
T1 | Gate Drive Transformer
T2 | Line Transformer
FB1 | Optic fiber receiver
J_AC | Clover connector

H. Install voltage regulators IC5 and IC6. The orientation of the component
should match the silkscreen on the board.
I. Install T1 and T2, the gate drive transformer and the line transformer.
J. Install FB1, the fiber receiver. Be careful! This
component is delicate. Soldering this component at too
high a temperature can damage it. We recommend
soldering at no higher than 250°C. Secure it to the board
with a bolt and nut before soldering the leads.
K. Insert the ICs into their sockets. Ensure that the notch on each IC matches the
notch on the socket, and double-check that the notch on the socket matches
the notch on the board.
L. Install J_AC, the power connector. Put a dab of super glue under the part to hold it
firmly in place.

In this step, you will test the main board’s logic components and interrupter together at low power. Perform these steps only after you install the components in step 4, and BEFORE INSTALLING ANY POWER COMPONENTS. If you return to this step later,

REMOVE THE FUSE AND COVER THE LEFT FUSE HOLDER WITH ELECTRICAL
TAPE. This covers the hot lead of the holder and prevents you from accidentally touching it. Always wear safety goggles when handling an energized board!
Mount the board properly
First, mount your board on the heat sink to ensure that it’s mechanically sturdy and not sitting on anything that may short out the pins. Fasten short M-F standoffs into the holes in the corners of the heat sink. Note that if you have M3 washers in your kit, they are to shim the standoffs and make them a little taller. Place the washers against the heat sink and screw through them. Mount the board on the heat sink and use temporary M3 6mm screws to affix them.
Start-up procedure
Start with the driver board disconnected from all cables. First connect the interrupter using the 10 feet of optical fiber. Then, insert the IEC cable FIRST into the clover socket on the board. THEN plug it into an off power strip. Plug the power strip into an energized outlet. This ensures that you’re not handling the driver at the moment you plug it in. Turn on the power strip. Your board is now energized. Proceed with extreme caution!

# Step 5: Low-Power System Testing

Always use extreme caution when you are working with an energized board. Wear safety glasses.

User Manual v1.8 | 16

Check for Buzzing
Turn on the interrupter and turn up the volume. You should hear the interrupter’s tone faintly produced by the gate drive transformer on the driver board. If you hear the buzz, hooray, your logic components work! If not, proceed to troubleshooting the board’s logic. Troubleshooting the driver logic
We need to start by figuring out if the 5V and 15V supplies are functioning properly. Using a multimeter, measure across the (+) and (-) pins of the 4-pin bridge rectifier and confirm that there are about 24V. If not, first check the direction of the polar capacitors, the diode D1, and the rectifier itself.
If these components are properly installed, we need to figure out whether one of the ICs is faulty, as a faulty IC could drag the output of the transformer down. Remove all socketed ICs, and and check for the 24V rail again. If it is still not there, there is a soldering fault on the board. Check your soldering, especially around the voltage regulators (which have fine pin spacings and are most likely to
be faulty).
If removing the ICs fixes the problem, one of the ICs is faulty. Replace the ICs one by one—the one that causes the voltage to disappear is the one to replace.
After you have the 24V input working, measure the 5V and 15V rails. The most convenient places to do so are across pins 7 and 14 of the 74HCT14 (for the 5V rail) and across pins 1 and 6 of the UCC37321 (for the 15V rail). If the rails are not present, remove the ICs from their rails (the 74 series chips are on the 5V rails, the UCCs are on the 15V rails) and check if any of them are damaged in the same fashion as above.
If the rails are present and there is still no buzz, carefully check the board for bad solder joints or shorts. As a last resort, you may remove and replace the optical receiver, but keep in mind that removing this part typically destroys it, so proceed with caution. If you have an oscilloscope, you can check Appendix A for more comprehensive troubleshooting steps.

A. If you are operating on 110V, install J110. DO NOT INSTALL THIS
COMPONENT IF YOU ARE OPERATING YOUR KIT ON 220V. To populate J110, trim a piece of thick wire and strip the ends to fit the space on the board.
B. Install the fuse clips and insert the fuse. Note that the tabs on the fuse clips need to be on the outside so that the fuse can slide in between them.
C. Install rectifier D4. Note that it is directional!
D. Install T3, the current transformer.
E. Strip the ends of another piece of thick wire, place it through the hole in T3, and solder it into pads P1 and P2. See image below.

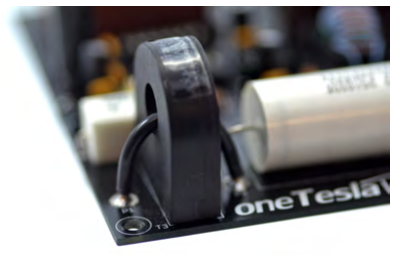
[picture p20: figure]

F. Install C11 and C12, the 1000uF bus capacitors. Note their direction!
G. Install CPRI, the primary tank capacitor.

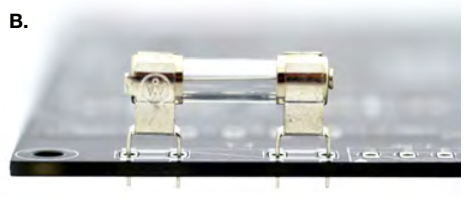
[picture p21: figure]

C11, C12 | 1000uF
D4 | Power rectifier
F1 | 10A fuse and two clips
T3 | Current Transformer
| P1/P2 Jumper (insert through current trans-former)
J110 | Jumper for 110V

# Step 6: Install the Power Components

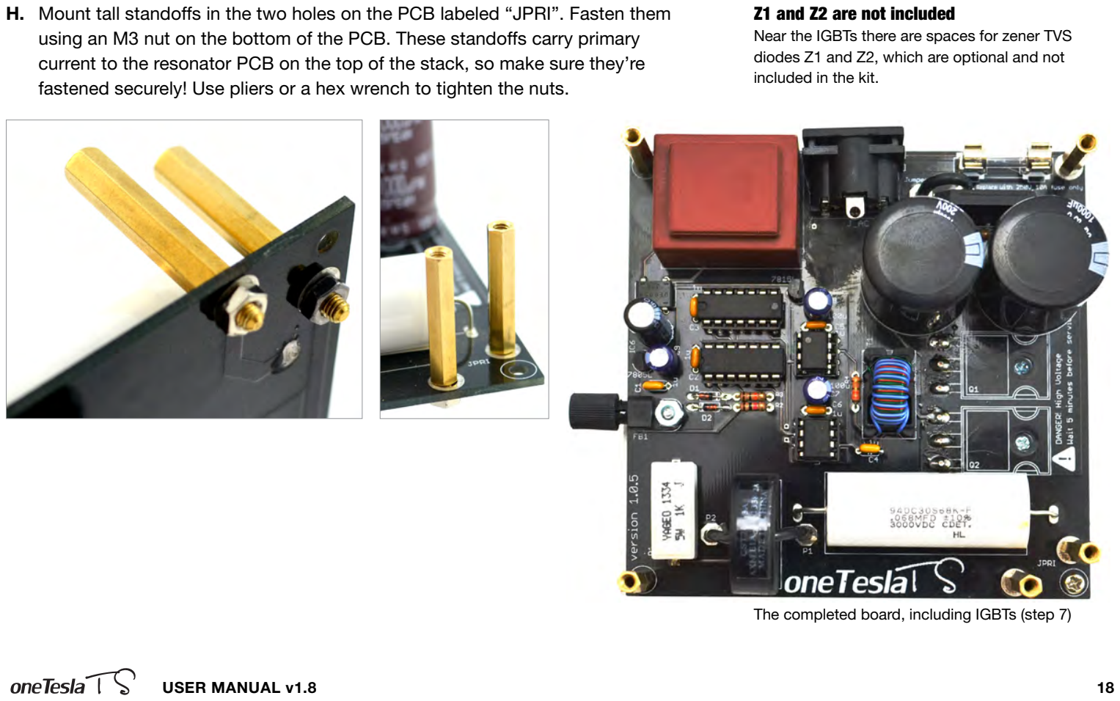
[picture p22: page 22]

User Manual v1.8 | 18
H. Mount tall standoffs in the two holes on the PCB labeled “JPRI”. Fasten them using an M3 nut on the bottom of the PCB. These standoffs carry primary current to the resonator PCB on the top of the stack, so make sure they’re fastened securely! Use pliers or a hex wrench to tighten the nuts.

Z1 and Z2 are not included
Near the IGBTs there are spaces for zener TVS diodes Z1 and Z2, which are optional and not included in the kit.

The completed board, including IGBTs (step 7)

# Step 7: Install the IGBTs

The IGBTs are mounted flush against the heat sink, and their leads are soldered to the top of the PCB. Sil-pad is an electrically insulative but thermally conductive material, which allows heat from the IGBTs to be transferred to the heat sink to dissipate, but insulates it electrically.
A. Clean the surface of the heat sink in the area of the IGBTs thoroughly. Make sure there’s no dirt or grime.
B. Screw in the IGBTs using 10mm M3 screws, using sil-pad to isolate the IGBT from the heat sink. Ensure there’s no contact between the IGBT and the heat sink. Screw them down securely, so that they don’t move when you put force on the leads.
C. Bend the leads of the IGBTs 90 degrees at the point where the legs
become thinner.
D. Place the PCB over the IGBTs and insert the legs through the holes in
the board.
E. Next, make the board mechanically secure by screwing in three 25mm standoffs into the holes at the corner of the board. You may need to push hard and bend the leads of the IGBTs a little bit to make the board align.
F. Solder in the IGBTs. You can clip the leads or leave them long, which may make them easier to remove later on.

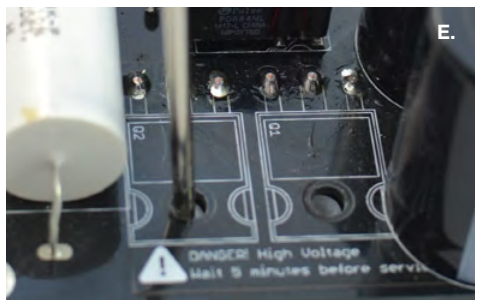
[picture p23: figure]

# Step 8: Finish soldering the PCBs

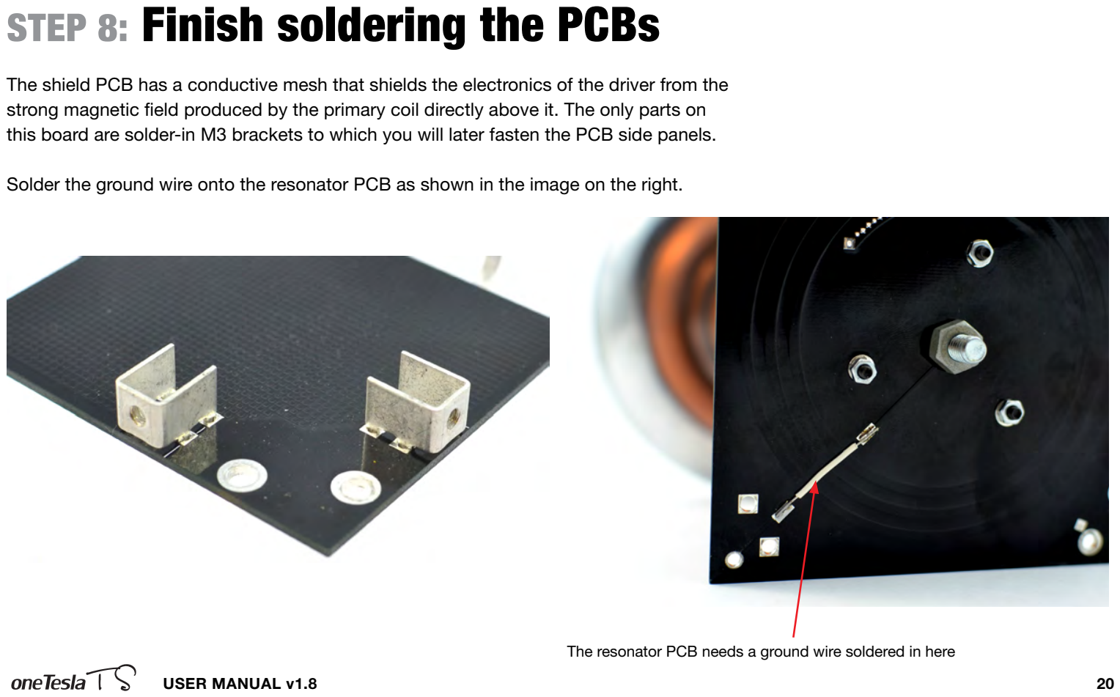
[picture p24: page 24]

User Manual v1.8 | 20

The shield PCB has a conductive mesh that shields the electronics of the driver from the strong magnetic field produced by the primary coil directly above it. The only parts on this board are solder-in M3 brackets to which you will later fasten the PCB side panels. Solder the ground wire onto the resonator PCB as shown in the image on the right.

The resonator PCB needs a ground wire soldered in here

First, solder ring terminals to the leads at each end of the secondary coil. Use fine-grit sandpaper to sand the enamel off the wire. If the end of the wire breaks, gently unravel some more.
There are two endcaps: top and bottom. The bottom endcap is affixed to the resonator board, while the top one holds the toroid
in place.
The endcaps have a specific assembly order. Included in your kit are two each of six different caps, labeled below.

# Step 9: Assemble the Secondary

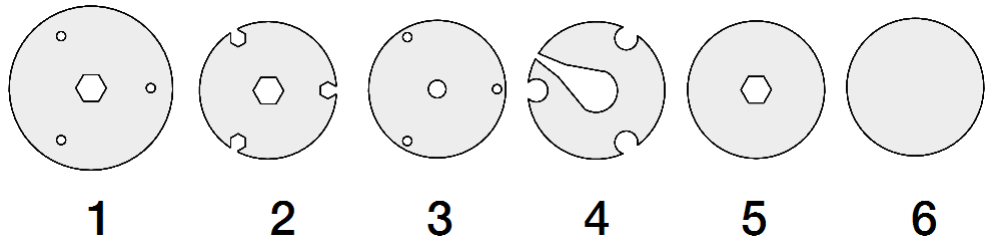
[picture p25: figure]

Broken wire?
If the wire breaks, simply peel off more wire from the top of the coil. Use a razor blade to separate out the top turn of wire.

Need help?
View our end cap and secondary assembly tutorial, available here: onetesla.com/tutorials/ oneteslats-endcap-assembly (http://onetesla.com/tutorials/oneteslats-endcap-assembly)

User Manual v1.8 | 22
A. Start by gluing endcap 5 to 6. Do this for both sets, as this applies for both the bottom endcap and top endcap assemblies.
B. We’ll then move onto the bottom endcap first. Assemble endcaps 2 and 3 by fastening them with the 15mm M3 screw and nuts. These two endcaps don’t need to be glued together.
C. Insert the M6 hex nut into the hex-shaped hole on endcap 2. Then, using the M6 nut and M3 screws for alignment, glue endcap 1 to endcap 2.

D. Flip the assembly over. Glue endcap 4 to endcap 3.
E. Insert a ring terminal (with secondary wire already soldered) into the assembly, clamping it down with the M6 bolt.
F. Now, glue the endcap 5 and 6 assembly to endcap 4.
G. If you unwrapped the bubble wrap from your secondary, you might want to

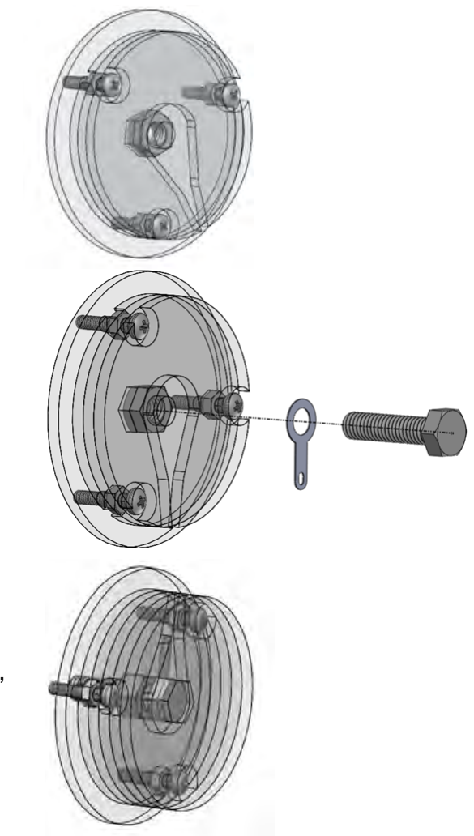
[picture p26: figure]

re-wrap it now to protect the wires. Then, insert the endcap into the secondary, and glue it in place. Make sure to glue this well, as this glue joint holds up the coil when you pick it up by its secondary.
You’ve now finished the bottom endcap! Good work! Now let’s move on to the
top one.

User Manual v1.8 | 24

For the top endcap assembly, the non-center holes aren’t used, so you don’t have to align them (don’t worry, the inner endcap assembly is not visible once the full secondary is assembled). The center holes still have to be aligned.
H. Glue endcaps 1 and 2 together, using an M6 hex nut to correctly align them.
I. Temporarily using an M6 bolt to align the center holes, glue endcap 3 to endcap 2. Remove the bolt once the glue is dry.
J. Next, glue endcap 4 to endcap 3.

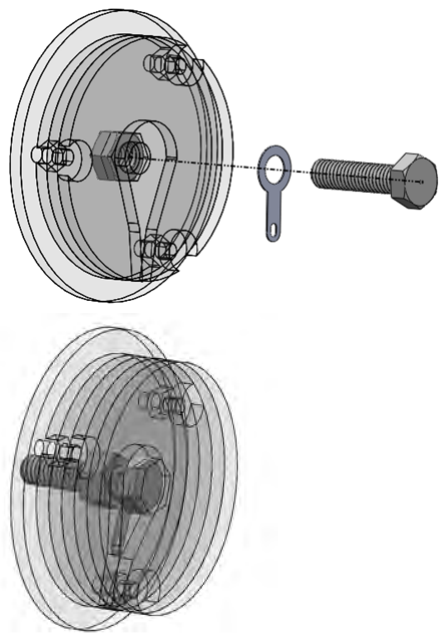
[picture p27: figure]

K. Insert a ring terminal (with secondary wire already soldered) into the assembly, clamping it down with the M6 bolt.
L. Now, glue on the endcap 5 and 6 assembly to endcap 4.
M. Make sure the secondary is protected by bubble wrap, and then glue the top secondary endcap assembly in place on the secondary. If you’re wondering which glue to use, hot glue is great because it’s sturdy enough to hold the coil together, but if you make an error you can still force apart the pieces. If you prefer your coil to be more drop-proof, use super glue or epoxy. Note that super glue clouds acrylic, so use it sparingly!

User Manual v1.8 | 26
N. Using a multimeter, ensure that the coil reads 750Ω between the bolts at
either end.

Note: If your 1000uF bus capacitors are tall (>45mm), one of the small bolts in the bottom endcap will colllide with them. If you have tall bus caps, simply OMIT one of the three bolts. As there are still three mounting points, mechanical stability will not be affected. Please note: No loose wires should be hanging inside the secondary after assembly. Loose wires can cause internal arcing and will damage the secondary.

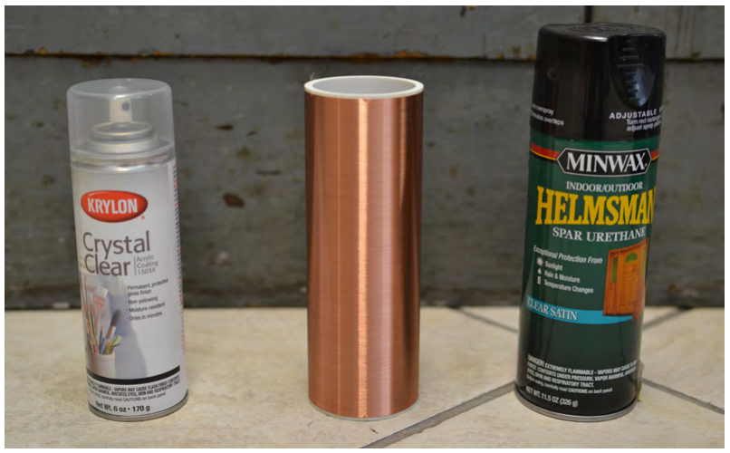
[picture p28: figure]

User Manual v1.8 | 27

# Step 10: Varnish the secondary

The secondary needs to be varnished before using your coil at any more than the lowest power setting. We recommend a few coats of spray-on or brush-on clear polyurethane. For best results, spin the coil slowly as it dries. Make sure you don’t accidentally varnish over the free wires on the ends of the secondary!

Tip: Use packing tape
Carefully applied packing tape without air bubbles underneath can help insulate your secondary. You can place it on top of some layers of varnish for extra durability. Be sure to fully smooth out the tape and remove the bubbles inderneath! There’s a big difference between a good tape job and a bad one.

# Step 11: Assemble the PCB Stack

In this step you will assemble the Tesla coil without its side panels. We recommend leaving off the side panels while doing your first runs and troubleshooting so that you can more easily detect any problems that may arise.
A. Stack the driver and shield boards as shown in the image.
B. Affix the secondary coil to the resonator board. If you have extra-tall bus capacitors and omitted one of the bolts, take care to orient your secondary coil properly!
C. Place your resonator board on the top of the stack and secure it with
6mm screws.
D. Screw on the toroid with the M6 nut.

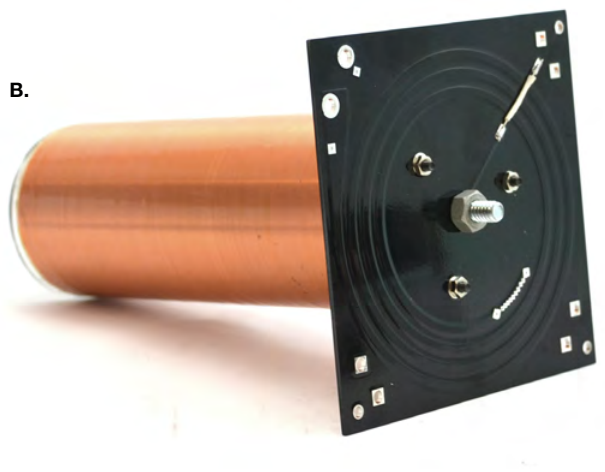
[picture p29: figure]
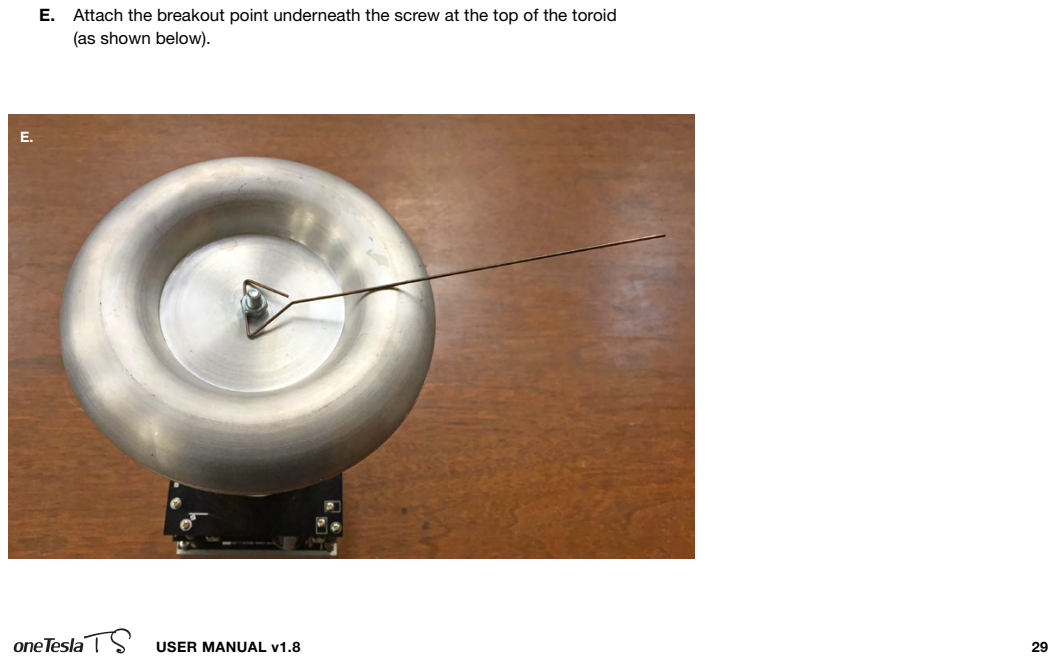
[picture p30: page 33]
User Manual v1.8

E. Attach the breakout point underneath the screw at the top of the toroid
(as shown below).

Installing the side panels is mandatory. Note that due to inductive heating, they decrease performance slightly. Mount the brass angle brackets onto the side panels using a screw and nut, as shown
in the photo below. To mount them to the coil, use a 6mm screw through the resonator PCB to thread into the threaded portion of

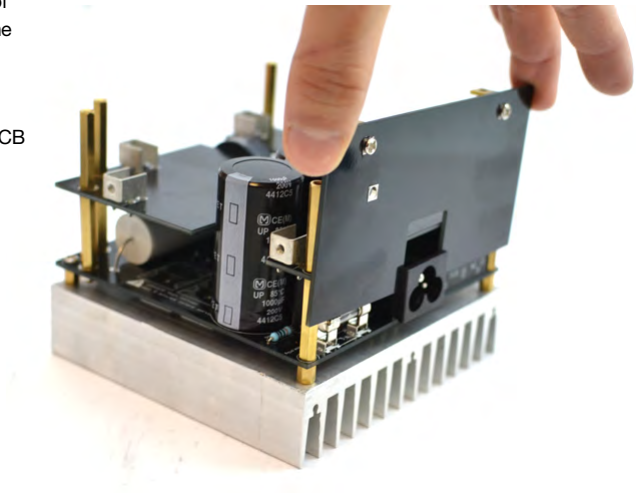
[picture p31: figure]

the angle bracket. Also use a 6mm screw to affix the panel to the brackets on the shield board.
Note that for most kits, you will need to remove the resonator board to install the panel on the side with the IEC jack, as the PCB side panel provides strain relief for the part.

# Step 12: Side Panel Installation

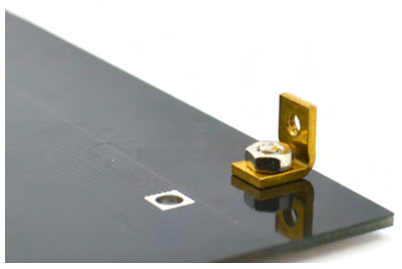
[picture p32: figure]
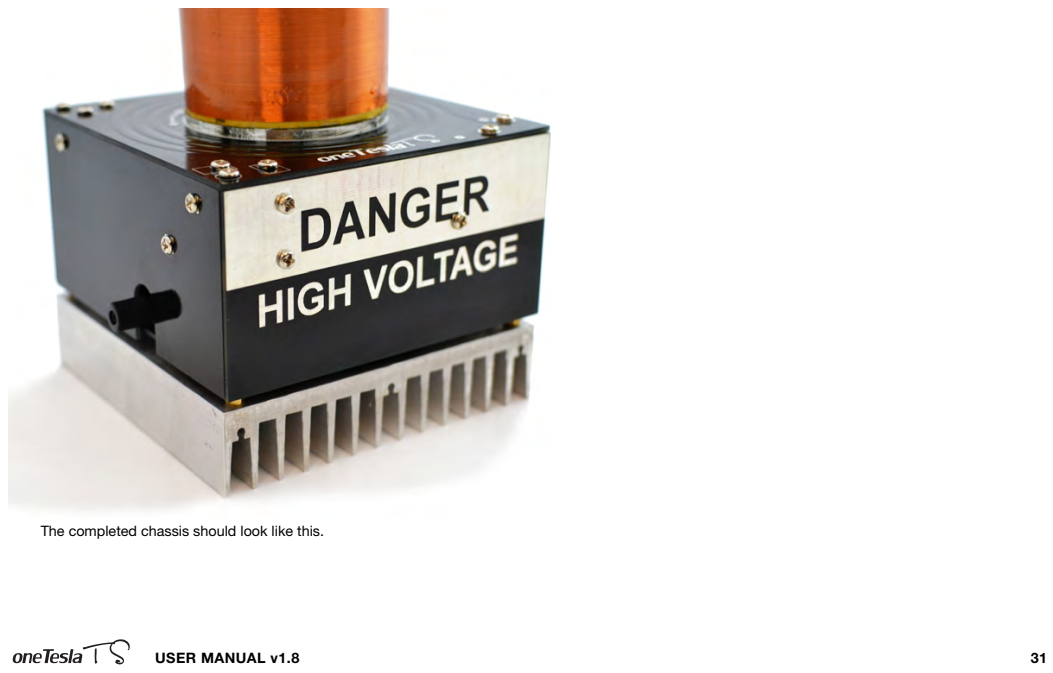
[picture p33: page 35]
User Manual v1.8

The completed chassis should look like this.

# Step 13: Tesla Coil Setup Rules

We are now ready to power test the coil! Before we do so, we
want to do some final checks. Reference this step before each
time you run the coil.
n Make sure the breakout point is installed. Failure to do so will result in a Tesla coil that is unable to discharge itself, causing high currents to build up in the driver and likely damage to the bridge.
n Make sure the Tesla coil is running in the proper environment. DRSSTCs are very sensitive to their environment, as running on a poorly grounded surface or too close to conductive objects results in altered toroid capacitance and a shift in the tuning point. The best place to run a TS is on a floor away from other objects. If you’re running on a table or unsure about the ground situation, place a sheet of aluminum foil or aluminum window screen below your coil. You can even cover the conductive plane with a cloth to improve its aesthetics! Just be sure to use an alligator clip to connect the coil’s heat sink to the conductor.
n Ensure that the outlet your power strip is connected to has good grounding (this means no portable generators, inverters, or 2-pronged outlets).

n Make sure that you are spacing yourself, your interrupter, your MIDI device, and any other sensitive electronics the full length of the optical fiber from the coil (10
feet minimum).
n Persons with pacemakers or other medical implants should not be in the vicinity of the coil.
n Always start at minimum power and ramp up slowly. This makes it easier to catch problems without damaging the coil.
n If you are using a laptop as a MIDI source, make sure it is not plugged in, or, if it is, make sure it is plugged in to an isolated adapter. Do not use a desktop computer to control the coil.
n The Tesla coil is tuned to operate best in a standard environment which we feel is typical of the conditions most users will operate it in. Some variation moving from location to location is expected.
n The radiated electric field has a tendency to temporarily cause nearby capacitive touchscreens and laptop touchpads to misbehave. This is normal, and will not permanently damage your electronics. If this happens, just move further away from the coil.

User Manual v1.8 | 33

# Step 14: Startup and Shutdown Procedure

Startup procedure
A. First, verify that your interrupter is behaving normally. Look into the output of
the fiber transmitter and verify that the output is behaving as you expect it to.
B. Start with the driver board disconnected from all cables. First connect the interrupter using the 10ft of optical fiber. Then, insert the IEC cable FIRST into the clover socket on the board. THEN into an off power strip. Plug the power strip into an energized outlet. This ensures that you’re not handling the driver at the moment you plug it in. Turn on the power strip. Your board is now energized. Proceed with extreme caution!
C. Distance yourself the full length of the optical fiber away from the coil. Power up the interrupter on LOW power, and watch the coil carefully for any problems as you slowly turn up the power.
If this is your first time powering up the coil...
D. In Fixed Mode on the interrupter, press and hold the [Up] button to set the frequency to 1000Hz (the maximum). We recommend a high frequency for a first test because higher frequencies draw less power from the coil.
E. Press [Select] to switch to Power control, and then [Up] to slowly increase the power. Watch the secondary for flashover, and make sure the tone being emitted by the coil stays clean-sounding.
Shutdown procedure
F. Turn off the interrupter, then shut off the power strip and unplug the coil. Wait 5 minutes before servicing the board to let the bus capacitors discharge.

Every time you turn on the coil
Reference this startup procedure every time you turn on the coil!

Every time you turn off the coil
To turn off the coil, FIRST cut the interrupter signal first, THEN shut off the power strip and unplug the cord. Cutting off the coil from AC power while the interrupter is still sending a signal can cause indeterminate states in the logic circuitry as the voltage rails sag, and can blow your IGBT bridge!

# Step 15: General troubleshooting

Nothing happens...

The fuse blows
immediately...

The fuse blows
during operation...

n Make sure the interrupter works (refer to Step 2).
n Make sure your coil passes Step 6, “Low Power Testing”. n Make sure the fuse is installed.
n Make sure the stack of standoffs that connect the driver board to the resonator board is securely installed, including the screws on the resonator board.
n Make sure the 78L05 and 78L15 are not switched.
n Make sure C4 and R4 are installed and properly soldered.
n Make sure the IGBTs are soldered in properly.
If the fuse blows immediately upon plugging in the coil, you have a severe solder bridge, a backwards rectifier D4, a backwards bus capacitor C11 or C12, or improperly isolated IGBTs. Unplug your coil immediately and inspect your driver for issues.
If immediately after the fuse blows you look at the output of the interrupter and see a solid red light that doesn’t turn off, your interrupter has latched up high, outputting a 100% duty cycle and overloading your coil. This is caused by the microcontroller crashing, which is typically due to being too close to the coil with your interrupter and picking up noise. It can also be caused by a low battery level.
Other causes of failure during operation include running the coil at high power for too long, drawing too
much current from the coil by pulling an arc with a metal object, or running at high power in a non-optimal environment that de-tuned the coil.

A dead bridge is a dead short
If you attempt to re-test your coil right after a severe failure by simply putting in a new fuse and trying again, you’re likely to just blow the new fuse as well. A damaged bridge acts as a dead short and will blow fuses instantly, possibly also tripping a circuit breaker upstream. Check your IGBTs if you’re in doubt!

User Manual v1.8 | 35

The coil works, but
the output does not
sound clean.

You hear a spark,
but don’t see it.

You see an
arc down
the secondary.

How to check your IGBTs
Use a multimeter to check that your IGBTs behave like a diode between pins 2 and 3. On a resistance measurement setting, the pins should read open in one direction and a near short in the other direction. Some multimeters have a diode test feature which shows you the diode voltage drop, which is a better test. A complete open or short in both directions indicates dead IGBTs.

Help, I don’t see my problem here!
We can’t predict every single failure mode that may happen. If you encounter a problem that isn’t covered here, take a look at our online help forum at onetesla.com/forum. Someone else may have had the same problem and figured out a solution.

Please post on the forum rather than emailing us for support, so that everyone can learn from how you resolved your issue!

n Make sure you and the interrupter are the full length of the fiber cable away from the coil.
n Switching IC1 and IC2 is known to cause this problem. n Make sure the coil is properly grounded.
n Make sure the batteries in the interrupter are fresh.
n Double-check your interrupter’s soldering. Bad joints will sometimes pick up noise from the coil.
Turning up the power when the spark doesn’t sound clean or is performing weakly will not make the problem go away! It’s better to not increase the power, but try to track down the problem. Your driver is working (hooray!) but there is internal flashover inside the secondary. You can confirm this is the case by watching your Tesla coil in a dark room and observing a glow from the acrylic cap on the bottom of the secondary, indicating the spark is on the inside. Check for dangling wires or bits of glue or other stray debris inside the tube. Use a flat-tip screwdriver to pry off the endcap. If you see burned tracks inside the secondary, use a file to remove them and drip some varnish over the area.
n Add more varnish to the secondary.
n Check your grounding.

The Tesla coil is a dangerous high voltage device. Used properly, it is an educational and fun electronics project that displays beautiful electrical arcs and lets you play with a unique form of sound creation. Used improperly, it can lead to serious injury. Always follow the directions! Treat your energized Tesla coil the same way that you would treat an open flame. You wouldn’t leave a burning stove unattended, nor let a child access matches and kerosene, would you? Don’t leave your Tesla coil unattended or in a situation where a child or

n Keep away from the coil while operating! Keep yourself, other people, and sensitive electronics a minimum distance of the length of the fiber optic cable apart from the Tesla coil. Persons with pacemakers or other medical implants n Never touch the output of the Tesla coil! The sparks will burn you if you come in n Always follow the startup and shutdown procedures when turning on and off
n Note that the output of the Tesla coil can be very loud. Always start your coil on low power and ramp up slowly. Don’t run your coil in a location where the noise

This is how we do it

To turn the coil on:
1. Plug the coil into a power strip.
2. Turn the power strip on.
3. Turn the interrupter on and choose a song.

To turn the coil off:
1. Turn off the interrupter.
2. Shut off the power strip.
3. Unplug the coil from the power strip.

User Manual v1.8 | 37

## Tips

The biggest issue to watch for is flashover on the secondary, or any arcing in places you don’t want it. Upon seeing unwanted arcing, stop operating immediately and fix
the problem.
If you’re using a laptop to control your coil, it should be running off of its battery and be unplugged from its charger.
It’s not a good idea to draw arcs from the coil using metal objects or a fluorescent gas tube, particularly at high power. Arcs draw a lot of current and can stress the IGBTs. A fluorescent tube put next to the Tesla coil will light up!
To avoid failures due to overheating, don’t run your coil for more than a few minutes at a time. If doing an extended run, use your coil on half power or less. It will prolong its run time and spare you from a migraine!
To make your life a little easier, use a power strip with an on/off switch rather than using the cord to plug in and unplug your Tesla coil.

Patching burned spots on the coil
When you have arcing on your secondary, you compromise the insulation. The situation will not get any better if you ignore it! A hefty dollop of glue over the burned spot will mitigate the problem. The picture above shows a successful repair job on a secondary that lasted a long time despite a small amount of arcing.

# Step 17: Test advanced interrupter functions

You will need a Micro SD card and, if you wish to test live MIDI functionality, a MIDI
source for this step. Files must be in .OMD format. To convert MIDI files to .OMD, use the
OMD Converter available at onetesla.com/downloads. For instructions, see Appendix B.
A. The card must be formatted as FAT. Most small SD cards likely have this file system by default, but if you are unsure, right-click on the drive and click “Properties”. The “Filesystem” entry should read FAT, not FAT32 or NTFS. If it does not, right-click, click “Format”, and select FAT from the drop-down box.
B. Copy one of the sample .OMD files from our site (onetesla.com/downloads) to the SD card.
C. Power on the interrupter. You should see “Fixed Mode” displayed on the screen. If the screen displays “No SD card found”, something is wrong.
D. Scroll down until the name of a .OMD file appears on the screen. Press [Select]. The LED inside the transmitter should light.
E. Press [Select] again to stop the song.

The most likely error you will receive in this case is the SD card not being detected. If so, check the following:
n Your SD card is formatted as FAT.
n Your SD card works and is detected by a computer.
n The 4050 IC is installed in the correct direction, and is properly seated.
n The socket for the 4050 IC is correctly soldered.
n IC5 is not a 5V regulator (early revisions of the board have a typo on the board where this IC is marked as a 78L05).

User Manual v1.8 | 39

It is very unlikely that the SD card is detected but songs do not play. In this case, check the MIDI files you converted from (which is why we suggest using one of our known-working sample files for the initial test).
If you have a MIDI source, you can test MIDI functionality as well:
A. Set your MIDI source to output on its lowest channel (usually channel 0) and connect the output to the MIDI jack on the interrupter.
B. Power on the interrupter, scroll to “Live Mode”, and select it.
C. Set your MIDI source to output a middle C. You should see the LED in the transmitter light up. It should turn off when you release the note.
If Live Mode does not work, check the following:
n Confirm that your MIDI device is outputting on the correct channel.
n Check the soldering and direction of IC3.
n Check the soldering of R4, R5, and R6.
n Make sure D1 is installed in the correct orientation.
n Make sure the MIDI jack is correctly soldered.

# Appendix A: General Troubleshooting Tips

Everyone finds troubleshooting frustrating. Have patience, be attentive to details, and
ask for help. You will have your coil performing beautifully in no time!
It’s impossible for us to cover every single failure scenario, and we’re not sure that a flowchart-style guide to a hundred different failure modes would even be that useful. Instead, follow these heuristic tips to chase down a bug.
n Visual inspection! We can’t stress enough that nothing beats manual hunting for incorrect components, wrong resistor values, or poor solder joints.
n Sometimes bad solder joints are invisible. Using a good soldering iron, reflow your joints and add a dab of fresh solder to shady connections. This alone fixes most of the problems that we encounter.
n The parts that most often break are logic ICs, not passives or power components. That’s why they’re socketed. If something dramatic happened to your coil, you will likely need to use a fresh set of silicon components.
n Inputs and outputs tell you a lot. Probably the most important troubleshooting technique is chasing signals through the circuit, datasheet in hand, until they vanish. When they vanish, that means one of two things: either the upstream IC producing the signal has failed, or the downstream IC receiving signal has a shorted input. The first step is to check around the pins for shorts. Barring that, try pulling the downstream IC. If that fixes the problem, simply replace the chip. Otherwise, the upstream IC needs replacement.
n The simplest solution is often the correct one. A non-working coil is probably the fault of a bad solder joint or IC, not because of some mysterious RF phenomenon, swollen capacitor, or voodoo curses.

Every problem has a cause!
Remember that every problem has a cause. Components are very rarely dead upon arrival. Blindly replacing chips can lead to a whole lot more dead chips if you don’t find the root cause!

How to ask for help
If you don’t find your answer in the manual, take a look at onetesla.com/forum.

If you don’t find your solution in threads that are already there, feel free to post about your issue. When posting to the forum, include as much information as possible about the symptoms you’re observing.

User Manual v1.8 | 41

# Appendix B: OMD converter

To play music on the oneTeslaTS, files MUST be converted from MIDI to .OMD format. The OMD converter (omdconvert.exe) is a command-line program. Download it at onetesla.com/downloads. You can run it by either dragging a file with a .MID extension onto its icon (PC), which will produce a file with the same name and extension .OMD, or by running it from the command line with “omdconvert.exe <filename>” (Mac). omdconvert.exe is also WINE compatible. Users of Unix-like operating systems should be able to run the converter via WINE. The source is built on top of the Improv library and should compile on most modern C++ compilers.

# Appendix C: Oscilloscope Guide

The oneTesla TS kit can be built without an oscilloscope. However, having a scope can be of great assistance in debugging. The following pages provide snapshots of key waveforms, along with tips for debugging the coil.

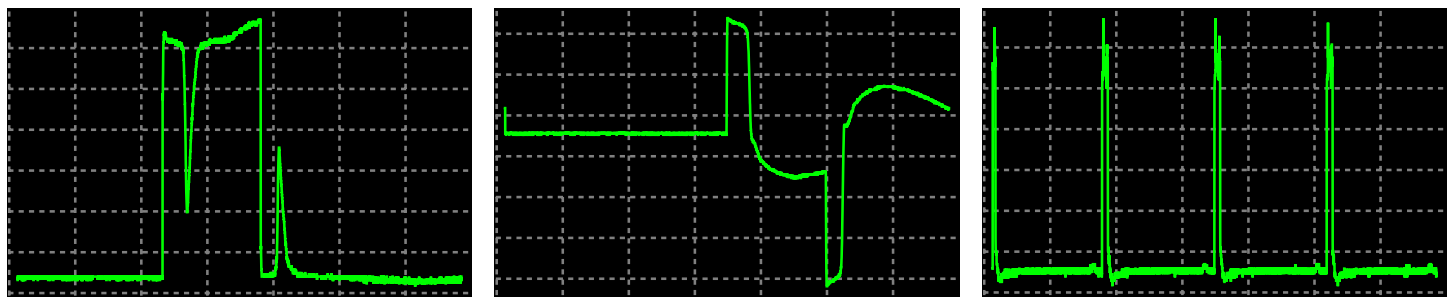
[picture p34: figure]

During startup (before the coil starts oscillating, e.g. when the primary is not connected), the waveform at pin 6 and 7 of IC3 and IC4 should look like this.

Across the gate and emitter (pins 1 and 3) of either IGBT the waveform should look like this.

This waveform is on many pins, with an amplitude of 5V. It should be on pins 1, 4, and 13 of the 74HCT14, pin 3 of both UCC chips, and pin 3 of the 74HCT74, as well as the output pin (center pin) of the optical receiver.

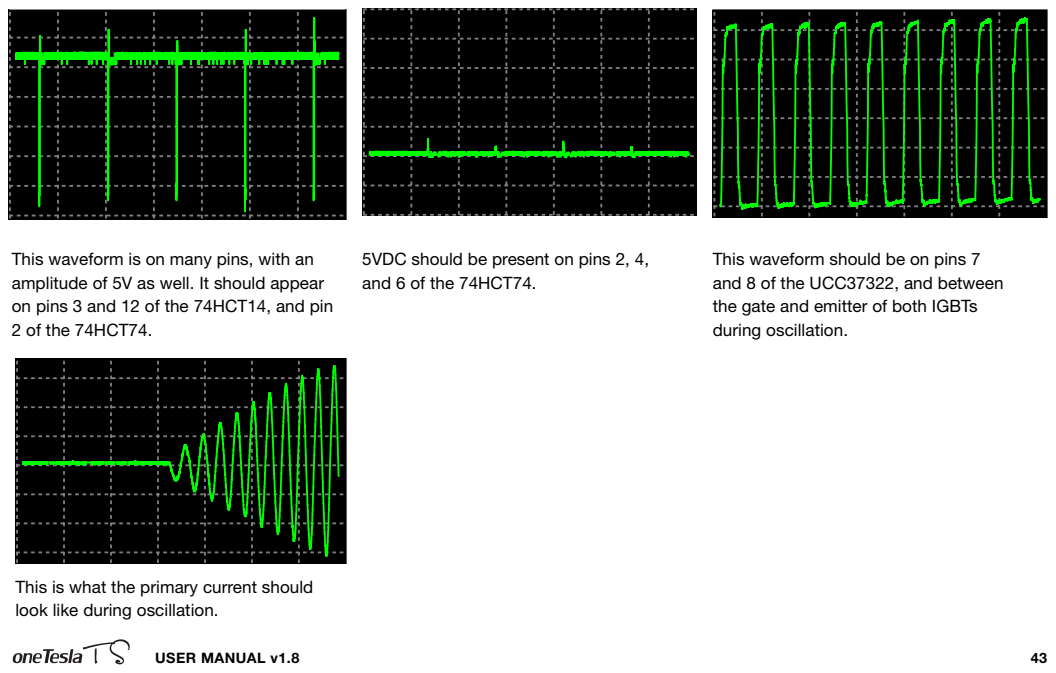
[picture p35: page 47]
User Manual v1.8

This waveform is on many pins, with an
amplitude of 5V as well. It should appear
on pins 3 and 12 of the 74HCT14, and pin
2 of the 74HCT74.

5VDC should be present on pins 2, 4,
and 6 of the 74HCT74.

This waveform should be on pins 7
and 8 of the UCC37322, and between
the gate and emitter of both IGBTs
during oscillation.

This is what the primary current should
look like during oscillation.

Appendix D: Further Resources

## Schematics and Board Images

Download schematics and board layout images at onetesla.com/downloads.

## Part Data Sheets

Don’t be afraid to look at the documentation of individual parts if you want to understand more about how they work. Read the descriptions in the data sheets and take a look at the part pinouts, especially if you are doing detailed troubleshooting on your driver.
Hex Schmitt-Trigger Inverter 7414: http://www.ti.com/lit/ds/symlink/sn5414.pdf
7474 Dual D-Type Flip Flop: http://www.ti.com/general/docs/lit/getliterature.tsp?genericPartNumber=sn54s74&fileType=pdf (http://www.ti.com/general/docs/lit/getliterature.tsp?genericPartNumber=sn54s74&fileType=pdf)
FGA60N65SMD: https://www.fairchildsemi.com/datasheets/FG/FGA60N65SMD.pdf

## oneTesla Resources

As you’ve probably already noticed, replacement parts are available on our website onetesla.com, and help is available at onetesla.com/forum.

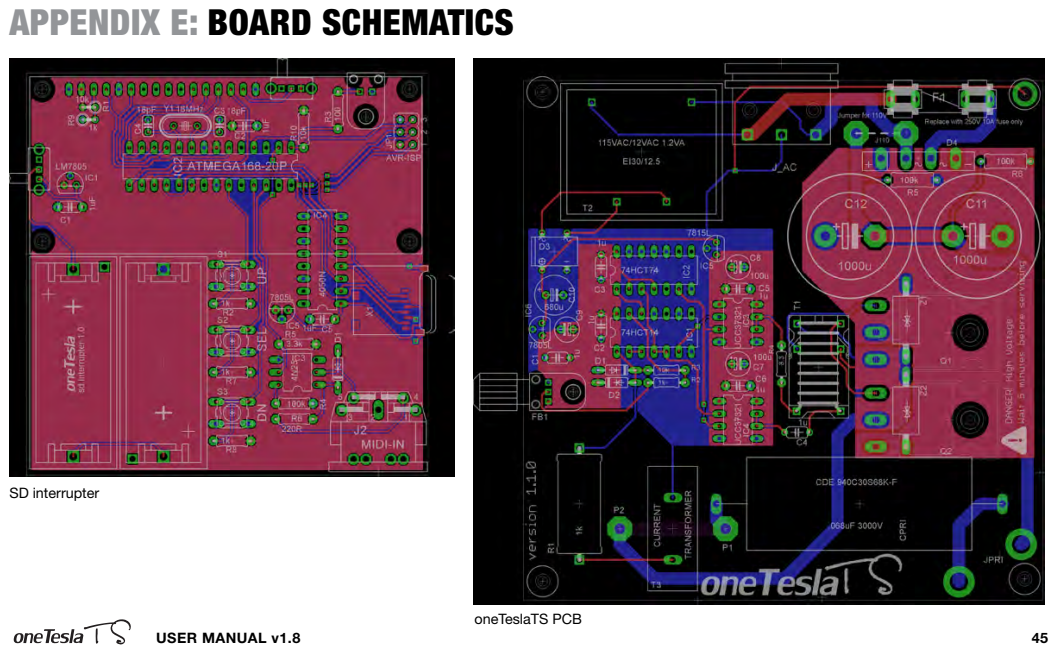
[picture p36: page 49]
User Manual v1.8; oneTeslaTS PCB; SD interrupter

Appendix E: Board schematics

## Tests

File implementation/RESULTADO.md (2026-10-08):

# Implementação da revisão DRSSTC — parcial, não fabricar

> Histórico anterior à ampliação autorizada. Estado atual: [expansion/RESULTADO.md](expansion/RESULTADO.md). Os bloqueios de tamanho, colisão C11/C12 e passo de R1 abaixo foram tratados na nova etapa.

Branch local: **fix/cad-review-20261007**. Base preservada: **60c237c** (projeto original f4da80c + auditoria). Sem push. A interrupção do provedor deixou uma etapa de roteamento não validada; ela foi recuperada, corrigida e verificada. O checkpoint interrompido fica em checkpoint/interrupted.kicad_pcb, exclusivamente histórico: NÃO usar para fabricação.

## Alterações efetivamente aplicadas

1. **Esquema:** revisão por referência incorporada nos campos Footprint_Status; referências dos seis modelos personalizados corrigidas. Nenhuma topologia, tensão nominal, valor elétrico, fase do GDT ou função lógica alterada. Não foram adicionados power flags para maquiar o ERC.
2. **HFBR-2521ETZ:** substituída geometria IFD95 improvisada por geometria KiCad HFBR-252x, confrontada com Broadcom AV02-3283EN pp4/11. Passo 2,54 mm, pads1–4 nas posições reais, retenção6 do modelo genérico renomeada8; pads5/8 PTH com nets NC individuais, sem conexão a GND. Furos1,4/pads são escolha do modelo nativo, não tolerância de fabricação certificada. Receptor reposicionado em (34;76), 90°, e redes OUT/+5V/GND reroteadas. Removidos antigos stubs e ajustada a zona +5V da área desocupada. Nenhum novo via.
3. **Corpos/polaridades:** C8/C9/C10/C11/C12/C13, R1/R5/R6, Z1/Z2 usam seis modelos personalizados com o corpo recentrado em relação aos pads reais. Pad1 dos eletrolíticos retangular; nomes indicam o passo real e a pendência. Não reduzimos o diâmetro dos capacitores para esconder a colisão. Modelos 3D antigos incompatíveis foram retirados desses modelos novos, não substituídos por peças inventadas. Valores e referências de montagem dos capacitores foram reposicionados para não sugerir o valor do vizinho.
4. **Entrada AC:** trilha AC_L mantida em2,54 mm e desviada do NPTH de J1. Trecho superior PE deslocado para y0,8 sem reduzir largura. Derivação auxiliar AC_L_FUSED de0,5 mm transferida para B.Cu entre pads PTH existentes de F1/PS1; sem novos vias. Eliminada a invasão de cobre no furo. A menor separação rede–PE continua inadequadamente especificada: isto NÃO aprova isolamento nem bonding.
5. **Paridade:** DNP de Z1/Z2 sincronizado, campos Footprint_Status/Assembly_Notes/Datasheet/Description transferidos ao PCB. Validador ajustado para exigir também os pads5/8 reais do HFBR, em vez de dispensá-los.
6. Contorno da placa, pontos de montagem, redes dos pads elétricos preexistentes e topologia preservados. Eagle e snapshots históricos não editados.

## Verificação nativa final — KiCad10.0.6

| Verificação | Antes | Depois |
|---|---:|---:|
| Violações DRC reportadas |529|509|
| Questões de paridade |56|11|
| Conexões pendentes |0|0|
| Erros + avisos (DRC/paridade) |87 + 498|69 + 451|
| Hole clearance |2|0|
| Curtos / trilhas cruzadas / clearance de cobre |0 / 0 / 0|0 / 0 / 0|
| Courtyards sobrepostos |45|39|
| ERC principal |2|2|

As duas ocorrências ERC continuam PS1.1/2 power_pin_not_driven. A contagem é a saída reportada pelo KiCad, não métrica de segurança nem garantia de que todos os problemas físicos foram resolvidos. Não foram relaxadas regras, adicionadas exclusões DRC/ERC nem suprimidos courtyards.

- Netlist nativa final **idêntica** à base, por grupos de referência/pino.
- Todos os pads elétricos anteriores preservam suas nets; apenas retenções NC5/8 foram acrescentadas.
- Validador passou nas20 redes de referência,7 ligações diretas e41 componentes, incluindo todos os pinos dos CIs.
- Contorno Edge.Cuts comparado estruturalmente e preservado.
- Refill salvo, DRC/paridade executados novamente; SVGs nativos de topo/fundo/montagem convertidos e inspecionados após os últimos ajustes.
- QA paralelo foi interrompido pelo mesmo limite do provedor, sem parecer final. Sua inspeção parcial confirmou topologia preservada; NÃO é apresentado como aprovação independente final.

Evidências: evidence/drc-final.json, final-erc.json, final-oneTesla.net, final-validation.txt, invariants.txt, top/bottom/assembly.svg e .png, before-after.png. A comparação visual mantém a mesma placa e mostra alterações reais; não é simulação 3D.

## Cobertura e limites por peça

cobertura-final.csv tem **48/48 instâncias do PCB**, com pads/nets atuais e estado individual. A auditoria anterior preservada em ../review contém135/135 modelos originais inventariados e checados geometricamente,51/51 elementos Eagle e todos os esquemas. Foram acrescentados seis modelos personalizados, totalizando141 arquivos de biblioteca. Isso NÃO significa141 peças homologadas contra fabricante. As peças não identificadas continuam não identificadas; a revisão não inventa MPN.

## Decisões exatas que bloqueiam o restante do layout

1. **C11/C12:** selecionar fabricante/código completo, diâmetro/altura/passo, tensão e ripple. Corpos D30 ainda se sobrepõem3,965 mm e C11 ultrapassa o contorno mesmo recentrado. É necessário decidir entre peças adequadas menores ou rearranjo/ampliação autorizada da placa com dimensões do enclosure. Não alterar outline às cegas.
2. **R1:** peça axial de corpo25 mm não cabe horizontalmente entre furos22,86 mm. Modelo renomeado INCOMPATIBLE, não aprovado. Informar MPN/encapsulamento/montagem; só então definir pads/posição e dissipação.
3. **IEC, PS1 e PE:** código real de J1, dimensões do módulo BL aberto, montagem de J2 e chassis. J2 ainda tem cobre a0,2059 mm da borda, contra regra0,5; não deslocamos um furo de chassis sem desenho mecânico. Persistem conflitos PS1/J1/fixação. Entrada/PE exige arquitetura de proteção, não apenas mover trilhas.
4. **D4/F1/IC6/P1/P2/T1/T3:** códigos completos e desenhos. Ponte KBU selecionada sobre geometria GBU herdada; clipes não confirmados; TO92 depende fabricante/conformação; terminal chamado M6 usa furo2,2; magnetismos sem bobinagem/core/isolação mecânica confirmados. Nenhuma troca de topologia ou componente implícita.
5. **Potência e isolamento:** rede máxima e tolerância (110/127/220), corrente RMS/pico, frequência, duração/repetição dos pulsos, cobre/plating, ambiente/altitude/poluição/CTI/coating, norma e dissipador. Sem isso não fechar isolamento HV, loop de potência, vias e orçamento térmico. Gargalos DC_MID e loops de potência/gate do relatório original permanecem pendentes; não foram declarados dimensionados.
6. Depois dessas decisões: placement definitivo, reroteamento de potência, cleanup de serigrafia, solução dos39 overlaps de courtyard,22 diferenças de biblioteca e demais pendências. Cinco furos sem referência e JPRT1/2 continuam explicando as11 questões de paridade (4 duplicidades +7 extras); não foram escondidos com exclusões.

**Estado final: melhorias locais reais e verificadas, mas layout completo ainda não concluído e não liberado para fabricar/energizar.** O primeiro desbloqueio útil é confirmar os MPNs de C11/C12 e R1 e o envelope mecânico permitido; isso determina o placement, antes de polir trilhas e silk sobre corpos que ainda não cabem.

## Reversibilidade e reprodução

Os commits separam esquema e biblioteca; o commit final salva PCB/evidências. O histórico implementation/*stage*.py, pcb_refine.py e mains_local.py registra etapas intermediárias, NÃO é pipeline idempotente nem deve ser executado novamente sobre a placa final. Algumas etapas intermediárias falharam e seus DRCs ficam para transparência. Fonte de verdade desta entrega: arquivos CAD versionados no commit final + evidence/drc-final.json. O gerador legado scripts/pcb_patch_footprints.py recria os footprints errados e NÃO deve ser usado nesta revisão.

Para repetir sem gerar novamente o projeto: kicad-cli sch export netlist, sch erc, pcb drc --all-track-errors --schematic-parity --severity-all --refill-zones; ver comandos completos e ferramentas no relatório anterior. Não usar geradores build_* para validar.

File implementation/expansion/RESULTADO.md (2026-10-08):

# Ampliação autorizada — revisão geométrica implementada

Base: 028ef6e. Branch: fix/cad-review-20261007. Sem push. Esta entrega substitui os bloqueios de tamanho da placa, colisão C11/C12 e passo impossível de R1 do relatório anterior, mas NÃO aprova fabricação ou energização.

## Mudanças

- Placa: **106,045 × 106,045 → 145 × 108,045 mm**. Coordenadas do contorno: x=0…145; y=-2…106,045. Crescimento de38,955 mm à direita e2 mm para cima; origem dos componentes preservada.
- **Todos os furos de montagem/chassis preservados**, incluindo NPTHs dos conectores, furos dos IGBTs e J2. Sem novos furos de suporte. O balanço mecânico da nova região à direita precisa ser conferido; não inventamos suporte ou enclosure.
- C12: (66,675;31,75) → **(125;25)**. C11: (92,71;31,75) → **(125;60)**. Diâmetro30, passo10,16 e polaridade preservados. Distância entre centros35 mm: **5 mm livres entre os corpos**, e5 mm do corpo à borda direita. MPN, altura, tolerâncias, ripple e vida útil continuam pendentes.
- R1: corpo25 ×6,4 mantido; passo22,86 → **30,48 mm**, com2,74 mm nominais de extensão de terminal por lado. Novo modelo **R_L25_P30.48_Provisional**, origem/posição mantidas. Pads ficaram em(11,43;101,6) e(11,43;71,12); ligações refeitas. Courtyard existente cobre ambos os pads. Esta escolha geométrica convencional não verifica dobra de terminal, temperatura ou MPN.
- R5: (79,375;20,32) → **(79,375;27,94)**. R6: (98,425;16,51) → **(98,425;27,94)**. Saíram da região ocupada pela ponte; corpos, pads e nets preservados, derivações DC_MID refeitas.
- Planos DC_PLUS/B.Cu e DC_MINUS/F.Cu ampliados até x142. Ponto médio reroteado: ligação do banco e retorno de C11 até JPRT1 por F.Cu, removendo o antigo corte longitudinal do plano positivo por B.Cu. Largura existente2,54 mm preservada; derivações dos resistores permanecem0,4064 mm. **7 vias antes e depois; nenhuma adicionada.**
- Campo Footprint_Status do esquema/PCB atualizado. Nenhum valor elétrico, componente selecionado, net, fase do GDT ou topologia funcional alterado.

- Serigrafia: hachuras sobre pads de seis eletrolíticos substituídas por sinal negativo explícito; contornos e sinais positivos preservados. Três modelos locais e instâncias sincronizados. Pictograma deslocado30 mm à direita e15 mm abaixo, sem apagar avisos. Ainda restam colisões de serigrafia, inclusive primitivas gráficas.

## Verificação final

KiCad10.0.6: refill salvo, DRC/paridade nativos, ERC, netlist e exportações executados sobre os arquivos editados. Conferidos topo, fundo e montagem após o último reposicionamento de R5/R6.

| Verificação | 028ef6e | Atual |
|---|---:|---:|
| DRC reportado |509|363|
| Paridade |11|11|
| Conexões pendentes |0|0|
| Curtos / clearance / trilhas cruzadas |0|0|
| Erros de furo / alívio térmico |0|0|
| Cobre próximo da borda |1|0|
| Courtyards sobrepostos |39|27|
| PTH dentro de courtyard |25|17|
| ERC |2|2|

A margem geométrica cobre–borda de J2 agora atende à regra existente porque o contorno cresceu; o furo não foi movido. Isso não verifica ligação PE, corrente de falha ou isolação de rede.

As duas ocorrências ERC continuam entradas AC de PS1 sem power_output. Netlist final idêntica à anterior por referência/pino; mapa pad–net idêntico; 48 instâncias preservadas. Nenhuma regra/exclusão foi relaxada. Contagens são ocorrências reportadas, não um índice de segurança.

Provas: **invariants.json**, **drc-final.json**, **erc-final.json**, **final.net**, **cobertura.csv** (48 instâncias), **top/bottom/assembly.svg e .png**, **before-after.png**. Arquivos drc-1/2 registram iterações, não são o estado final. expand_board.py é histórico de migração inicial, não gerador idempotente da versão final; tem guarda contra reaplicação.

## O que ainda falta — sem reutilizar o bloqueio de tamanho já removido

1. **Peças reais:** códigos/datasheets de C11/C12/R1, ponte D4, clipes F1, IEC J1, TO92 IC6, terminais e magnetismos. Acomodar um envelope não confirma o componente comprado. Não foram trocados os capacitores por menores.
2. **Mecânica:** módulo PS1, cabo óptico, dissipador, cabeças de parafusos e suportes do novo espaço à direita. Persistem interferências no conjunto PS1/J1/fixação e na região compacta de baixa tensão. Os27 overlaps não foram ignorados. Sua resolução final exige envelopes/montagem corretos; alguns ainda demandam trabalho de placement, não apenas informação externa.
3. **Potência/isolação:** tensão máxima de rede, corrente RMS/pico, frequência/pulsos, cobre/plating, norma, CTI/poluição/altitude/coating e condições térmicas. A ampliação muda a área e a indutância do loop de potência: não foi demonstrado que o novo trajeto é adequado para comutação. Dimensionar barramento, gate loops, snubber e térmica continua necessário; largura herdada não é corrente nominal certificada.
4. **Limpeza CAD restante:**22 diferenças entre footprints embarcados e biblioteca,7 questões de biblioteca,11 de paridade, serigrafia e outras interferências documentadas. Não alegamos que todas dependem de BOM; são trabalho remanescente da revisão completa. Esta etapa conclui a ampliação e as correções geométricas descritas, não o layout inteiro.

**Resultado: C11/C12 cabem sem colisão entre si e R1 deixou de ter geometria impossível. Layout ainda não liberado para fabricação/energização.**

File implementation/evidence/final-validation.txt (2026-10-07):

PASS: 20 reference nets and 7 direct connections.
PASS: all unused outputs explicitly NC; isolated domains remain separate.
PASS: 41 physical references with existing local footprints; symbol pins match every pad.
PASS: all 14/14/8/8 IC pins represented.
PASS: KiCad 10.0.6 ERC: only the 2 expected PS1 power_pin_not_driven notes.
Footprint dimensions marked CONFIRMAR/PROVISORIO still require physical verification.

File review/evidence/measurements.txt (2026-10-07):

/DC_MID length_mm 231.8037459019447 widths [0.4064, 2.54]
['start', '87.63', '31.75'] ['end', '74.295', '31.75'] ['width', '2.54'] ['layer', 'F.Cu']
['start', '74.295', '31.75'] ['end', '71.755', '31.75'] ['width', '2.54'] ['layer', 'F.Cu']
['start', '84', '97.045'] ['end', '94', '97.045'] ['width', '2.54'] ['layer', 'F.Cu']
['start', '102.87', '38.735'] ['end', '102.87', '92.71'] ['width', '2.54'] ['layer', 'B.Cu']
['start', '92.71', '36.83'] ['end', '87.63', '31.75'] ['width', '2.54'] ['layer', 'B.Cu']
['start', '19.685', '91.44'] ['end', '19.685', '100.545'] ['width', '2.54'] ['layer', 'B.Cu']
['start', '74.295', '20.32'] ['end', '67.945', '20.32'] ['width', '0.4064'] ['layer', 'B.Cu']
['start', '19.685', '100.545'] ['end', '84', '100.545'] ['width', '2.54'] ['layer', 'B.Cu']
['start', '67.945', '10.795'] ['end', '67.945', '12.065'] ['width', '2.54'] ['layer', 'B.Cu']
['start', '67.945', '12.065'] ['end', '67.945', '20.32'] ['width', '2.54'] ['layer', 'B.Cu']
['start', '87.63', '26.67'] ['end', '87.63', '31.75'] ['width', '0.4064'] ['layer', 'B.Cu']
['start', '67.945', '27.94'] ['end', '71.755', '31.75'] ['width', '2.54'] ['layer', 'B.Cu']
['start', '67.945', '20.32'] ['end', '67.945', '27.94'] ['width', '2.54'] ['layer', 'B.Cu']
['start', '102.87', '92.71'] ['end', '102.87', '93.345'] ['width', '2.54'] ['layer', 'B.Cu']
['start', '100.965', '36.83'] ['end', '92.71', '36.83'] ['width', '2.54'] ['layer', 'B.Cu']
['start', '102.87', '93.345'] ['end', '101.6', '94.615'] ['width', '2.54'] ['layer', 'B.Cu']
['start', '94', '97.045'] ['end', '101.6', '94.615'] ['width', '2.54'] ['layer', 'B.Cu']
['start', '93.345', '20.955'] ['end', '87.63', '26.67'] ['width', '0.4064'] ['layer', 'B.Cu']
['start', '84', '100.545'] ['end', '84', '97.045'] ['width', '2.54'] ['layer', 'B.Cu']
['start', '93.345', '16.51'] ['end', '93.345', '20.955'] ['width', '0.4064'] ['layer', 'B.Cu']
['start', '100.965', '36.83'] ['end', '102.87', '38.735'] ['width', '2.54'] ['layer', 'B.Cu']
/DC_MINUS length_mm 5.742076836320742 widths [0.4064]
['start', '64.77', '56.515'] ['end', '66.675', '58.42'] ['width', '0.4064'] ['layer', 'F.Cu']
['start', '64.77', '54.737'] ['end', '64.77', '56.515'] ['width', '0.4064'] ['layer', 'F.Cu']
['start', '66.675', '58.42'] ['end', '67.945', '58.42'] ['width', '0.4064'] ['layer', 'F.Cu']
/GATE_H length_mm 26.183469039905642 widths [0.4064]
['start', '55.88', '54.61'] ['end', '54.61', '53.34'] ['width', '0.4064'] ['layer', 'B.Cu']
['start', '66.675', '47.625'] ['end', '54.61', '47.625'] ['width', '0.4064'] ['layer', 'B.Cu']
['start', '54.61', '47.625'] ['end', '53.975', '48.26'] ['width', '0.4064'] ['layer', 'B.Cu']
['start', '54.61', '53.34'] ['end', '53.975', '52.705'] ['width', '0.4064'] ['layer', 'B.Cu']
['start', '71.9455', '45.974'] ['end', '68.326', '45.974'] ['width', '0.4064'] ['layer', 'B.Cu']
['start', '53.975', '52.705'] ['end', '53.975', '48.26'] ['width', '0.4064'] ['layer', 'B.Cu']
['start', '68.326', '45.974'] ['end', '66.675', '47.625'] ['width', '0.4064'] ['layer', 'B.Cu']
['start', '55.88', '54.737'] ['end', '55.88', '54.61'] ['width', '0.4064'] ['layer', 'B.Cu']
/GATE_L length_mm 21.660335631383614 widths [0.4064]
['start', '71.9455', '63.754'] ['end', '67.564', '63.754'] ['width', '0.4064'] ['layer', 'F.Cu']
['start', '67.564', '63.754'] ['end', '67.31', '63.5'] ['width', '0.4064'] ['layer', 'F.Cu']
['start', '62.865', '55.88'] ['end', '66.04', '59.055'] ['width', '0.4064'] ['layer', 'F.Cu']
['start', '64.008', '49.657'] ['end', '62.865', '50.8'] ['width', '0.4064'] ['layer', 'F.Cu']
['start', '62.865', '50.8'] ['end', '62.865', '55.88'] ['width', '0.4064'] ['layer', 'F.Cu']
['start', '64.77', '49.657'] ['end', '64.008', '49.657'] ['width', '0.4064'] ['layer', 'F.Cu']
['start', '66.04', '62.23'] ['end', '67.31', '63.5'] ['width', '0.4064'] ['layer', 'F.Cu']
['start', '66.04', '59.055'] ['end', '66.04', '62.23'] ['width', '0.4064'] ['layer', 'F.Cu']
/PE length_mm 88.58220617765619 widths [0.5, 0.6]
['start', '42', '1.85'] ['end', '93', '1.85'] ['width', '0.5'] ['layer', 'F.Cu']
['start', '49', '16'] ['end', '42', '16'] ['width', '0.6'] ['layer', 'F.Cu']
['start', '102.36', '2'] ['end', '102.362', '2.756'] ['width', '0.5'] ['layer', 'F.Cu']
['start', '52.705', '11.071'] ['end', '49', '16'] ['width', '0.6'] ['layer', 'F.Cu']
['start', '42', '16'] ['end', '42', '1.85'] ['width', '0.6'] ['layer', 'F.Cu']
['start', '93', '1.85'] ['end', '93', '2'] ['width', '0.5'] ['layer', 'F.Cu']
['start', '99.5', '2'] ['end', '102.36', '2'] ['width', '0.5'] ['layer', 'F.Cu']
['start', '93', '2'] ['end', '99.5', '2'] ['width', '0.5'] ['layer', 'B.Cu']
/SW_NODE length_mm 64.97172783496849 widths [0.4064, 2.54]
['start', '39.37', '86.36'] ['end', '64.14', '86.36'] ['width', '2.54'] ['layer', 'B.Cu']
['start', '67.31', '56.515'] ['end', '68.58', '56.515'] ['width', '0.4064'] ['layer', 'B.Cu']
['start', '64.77', '71.755'] ['end', '64.135', '72.39'] ['width', '2.54'] ['layer', 'B.Cu']
['start', '66.04', '53.34'] ['end', '66.675', '53.975'] ['width', '0.4064'] ['layer', 'B.Cu']
['start', '57.658', '51.435'] ['end', '55.88', '49.657'] ['width', '0.4064'] ['layer', 'B.Cu']
['start', '67.31', '69.215'] ['end', '65.405', '71.12'] ['width', '2.54'] ['layer', 'B.Cu']
['start', '71.9455', '56.896'] ['end', '71.501', '56.896'] ['width', '0.4064'] ['layer', 'B.Cu']
['start', '57.658', '51.435'] ['end', '64.135', '51.435'] ['width', '0.4064'] ['layer', 'B.Cu']
['start', '65.405', '71.12'] ['end', '64.77', '71.755'] ['width', '2.54'] ['layer', 'B.Cu']
['start', '66.675', '53.975'] ['end', '66.675', '55.88'] ['width', '0.4064'] ['layer', 'B.Cu']
['start', '64.14', '86.36'] ['end', '64.14', '72.385'] ['width', '2.54'] ['layer', 'B.Cu']
['start', '71.9455', '69.215'] ['end', '67.31', '69.215'] ['width', '2.54'] ['layer', 'B.Cu']
['start', '66.675', '55.88'] ['end', '67.31', '56.515'] ['width', '0.4064'] ['layer', 'B.Cu']
['start', '64.135', '51.435'] ['end', '66.04', '53.34'] ['width', '0.4064'] ['layer', 'B.Cu']
Net-(CPR1-Pad2) length_mm 75.63117928474841 widths [2.54]
['start', '41.275', '94.045'] ['end', '88.9', '94.045'] ['width', '2.54'] ['layer', 'B.Cu']
['start', '88.9', '94.045'] ['end', '88.9', '90.805'] ['width', '2.54'] ['layer', 'B.Cu']
['start', '93.345', '86.36'] ['end', '97.79', '86.36'] ['width', '2.54'] ['layer', 'B.Cu']
['start', '41.275', '91.44'] ['end', '41.275', '94.045'] ['width', '2.54'] ['layer', 'B.Cu']
['start', '88.9', '90.805'] ['end', '88.9', '102.235'] ['width', '2.54'] ['layer', 'B.Cu']
['start', '88.9', '90.805'] ['end', '93.345', '86.36'] ['width', '2.54'] ['layer', 'B.Cu']
via ['net', '/DC_MID'] ['at', '94', '97.045'] ['size', '1.3'] ['drill', '0.6']
via ['net', '/DC_MID'] ['at', '84', '97.045'] ['size', '1.3'] ['drill', '0.6']
via ['net', '/DRIVE_ENABLE'] ['at', '36.83', '69.215'] ['size', '1.5'] ['drill', '0.6']
via ['net', '/DRIVE_ENABLE'] ['at', '36.83', '66.04'] ['size', '1.5'] ['drill', '0.6']
via ['net', '/PE'] ['at', '99.5', '2'] ['size', '1.3'] ['drill', '0.6']
via ['net', '/PE'] ['at', '93', '2'] ['size', '1.3'] ['drill', '0.6']
via ['net', 'Net-(IC3-IN)'] ['at', '35.56', '50.165'] ['size', '1.5'] ['drill', '0.6']
zone None ['net', '+15V'] ['connect_pads', ['clearance', '0.4']] ['fill', 'yes', ['thermal_gap', '0.4'], ['thermal_bridge_width', '0.7'], ['island_removal_mode', '0']]
zone None ['net', '+5V'] ['connect_pads', ['clearance', '0.4']] ['fill', 'yes', ['thermal_gap', '0.4'], ['thermal_bridge_width', '0.7'], ['island_removal_mode', '0']]
zone None ['net', '/DC_MINUS'] ['connect_pads', 'yes', ['clearance', '0.6096']] ['fill', 'yes', ['thermal_gap', '0.4'], ['thermal_bridge_width', '0.7'], ['island_removal_mode', '0']]
zone None ['net', '/DC_PLUS'] ['connect_pads', 'yes', ['clearance', '0.6096']] ['fill', 'yes', ['thermal_gap', '0.4'], ['thermal_bridge_width', '0.7'], ['island_removal_mode', '0']]
zone None ['net', 'GND'] ['connect_pads', ['clearance', '0.4']] ['fill', 'yes', ['thermal_gap', '0.4'], ['thermal_bridge_width', '0.7'], ['island_removal_mode', '0']]
zone None ['net', '/SW_NODE'] ['connect_pads', 'yes', ['clearance', '0.6096']] ['fill', 'yes', ['thermal_gap', '0.4'], ['thermal_bridge_width', '0.7'], ['island_removal_mode', '0']]
EAGLE {'name': 'C11', 'library': 'rcl', 'package': 'EB25D', 'value': '1000u', 'x': '92.71', 'y': '74.295', 'smashed': 'yes'}
EAGLE {'name': 'C12', 'library': 'rcl', 'package': 'EB25D', 'value': '1000u', 'x': '66.675', 'y': '74.295', 'smashed': 'yes'}
EAGLE {'name': 'R1', 'library': 'onecoil', 'package': '0922/22', 'value': '1k', 'x': '11.43', 'y': '19.685', 'rot': 'R90'}

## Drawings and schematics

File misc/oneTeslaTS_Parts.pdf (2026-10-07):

## Main Parts Box

## SD Interrupter

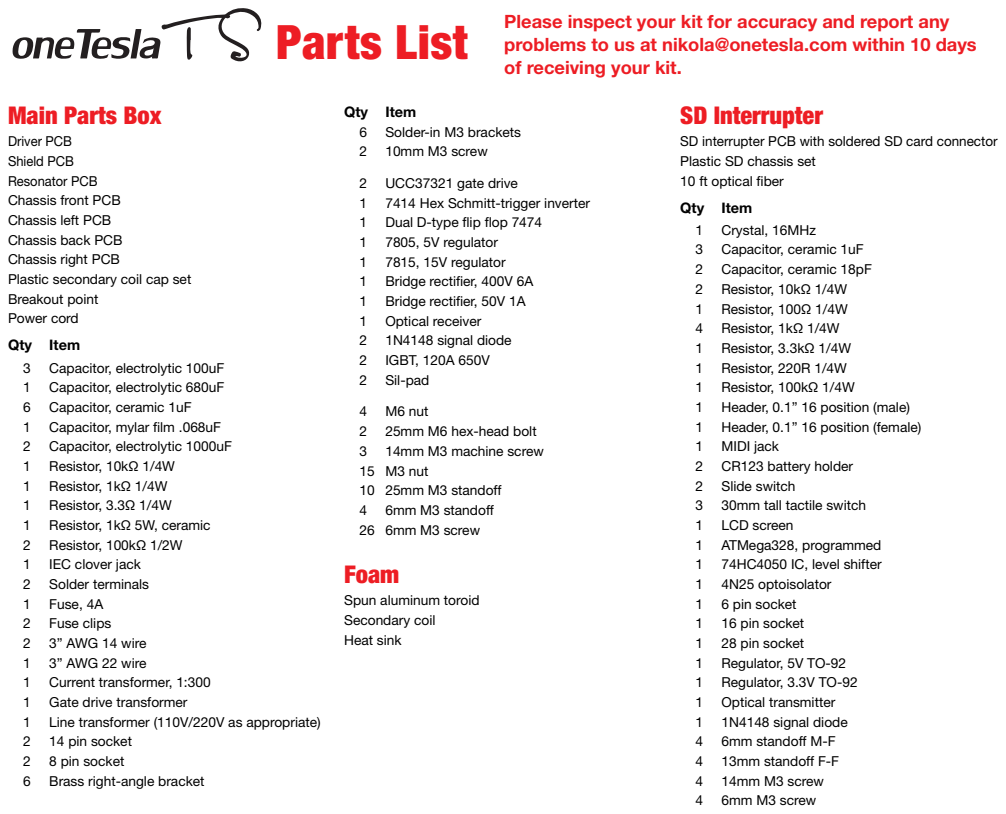
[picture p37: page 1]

Parts List Please inspect your kit for accuracy and report any

problems to us at nikola@onetesla.com within 10 days
of receiving your kit.

Qty Item
6 Solder-in M3 brackets
2 10mm M3 screw
2 UCC37321 gate drive
1 7414 Hex Schmitt-trigger inverter
1 Dual D-type flip flop 7474
1 7805, 5V regulator
1 7815, 15V regulator
1 Bridge rectifier, 400V 6A
1 Bridge rectifier, 50V 1A
1 Optical receiver
2 1N4148 signal diode
2 IGBT, 120A 650V
2 Sil-pad
4 M6 nut
2 25mm M6 hex-head bolt
3 14mm M3 machine screw
15 M3 nut
10 25mm M3 standoff
4 6mm M3 standoff
26 6mm M3 screw
Foam
Spun aluminum toroid
Secondary coil
Heat sink

Driver PCB
Shield PCB
Resonator PCB
Chassis front PCB
Chassis left PCB
Chassis back PCB
Chassis right PCB
Plastic secondary coil cap set
Breakout point
Power cord
3 Capacitor, electrolytic 100uF
1 Capacitor, electrolytic 680uF
6 Capacitor, ceramic 1uF
1 Capacitor, mylar film .068uF
2 Capacitor, electrolytic 1000uF
1 Resistor, 10kΩ 1/4W
1 Resistor, 1kΩ 1/4W
1 Resistor, 3.3Ω 1/4W
1 Resistor, 1kΩ 5W, ceramic
2 Resistor, 100kΩ 1/2W
1 IEC clover jack
2 Solder terminals
1 Fuse, 4A
2 Fuse clips
2 3” AWG 14 wire
1 3” AWG 22 wire
1 Current transformer, 1:300
1 Gate drive transformer
1 Line transformer (110V/220V as appropriate)
2 14 pin socket
2 8 pin socket
6 Brass right-angle bracket

SD interrupter PCB with soldered SD card connector
Plastic SD chassis set
10 ft optical fiber
1 Crystal, 16MHz
3 Capacitor, ceramic 1uF
2 Capacitor, ceramic 18pF
2 Resistor, 10kΩ 1/4W
1 Resistor, 100Ω 1/4W
4 Resistor, 1kΩ 1/4W
1 Resistor, 3.3kΩ 1/4W
1 Resistor, 220R 1/4W
1 Resistor, 100kΩ 1/4W
1 Header, 0.1” 16 position (male)
1 Header, 0.1” 16 position (female)
1 MIDI jack
2 CR123 battery holder
2 Slide switch
3 30mm tall tactile switch
1 LCD screen
1 ATMega328, programmed
1 74HC4050 IC, level shifter
1 4N25 optoisolator
1 6 pin socket
1 16 pin socket
1 28 pin socket
1 Regulator, 5V TO-92
1 Regulator, 3.3V TO-92
1 Optical transmitter
1 1N4148 signal diode
4 6mm standoff M-F
4 13mm standoff F-F
4 14mm M3 screw
4 6mm M3 screw

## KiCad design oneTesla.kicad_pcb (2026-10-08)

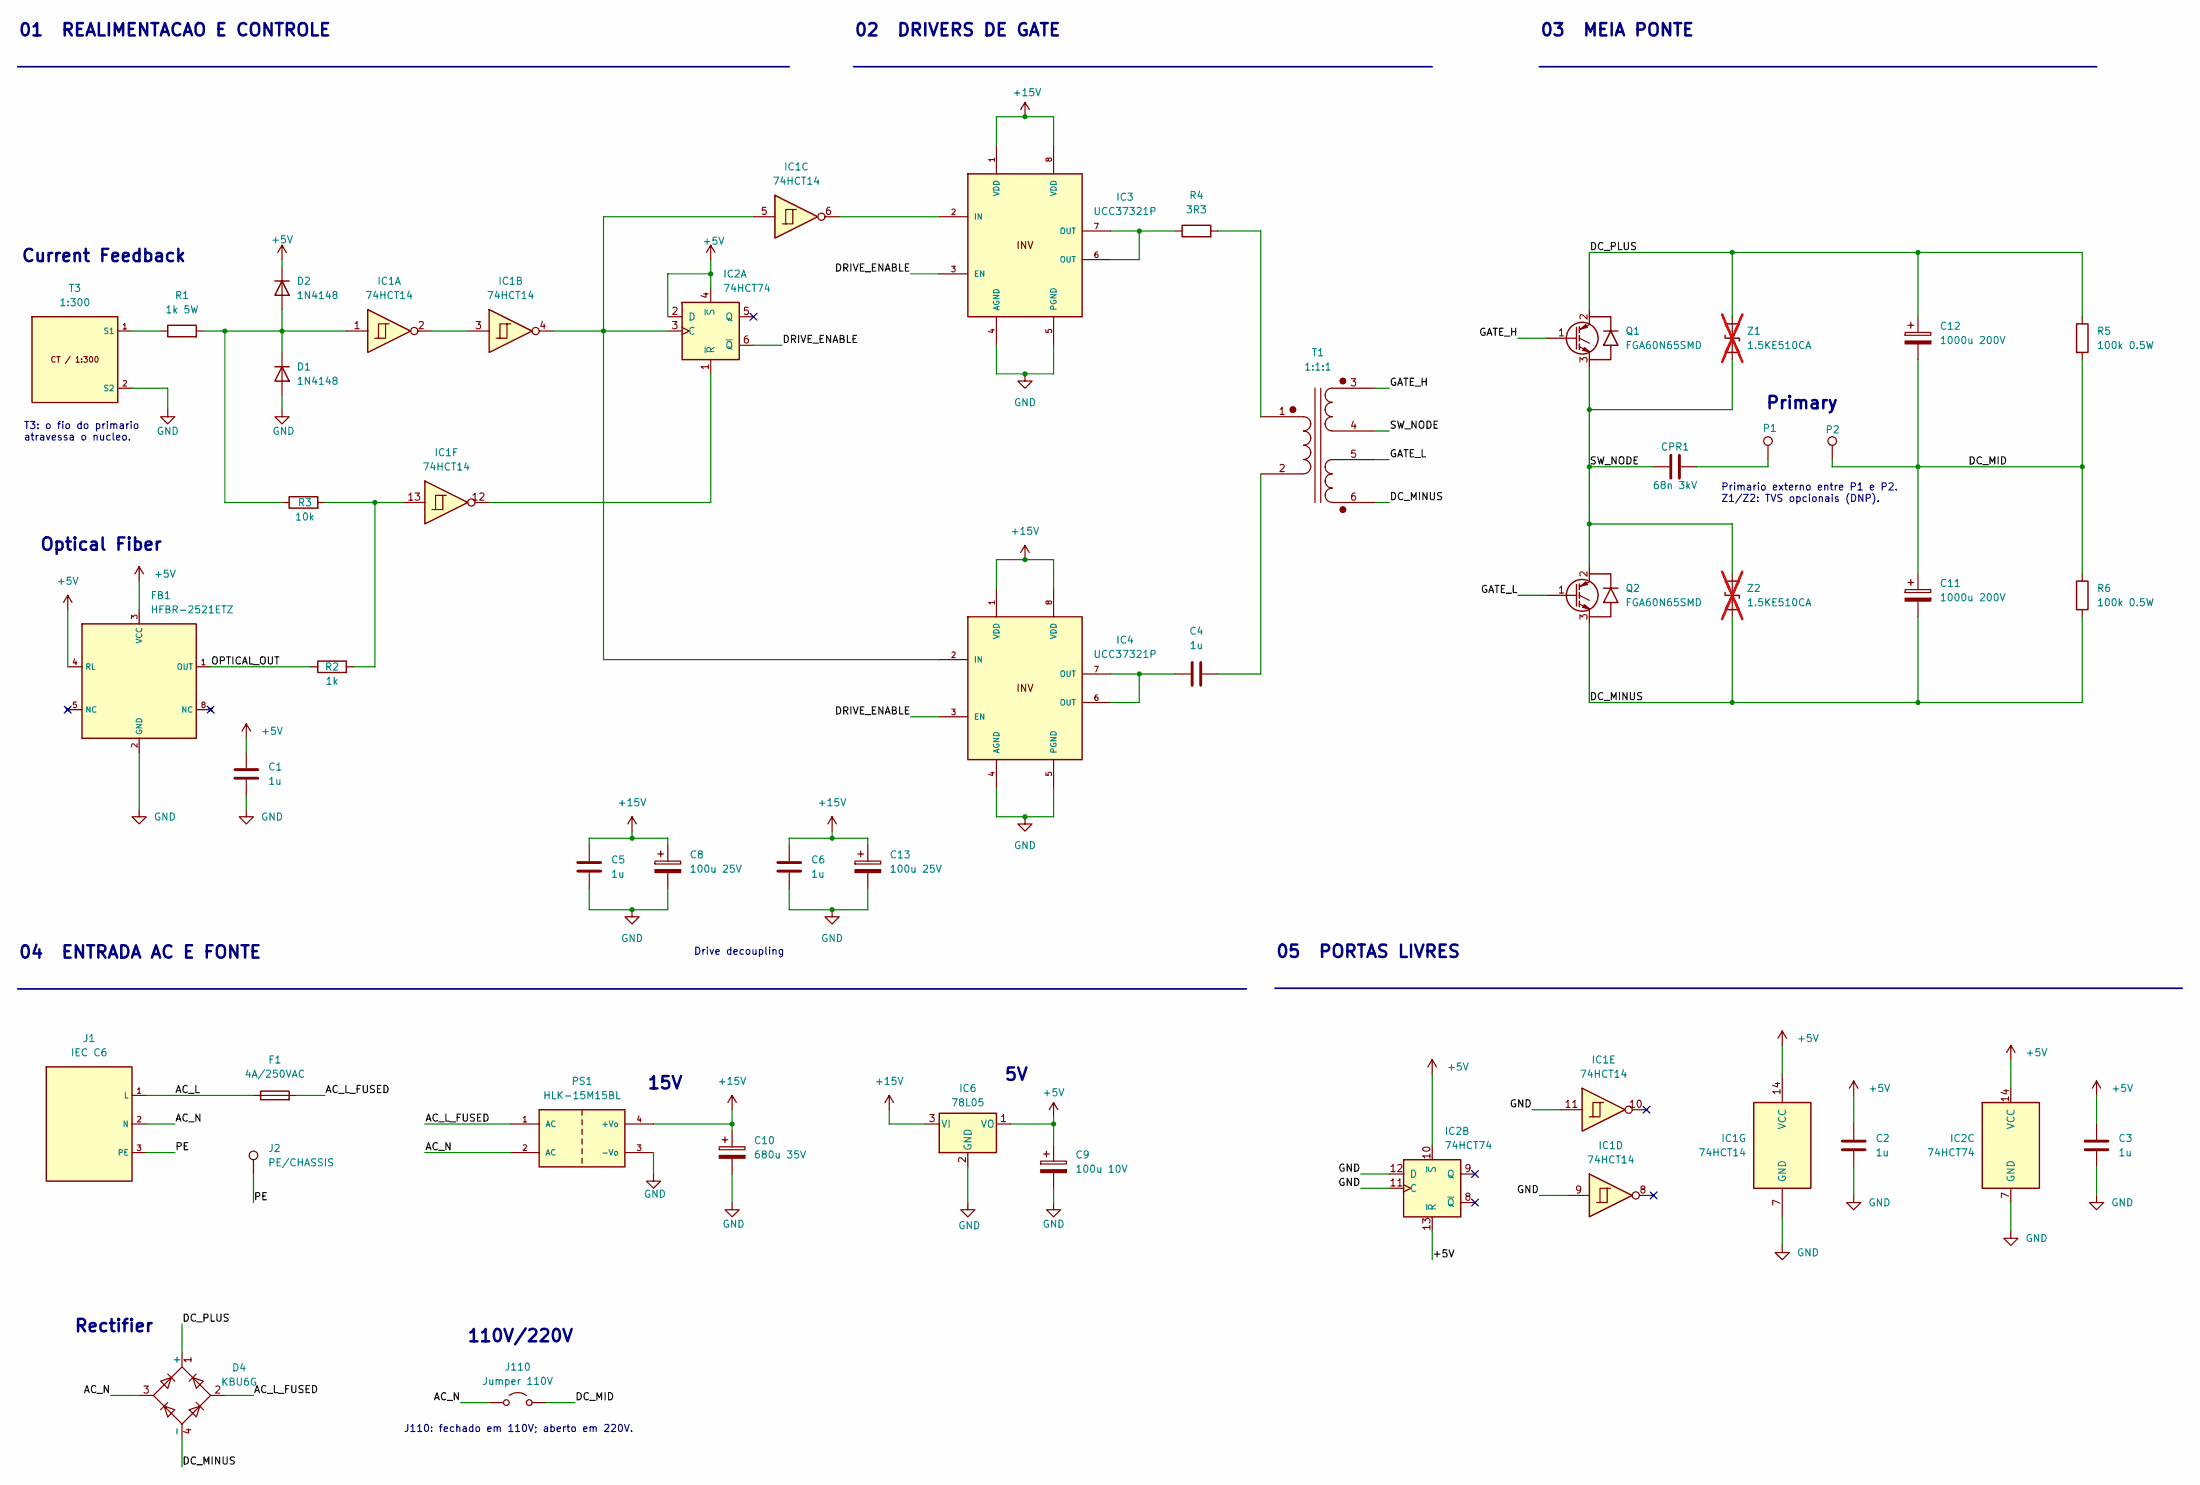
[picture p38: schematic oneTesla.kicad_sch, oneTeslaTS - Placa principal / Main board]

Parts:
C1, C2, C3, C4, C5, C6: 1u; C_Disc_D7.5mm_W2.5mm_P5.00mm
C8, C13: 100u 25V; CP_D8_P2.54_ReviewPending
C9: 100u 10V; CP_D8_P2.54_ReviewPending
C10: 680u 35V; CP_D12.5_P3.556_ReviewPending
C11, C12: 1000u 200V; CP_D30_P10.16_ReviewPending
CPR1: 68n 3kV; CDE_940C30S68K_F_CONFIRMAR
D1, D2: 1N4148; D_DO-35_SOD27_P7.62mm_Horizontal
D4: KBU6G; Diode_Bridge_Vishay_KBU
F1: 4A/250VAC; Fuseholder_Clip-5x20mm_Littelfuse_111_Inline_P20.00x5.00mm_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
FB1: HFBR-2521ETZ
IC1: 74HCT14; DIP-14_W7.62mm_Socket_LongPads
IC2: 74HCT74; DIP-14_W7.62mm_Socket_LongPads
IC3, IC4: UCC37321P; DIP-8_W7.62mm_Socket_LongPads
IC6: 78L05; TO-92_Inline
J1: IEC C6; IEC_C6_CONFIRMAR
J2: PE/CHASSIS; Chassis_PE_M3
J110: Jumper 110V; J110_WireLink_P10.16mm
P1: PRIMARIO A; Primary_Terminal_M6_CONFIRMAR
P2: PRIMARIO B; Primary_Terminal_M6_CONFIRMAR
PS1: HLK-15M15BL
Q1, Q2: FGA60N65SMD; Q_TO3P_ImportedPads_ReviewPending
R1: 1k 5W; R_L25_P30.48_Provisional
R2: 1k; R_Axial_DIN0207_L6.3mm_D2.5mm_P7.62mm_Horizontal
R3: 10k; R_Axial_DIN0207_L6.3mm_D2.5mm_P7.62mm_Horizontal
R4: 3R3; R_Axial_DIN0207_L6.3mm_D2.5mm_P7.62mm_Horizontal
R5, R6: 100k 0.5W; R_L9_P10.16_ReviewPending
T1: 1:1:1; GDT_6Pin_CONFIRMAR
T3: 1:300; CT_1_300_P12.70mm_CONFIRMAR
Z1, Z2: 1.5KE510CA; D_DO201AD_P14.732_ReviewPending; not fitted

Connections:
+5V: C1.1, C2.1, C3.1, C9.1, D2.1 (K), FB1.3 (VCC), FB1.4 (RL), IC1.14 (VCC), IC2.2 (D), IC2.4 (~S), IC2.10 (~S), IC2.13 (~R), IC2.14 (VCC), IC6.1 (VO)
+15V: C5.1, C6.1, C8.1, C10.1, C13.1, IC3.1 (VDD), IC3.8 (VDD), IC4.1 (VDD), IC4.8 (VDD), IC6.3 (VI), PS1.4 (+Vo)
/AC_L: F1.1, J1.1 (L)
/AC_L_FUSED: D4.2, F1.2, PS1.1 (AC)
/AC_N: D4.3, J1.2 (N), J110.1 (A), PS1.2 (AC)
/DC_MID: C11.1, C12.2, J110.2 (B), P2.1, R5.2, R6.1; also elsewhere on the board
/DC_MINUS: C11.2, D4.4 (-), Q2.3 (E), R6.2, T1.6 (SD), Z2.2 (A2)
/DC_PLUS: C12.1, D4.1 (+), Q1.2 (C), R5.1, Z1.1 (A1)
/DRIVE_ENABLE: IC2.6 (~Q), IC3.3 (EN), IC4.3 (EN)
/GATE_H: Q1.1 (G), T1.3 (SA)
/GATE_L: Q2.1 (G), T1.5 (SC)
/OPTICAL_OUT: FB1.1 (OUT), R2.1
/PE: J1.3 (PE), J2.1
/SW_NODE: CPR1.1, Q1.3 (E), Q2.2 (C), T1.4 (SB), Z1.2 (A2), Z2.1 (A1)
GND: C1.2, C2.2, C3.2, C5.2, C6.2, C8.2, C9.2, C10.2, C13.2, D1.2 (A), FB1.2 (GND), IC1.7 (GND), IC1.9, IC1.11, IC2.7 (GND), IC2.11 (C), IC2.12 (D), IC3.4 (AGND), IC3.5 (PGND), IC4.4 (AGND), IC4.5 (PGND), IC6.2 (GND), PS1.3 (-Vo), T3.2 (S2)
unnamed: C4.1, IC4.6 (OUT), IC4.7 (OUT)
unnamed 16: CPR1.2, P1.1; also elsewhere on the board
unnamed: D1.1 (K), D2.2 (A), IC1.1, R1.2, R3.1
unnamed: IC1.2, IC1.3
unnamed: IC1.13, R2.2, R3.2
unnamed: IC1.4, IC1.5, IC2.3 (C), IC4.2 (IN)
unnamed: IC1.12, IC2.1 (~R)
unnamed: IC1.6, IC3.2 (IN)
unnamed: IC3.6 (OUT), IC3.7 (OUT), R4.1
unnamed: R4.2, T1.1 (AA)
unnamed: C4.2, T1.2 (AB)
unnamed: R1.1, T3.1 (S1)

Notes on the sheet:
110V/220V
01 REALIMENTACAO E CONTROLE
03 MEIA PONTE
T3: o fio do primario atravessa o nucleo.
J110: fechado em 110V; aberto em 220V.
04 ENTRADA AC E FONTE
Drive decoupling
Current Feedback
Rectifier
Primario externo entre P1 e P2. Z1/Z2: TVS opcionais (DNP).
15V
02 DRIVERS DE GATE
05 PORTAS LIVRES
Optical Fiber
Primary

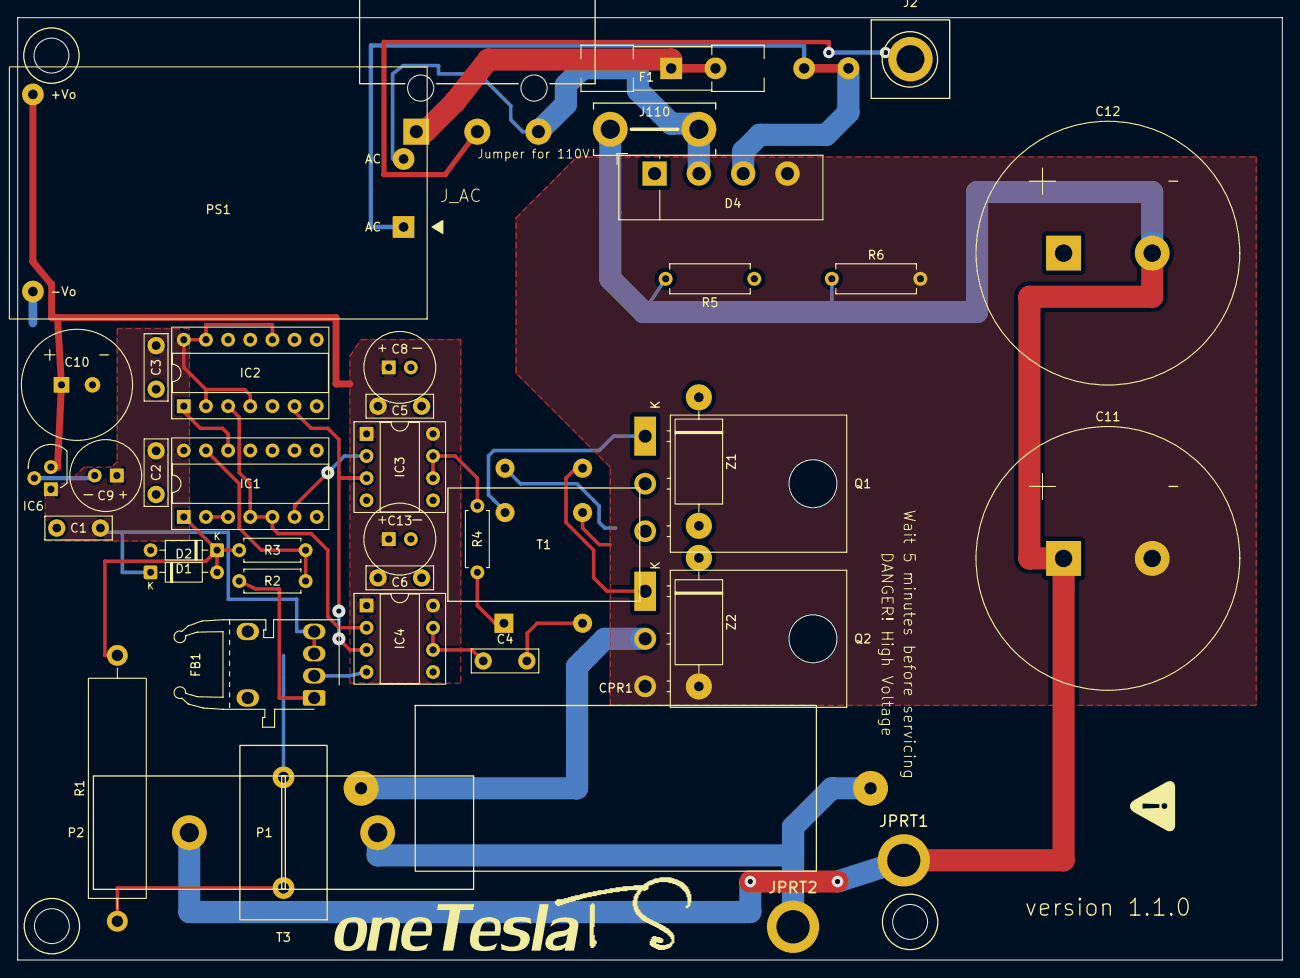
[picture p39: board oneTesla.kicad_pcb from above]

Board: 2 copper layers, 145.0 x 108.0 mm, 48 parts (0 on the bottom side), 27 nets.

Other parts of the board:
H1, H3, H5: MountingHole_D4.0
H2, H4: MountingHole_D5.5
JPRT1, JPRT2: Ring_D6_D3.81

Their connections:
/DC_MID: JPRT1.1; also elsewhere on the board
unnamed 16: JPRT2.1; also elsewhere on the board

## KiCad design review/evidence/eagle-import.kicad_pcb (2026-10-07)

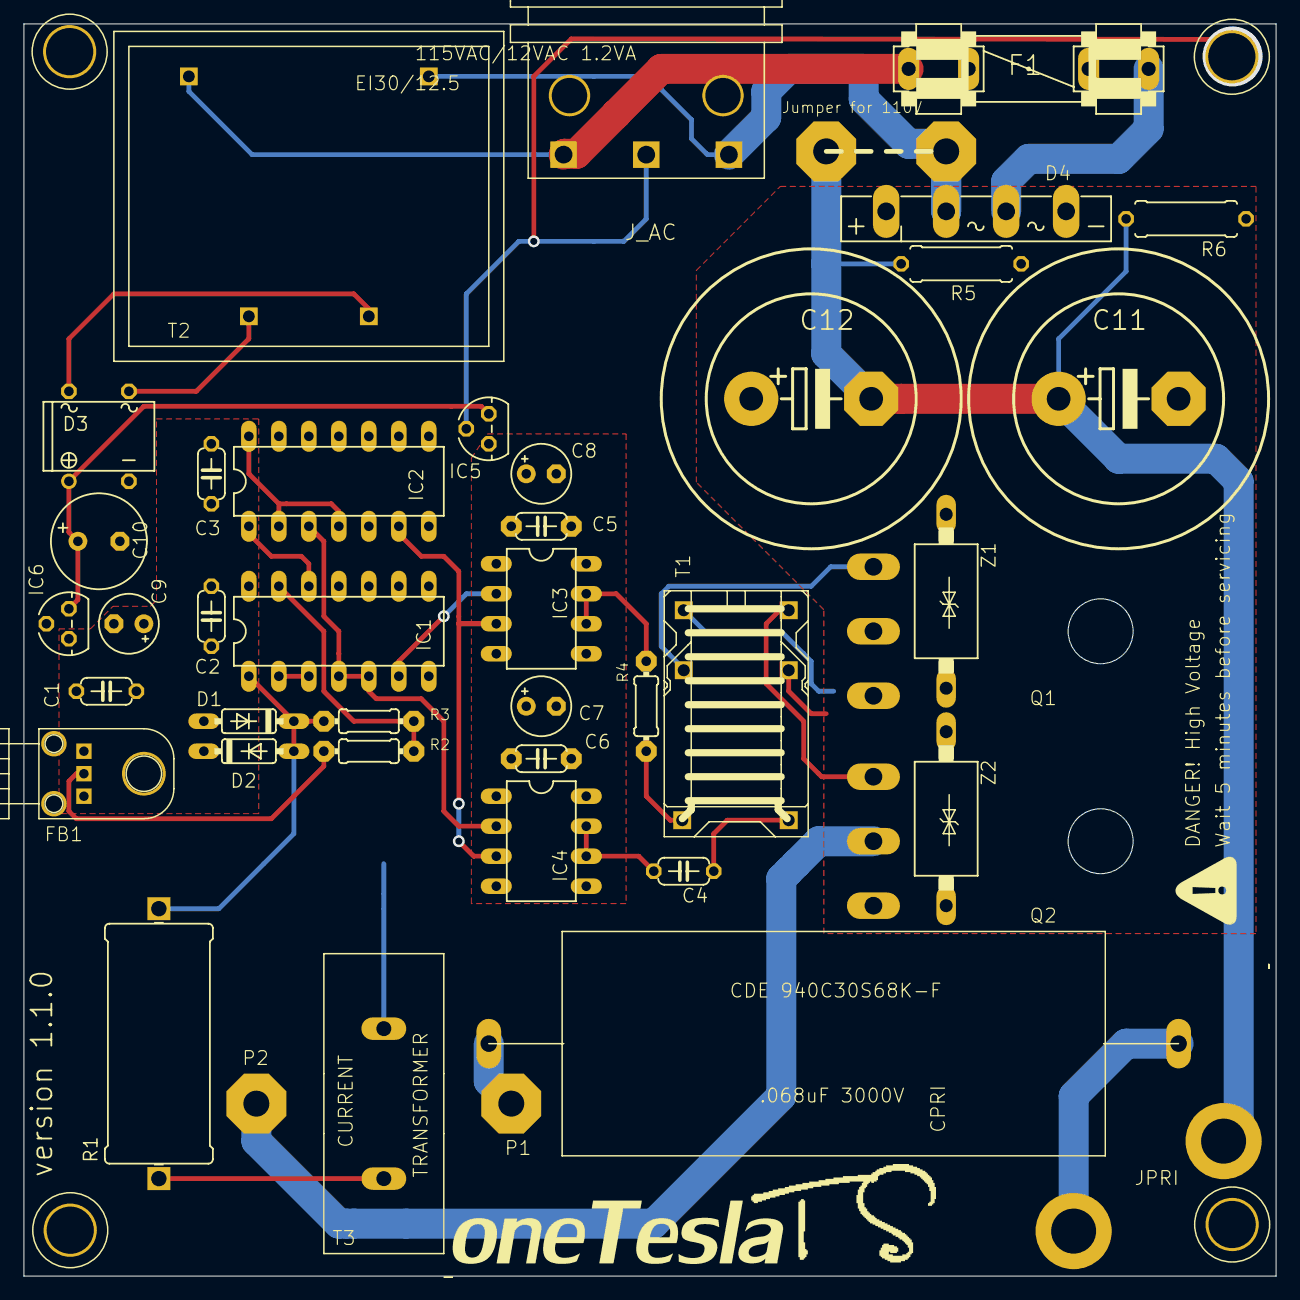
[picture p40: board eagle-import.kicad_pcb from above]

Board: 4 copper layers, 106.0 x 106.0 mm, 53 parts (0 on the bottom side), 29 nets.

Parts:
B1: GBU4S
C1, C2, C3, C4: 1u; C050-024X044@1
C5, C6: 1u; C050-024X044
C7, C8: 100u; E2,5-5
C9: E2,5-5
C10: 680u; E3,5-8
C11, C12: 1000u; EB25D
CPRI0: CDE940
D1, D2: 1N4148DO35-7; DO35-7
D3: B-DIL
F1: FUSE1
IC1: 74HCT14; DIL14
IC2: 74HCT74; DIL14
IC3, IC4: DIL08
IC5: 7815L; TO92
IC6: 7805L; TO92
P1, P2, P3, P4: 12AWG_PAD
R1: 1k; 0922_22
R2: 1k; 0204_7
R3: 10k; 0204_7
R4: 3.3; 0204_7
R5, R6: 100k; 0309_10
T1: P0584
U$1: LOGO
U$2: TRIAD_CT; CT2
U$3: WARNING
U$4: TS-LOGO; TSLOGO
U$5: 2STANDOFFS
U$6: IF-D95; IFD95
U$7, U$8: FGA60N65SMD; TO247H
U$9: EI30; EL30
U$10: IEC320/C6; IEC320_C6
U$12, U$13, U$14, U$15: STANDOFF-QTR; STANDOFF
UNK_HOLE_0: dummyfp0
UNK_HOLE_1: dummyfp1
Z1, Z2: 1.5KE510CA; DO201

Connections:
+5V: C1.2, C2.1, C3.1, C9.+, D2.C, IC1.14, IC2.2, IC2.4, IC2.14, IC6.1, U$6.V+
+15V: C5.1, C6.1, C7.+, C8.+, IC3.1, IC3.8, IC4.1, IC4.8, IC5.1
+24V: C10.+, D3.+, IC5.3, IC6.3
GND: C1.1, C2.2, C3.2, C5.2, C6.2, C7.-, C8.-, C9.-, C10.-, D1.A, D3.-, IC1.7, IC1.9, IC1.11, IC2.7, IC2.10, IC2.11, IC2.12, IC2.13, IC3.4, IC3.5, IC4.4, IC4.5, IC5.2, IC6.2, U$2.P$2, U$6.GND, U$10.G
HOT: F1.2A, U$9.1, U$10.H
N: C11.+, C12.-, P3.P$1, R5.1, R6.2, U$5.P$1
unnamed: R1.1, U$2.P$1
unnamed: T1.7, U$8.G
unnamed: D1.C, D2.A, IC1.1, R1.2, R3.1
unnamed: IC1.6, IC3.2
unnamed: IC1.2, IC1.3
unnamed: IC1.12, IC2.1
unnamed: D3.AC1, U$9.9
unnamed: IC3.6, IC3.7, R4.1
unnamed: C4.2, IC4.6, IC4.7
unnamed: CPRI0.P$1, P1.P$1, P2.P$1, T1.4, U$7.E, U$8.C, Z1.A, Z2.C
unnamed: R2.1, U$6.OUT
unnamed: IC1.13, R2.2, R3.2
unnamed: B1.AC2, F1.1A
unnamed: T1.3, U$7.G
unnamed: IC1.4, IC1.5, IC2.3, IC4.2
unnamed: D3.AC2, U$9.7
unnamed: CPRI0.P$2, U$5.P$2
unnamed: R4.2, T1.1
unnamed: C4.1, T1.10
unnamed: IC2.6, IC3.3, IC4.3
NEG: B1.-, C11.-, R6.1, T1.8, U$8.E, Z2.A
NTRL: B1.AC1, P4.P$1, U$9.5, U$10.N
POS: B1.+, C12.+, R5.2, U$7.C, Z1.C

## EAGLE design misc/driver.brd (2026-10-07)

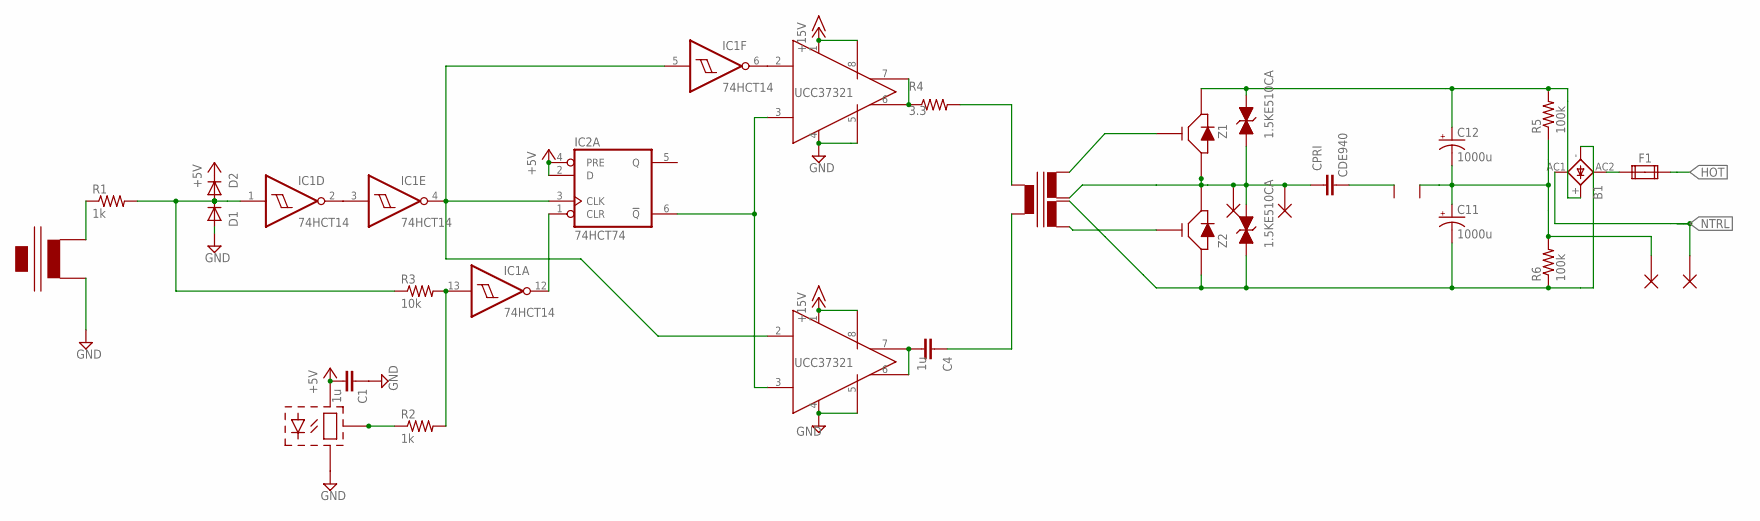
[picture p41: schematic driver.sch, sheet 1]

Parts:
B1: GBU4; GBU4S
C1, C4: 1u; C050-024X044@1
C11, C12: 1000u; EB25D
CPRI: CDE940
D1, D2: 1N4148DO35-7; DO35-7
F1: FUSE2P; FUSE1
IC1: 74HCT14; DIL14
IC2: 74HCT74; DIL14
IC3, IC4: UCC37321DIL8; DIL08
P1, P2, P3, P4: 12AWG_PAD
R1: 1k; 0922/22
R2: 1k; 0204/7
R3: 10k; 0204/7
R4: 3.3; 0204/7
R5, R6: 100k; 0309/10
T1: P0584
U$2: TRIAD_CT; CT2
U$5: 2STANDOFFS
U$6: IF-D95; IFD95
U$7, U$8: FGA60N65SMD; TO247H
Z1, Z2: 1.5KE510CA; DO201

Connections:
+5V: C1.2, D2.C, IC2.2 (D), IC2.4 (PRE), U$6.V+ (VCC); also elsewhere on the board
+15V: IC3.1 (1_VDD), IC3.8 (8_VDD), IC4.1 (1_VDD), IC4.8 (8_VDD); also elsewhere on the board
GND: C1.1, D1.A, IC3.4 (4_AGND), IC3.5 (5_PGND), IC4.4 (4_AGND), IC4.5 (5_PGND), U$2.P$2, U$6.GND; also elsewhere on the board
HOT: F1.2A; also elsewhere on the board
N: C11.+, C12.-, P3.P$1, R5.1, R6.2, U$5.P$1
unnamed: R1.1, U$2.P$1
unnamed: T1.7 (SEC2B), U$8.G
unnamed: D1.C, D2.A, IC1.1 (I), R1.2, R3.1
unnamed: IC1.6 (O), IC3.2 (2_IN)
unnamed: IC1.2 (O), IC1.3 (I)
unnamed: IC1.12 (O), IC2.1 (CLR)
unnamed: IC3.6 (6_OUT), IC3.7 (7_OUT), R4.1
unnamed: C4.2, IC4.6 (6_OUT), IC4.7 (7_OUT)
unnamed: CPRI.P$1 (1), P1.P$1, P2.P$1, T1.4 (SEC1B), U$7.E, U$8.C, Z1.A, Z2.C
unnamed: R2.1, U$6.OUT
unnamed: IC1.13 (I), R2.2, R3.2
unnamed: B1.AC2 (AC1), F1.1A
unnamed: T1.3 (SEC1A), U$7.G
unnamed: IC1.4 (O), IC1.5 (I), IC2.3 (CLK), IC4.2 (2_IN)
unnamed: CPRI.P$2 (2), U$5.P$2
unnamed: R4.2, T1.1 (PRIA)
unnamed: C4.1, T1.10 (PRIB)
unnamed: IC2.6 (!Q), IC3.3 (3_ENBL), IC4.3 (3_ENBL)
NEG: B1.-, C11.-, R6.1, T1.8 (SEC2A), U$8.E, Z2.A
NTRL: B1.AC1 (AC2), P4.P$1; also elsewhere on the board
POS: B1.+, C12.+, R5.2, U$7.C, Z1.C

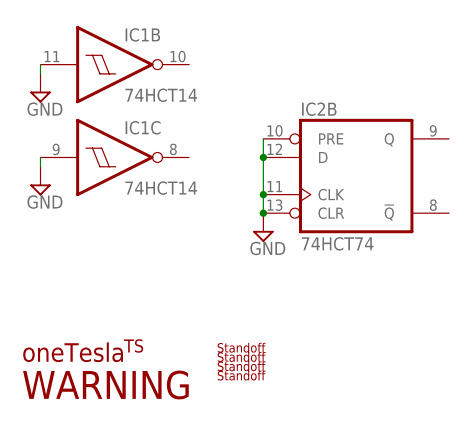
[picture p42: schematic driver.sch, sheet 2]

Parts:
IC1: 74HCT14; DIL14
IC2: 74HCT74; DIL14
U$1: LOGO
U$3: WARNING
U$4: TS-LOGO; TSLOGO
U$12, U$13, U$14, U$15: STANDOFF-QTR; STANDOFF

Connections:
GND: IC1.9 (I), IC1.11 (I), IC2.10 (PRE), IC2.11 (CLK), IC2.12 (D), IC2.13 (CLR); also elsewhere on the board

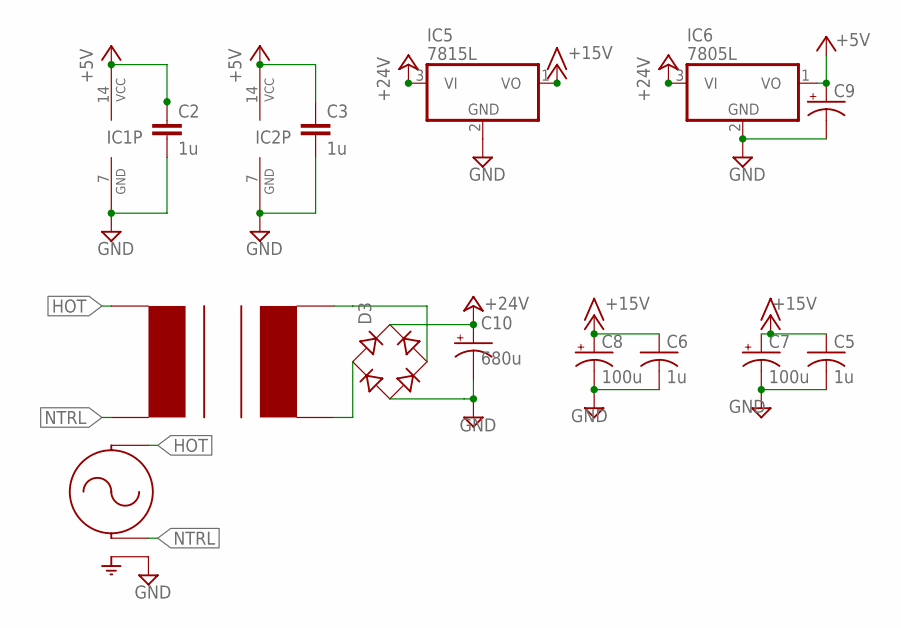
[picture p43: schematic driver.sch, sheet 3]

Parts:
C2, C3: 1u; C050-024X044@1
C5, C6: 1u; C050-024X044
C7, C8: 100u; E2,5-5
C9: CPOL-USE2.5-5; E2,5-5
C10: 680u; E3,5-8
D3: B-DIL
IC1: 74HCT14; DIL14
IC2: 74HCT74; DIL14
IC5: 7815L; TO92
IC6: 7805L; TO92
U$9: EI30; EL30
U$10: IEC320/C6

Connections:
+5V: C2.1, C3.1, C9.+, IC1.14 (VCC), IC2.14 (VCC), IC6.1 (VO); also elsewhere on the board
+15V: C5.1, C6.1, C7.+, C8.+, IC5.1 (VO); also elsewhere on the board
+24V: C10.+, D3.+, IC5.3 (VI), IC6.3 (VI)
GND: C2.2, C3.2, C5.2, C6.2, C7.-, C8.-, C9.-, C10.-, D3.-, IC1.7 (GND), IC2.7 (GND), IC5.2 (GND), IC6.2 (GND), U$10.G; also elsewhere on the board
HOT: U$9.1, U$10.H; also elsewhere on the board
unnamed: D3.AC1, U$9.9
unnamed: D3.AC2, U$9.7
NTRL: U$9.5, U$10.N; also elsewhere on the board

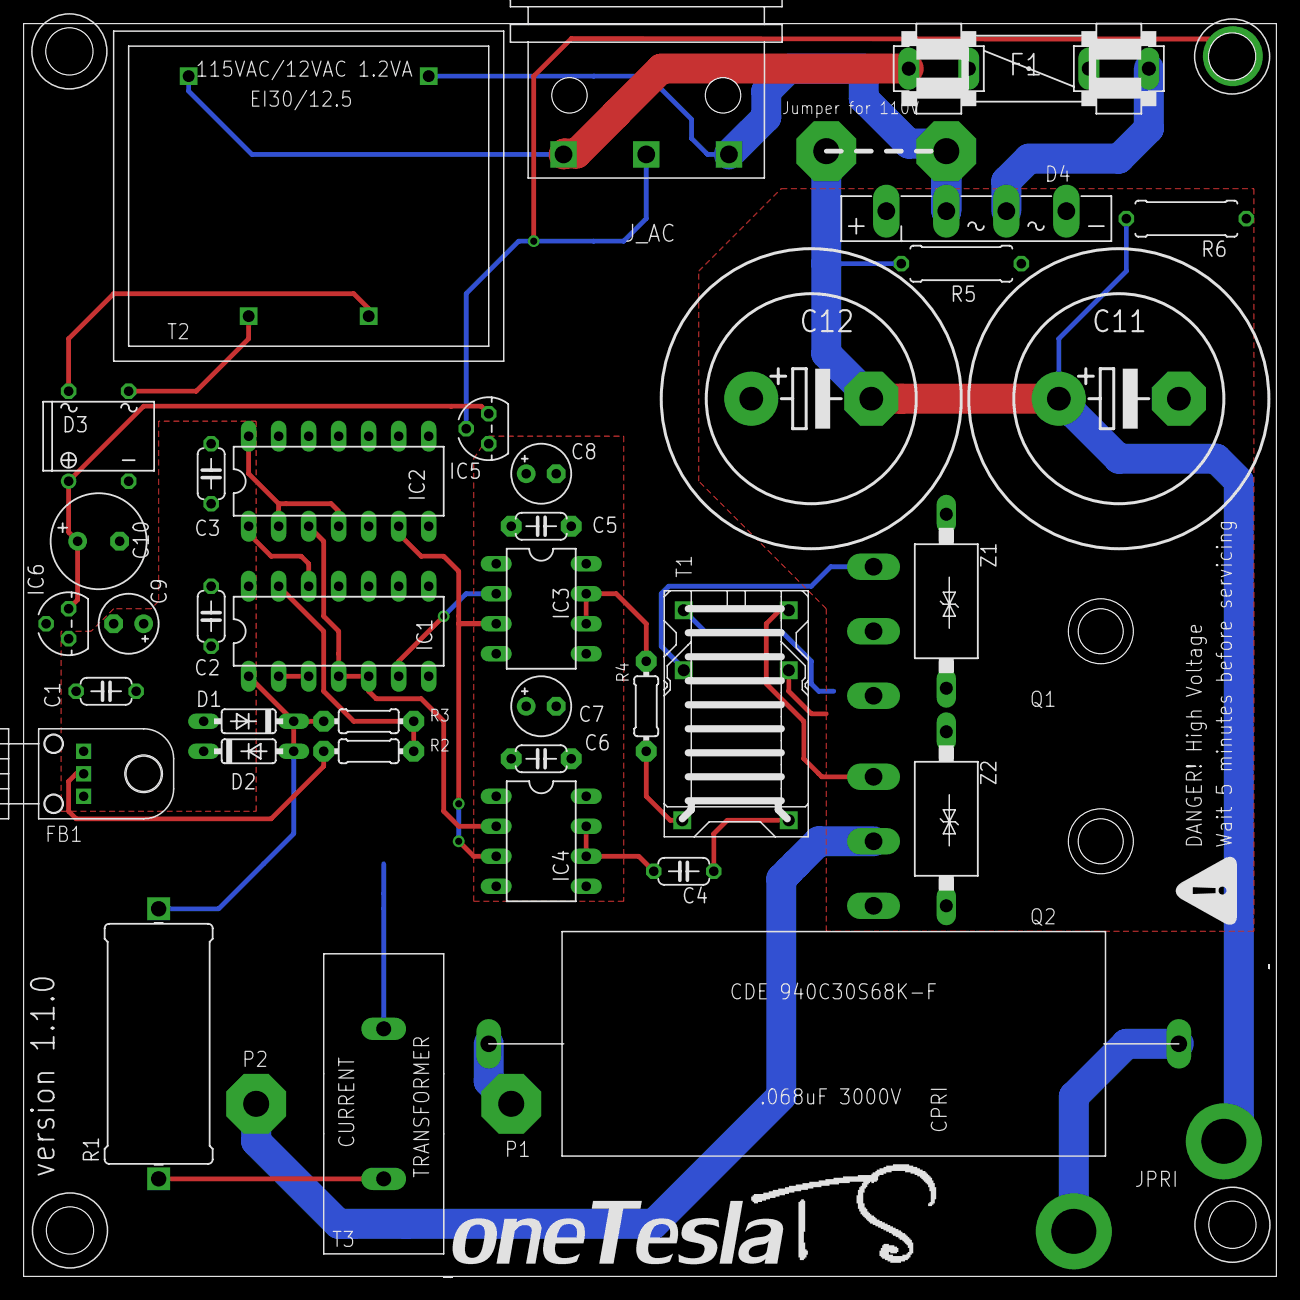
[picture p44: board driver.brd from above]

Board: 3 copper layers, 106.0 x 106.0 mm, 51 parts (0 on the bottom side), 29 nets.

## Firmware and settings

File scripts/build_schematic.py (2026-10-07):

"""Rebuild the oneTeslaTS main board from the supplied schematic and manual.
Run from the project root. Uses only Python's standard library and installed KiCad assets.
"""
from pathlib import Path
from copy import deepcopy
import math,uuid,csv
from sexpr import Atom as A, parse,dump,child,children,prop
ROOT=Path(__file__).resolve().parents[1]
SHARED=Path('/Applications/KiCad/KiCad.app/Contents/SharedSupport')
LIB=ROOT/'library/oneTesla.kicad_sym'
existing=parse(LIB.read_text())
orig={s[1]:s for s in children(existing,'symbol')}
uid=lambda:str(uuid.uuid4())
def E(k,*xs):return [A(k),*[A(str(x)) if not isinstance(x,(list,str)) else x for x in xs]]
def N(k,*xs):return [A(k),*[A(str(x)) for x in xs]]
def effects(size=1.27,justify=None):
 e=E('effects',E('font',N('size',size,size)))
 if justify:e.append(N('justify',*justify.split()))
 return e
def property_(key,value,x=0,y=0,hide=False,justify=None,size=1.27):
 p=E('property',key,value,N('at',x,y,0),effects(size,justify))
 if hide:p.append(N('hide','yes'))
 return p
cache={}
def standard(lib,name):
 if lib not in cache:
  cache[lib]={s[1]:s for s in children(parse((SHARED/'symbols'/(lib+'.kicad_sym')).read_text()),'symbol')}
 s=deepcopy(cache[lib][name]); ext=child(s,'extends')
 if ext:
  base=standard(lib,ext[1]);s.remove(ext)
  base[1]=name
  for u in children(base,'symbol'):u[1]=u[1].replace(ext[1]+'_',name+'_',1)
  for p in children(s,'property'):
   old=prop(base,p[1])
   if old:base.remove(old)
   base.append(p)
  s=base
 return s
symbols={};footprints={};statuses={}
def register(name,s,fp=None):
 s=deepcopy(s);old=s[1];s[1]=name
 prop(s,'Value')[2]=name
 for u in children(s,'symbol'):u[1]=u[1].replace(old+'_',name+'_',1)
 if fp is not None:prop(s,'Footprint')[2]=fp
 symbols[name]=s
 return name
def std(name,lib,orig,fp=None):return register(name,standard(lib,orig),fp)
def copyfp(lib,name,status='Pacote padronizado; conferir componente adquirido'):
 src=SHARED/'footprints'/(lib+'.pretty')/(name+'.kicad_mod')
 assert src.exists(),src
 (ROOT/'library/oneTesla.pretty'/src.name).write_text(src.read_text())
 out='oneTesla:'+name;statuses[out]=status
 return out
def customfp(name,pads,w,h,status,origin=(0,0)):
 f=E('footprint',name,N('version',20260206),E('generator','pcbnew'),E('layer','F.Cu'),E('descr',status),N('attr','through_hole'))
 f += [E('property','Reference','REF**',N('at',0,-h/2-2,0),E('layer','F.SilkS'),effects(1)),E('property','Value',name,N('at',0,h/2+2,0),E('layer','F.Fab'),effects(1))]
 for layer,add,width in [('F.SilkS',0,0.15),('F.Fab',0,0.1),('F.CrtYd',0.5,0.05)]:
  xmin,xmax,ymin,ymax=-w/2,w/2,-h/2,h/2
  if layer=='F.CrtYd':
   xmin=min(xmin,*[x-size/2 for _,x,y,drill,size in pads]);xmax=max(xmax,*[x+size/2 for _,x,y,drill,size in pads])
   ymin=min(ymin,*[y-size/2 for _,x,y,drill,size in pads]);ymax=max(ymax,*[y+size/2 for _,x,y,drill,size in pads])
  f.append(E('fp_rect',N('start',xmin-add,ymin-add),N('end',xmax+add,ymax+add),E('stroke',N('width',width),N('type','default')),E('fill',A('none')),E('layer',layer)))
 for num,x,y,drill,size in pads:
  f.append(E('pad',str(num),A('thru_hole'),A('rect' if str(num)=='1' else 'circle'),N('at',x,y),N('size',size,size),N('drill',drill),E('layers','*.Cu','*.Mask')))
 (ROOT/'library/oneTesla.pretty'/(name+'.kicad_mod')).write_text(dump(f)+'\n')
 statuses['oneTesla:'+name]=status
 return 'oneTesla:'+name
def box(name,reference,value,pins,fp='',description='',datasheet='',w=7.62,h=10.16):
 s=E('symbol',name,N('pin_names'),N('exclude_from_sim','no'),N('in_bom','yes'),N('on_board','yes'))
 s += [property_('Reference',reference,0,h+2.54),property_('Value',value,0,h+5.08),property_('Footprint',fp,hide=True),property_('Datasheet',datasheet,hide=True),property_('Description',description,hide=True)]
 u=E('symbol',name+'_0_1',E('rectangle',N('start',-w,h),N('end',w,-h),E('stroke',N('width',0.254),N('type','default')),E('fill',N('type','background'))))
 s.append(u);u=E('symbol',name+'_1_1')
 for num,pname,x,y,ang,ptype in pins:
  u.append(E('pin',A(ptype),A('line'),N('at',x,y,ang),N('length',2.54),E('name',pname,effects(1)),E('number',str(num),effects(1))))
 s.append(u);symbols[name]=s
 return name
DIP14=copyfp('Package_DIP','DIP-14_W7.62mm_Socket_LongPads','DIP-14, passo 2.54 mm, fileiras 7.62 mm: confirmado pelo layout e soquetes do manual')
DIP8=copyfp('Package_DIP','DIP-8_W7.62mm_Socket_LongPads','DIP-8, passo 2.54 mm, fileiras 7.62 mm: confirmado pelo layout e soquetes do manual')
register('74HCT14',orig['74HCT14'],DIP14);register('74HCT74',orig['74HCT74'],DIP14)
box('UCC37321','IC','UCC37321P',[
 (1,'VDD',-5.08,17.78,270,'power_in'),
 (8,'VDD',5.08,17.78,270,'power_in'),
 (2,'IN',-15.24,5.08,0,'input'),
 (3,'EN',-15.24,-5.08,0,'input'),
 (7,'OUT',15.24,2.54,180,'output'),
 (6,'OUT',15.24,-2.54,180,'passive'),
 (4,'AGND',-5.08,-17.78,90,'power_in'),
 (5,'PGND',5.08,-17.78,90,'power_in'),
],DIP8,datasheet=prop(orig['UCC37321'],'Datasheet')[2],w=10.16,h=12.7)
child(symbols['UCC37321'],'pin_names').append(N('offset',1.016))
child(prop(symbols['UCC37321'],'Reference'),'at')[:]=N('at',0,30.48,0)
child(prop(symbols['UCC37321'],'Value'),'at')[:]=N('at',0,27.94,0)
for u in children(symbols['UCC37321'],'symbol'):
 for p in children(u,'pin'):child(p,'length')[1]=A('5.08')
children(symbols['UCC37321'],'symbol')[0].append(E('text','INV',N('at',0,0,0),effects(1.27)))
# OUT6 and OUT7 are two legs of the same physical output stage, explicitly joined per TI.
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

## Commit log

2026-10-07 docs: add DRSSTC CAD review, per-reference coverage and evidence
    [checagem-bibliotecas.csv, cobertura-bibliotecas.csv, cobertura-eagle.csv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]
2026-10-07 docs(schematic): record per-reference review constraints without topology changes
    [oneTesla.kicad_sch]
2026-10-07 fix(footprints): restore HFBR geometry and recenter custom body markings
    [oneTesla.kicad_sch]
2026-10-07 fix(pcb): reroute HFBR and mains hole conflict with verified partial review
    [cobertura-final.csv, interrupted.kicad_pcb]
2026-10-08 fix(pcb): enlarge board and space capacitor bank with verified routing
    [cobertura.csv, oneTesla.kicad_pcb, oneTesla.kicad_sch]
2026-10-08 fix(cad): preserve geometry and document remaining DRC blockers
    [coverage.csv, oneTesla.kicad_pcb, oneTesla.kicad_sch]
2026-10-08 docs(cad): triage remaining DRC interference blockers
2026-10-08 tool(cad): map native DRC interference clusters
2026-10-09 docs(cad): map selected part datasheets and provisional footprints
2026-10-09 cad: document unrouted placement study and native DRC
    [placement-study.kicad_pcb]
2026-10-10 chore: remove duplicate revised schematic, old schematic snapshots and duplicate netlist
    [oneTesla-revisado.kicad_sch, oneTesla.before-compact.kicad_sch, oneTesla.before-replication.kicad_sch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]
2026-10-11 Atualiza esquema, footprints e modelos 3D dos componentes
2026-10-13 cad(library): adiciona footprints SMD/THT e modelos 3D STEP locais
    - Novos footprints: SOIC-14, C 0805/1210, R 1206/2512, R_Uniroyal_HV12_2512,
    R_Bourns_PWR8030, R_Axial_DIN0309 vertical, R_Axial_Vishay_AC05 vertical,
    D_SOD-323, TO-252 (DPAK), CP_Elec_8x10/8x10.5, CP_D25_H45, MountingHole_3.2mm
    - Modelos STEP de catálogo e aproximações Visual_*, com NOTICES
    - Vínculos de modelo 3D atualizados nos footprints existentes
    - Biblioteca de símbolos: IC1/IC2 para SOIC-14
2026-10-13 cad(board): converte ICs e passivos para SMD e reduz contorno para 100x100mm
    - Esquema: IC1/IC2 SOIC-14, desacoplamento 0805, R5/R6 2512,
    D1/D2 1N4148WS SOD-323, IC6 DPAK, C8/C10/C13 CP_Elec_8x10, C9 1210,
    R1 vertical AC05, R2/R3 1206, R4 DIN0207 THT
    - PCB: reposicionamento e roteamento, contorno (31,375;27,05)-(131,375;127,05)mm
    - Valores de referência ocultos na PCB
2026-10-13 docs(implementation): registra estudos de montagem SMD, contorno e modelos 3D
    - Estudos: smd-conversion, decoupling-smd, diodes-1n4148ws, 7805-dpak,
    r5-r6-smd/tht-vertical, r1-vertical, c9-ceramic-1210, capxon, ketuo,
    tht-r1-r4-c10-100uf, board-100x100, board-outline, board-compact,
    corner-holes-current, hide-pcb-values, models3d, autoroute
    - Snapshots before/after, DRC/ERC antes e depois, prévias e fontes
    - README: status atual de montagem e contorno
2026-10-14 cad: amplia jumper 110V e configura regras de fabricacao
2026-10-14 cad: reforca trilhas do driver IC3 e registra revisao do roteamento
2026-10-14 chore: versiona backup automatico do projeto KiCad
2026-10-17 feat: finalize ARCSTRIKE rev 1.2 PCB updates
    Refine copper zones, restore the T3 primary wire jumper, correct FB1 pads and silkscreen, and add plated fuseholder slots. Include validation reports, previews, and revision backups.
2026-10-17 chore: save latest PCB routing and silkscreen edits
2026-10-18 Atualiza footprints dos capacitores e aterramento M3 do controle
2026-10-18 Atualiza PCB e arquivos de produção com revisão final
2026-10-21 Salva revisão DFM, arquivos de fabricação e modelos 3D completos
2026-10-21 Organiza projeto e adiciona case paramétrica com modelos 3D revisados
